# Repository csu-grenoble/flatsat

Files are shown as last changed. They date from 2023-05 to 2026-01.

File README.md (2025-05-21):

# Easy-Space Flatsat  📡 🚀 extensions

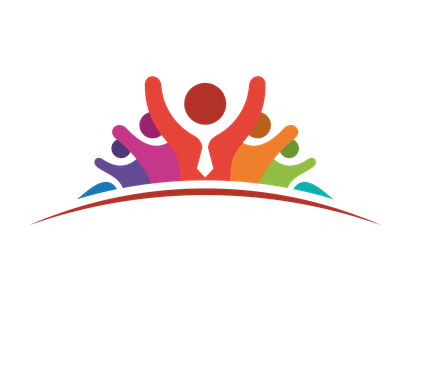
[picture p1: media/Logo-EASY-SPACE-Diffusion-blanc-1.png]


Extensions to [Easy Space](https://www.easy-space.fr/) INISAT flatsat mockup

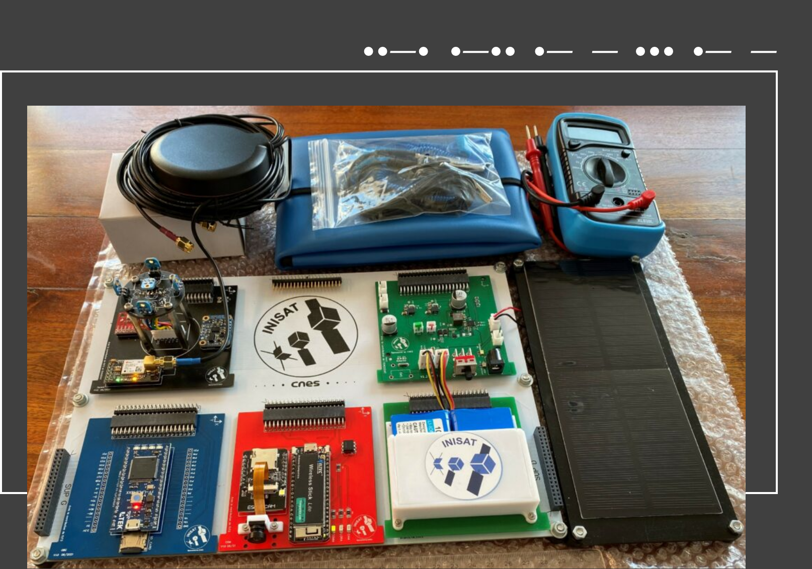
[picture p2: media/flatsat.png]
mockup

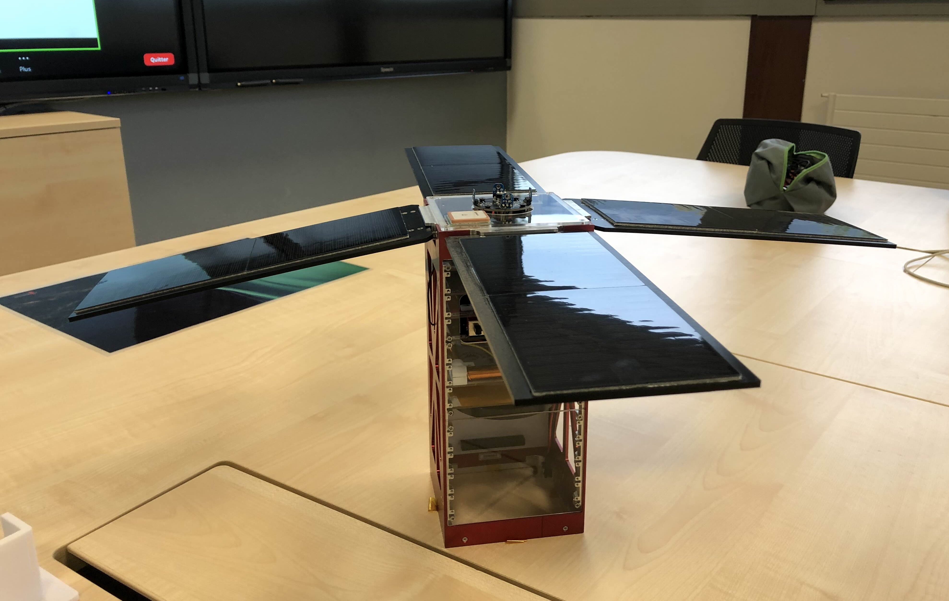
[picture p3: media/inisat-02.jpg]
cubesat 2U


## [Board #1: ThingSat @ INISAT](Hardware/Thingsat_INISAT)  📡 🚀 (OBC + LoRa Gateway + CAN Bus)

* 1x [ST Nucleo L432KC](https://www.st.com/en/evaluation-tools/nucleo-l432kc.html)
* 1x [RAK Wireless RAK5146 (all bands)](https://store.rakwireless.com/products/wislink-concentrator-module-sx1303-rak5146-lorawan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)
* 1x Mikrobus slots for homebrew LoRa click boards (Lambda80, GNSS RTK) or [others click boards](https://www.mikroe.com/shop)
* 3x [Groove connectors](https://wiki.seeedstudio.com/Grove_System/)
* 1x [ST L9616 Automotive High Speed Can Bus Transceiver](https://www.st.com/en/automotive-analog-and-power/l9616.html)
  
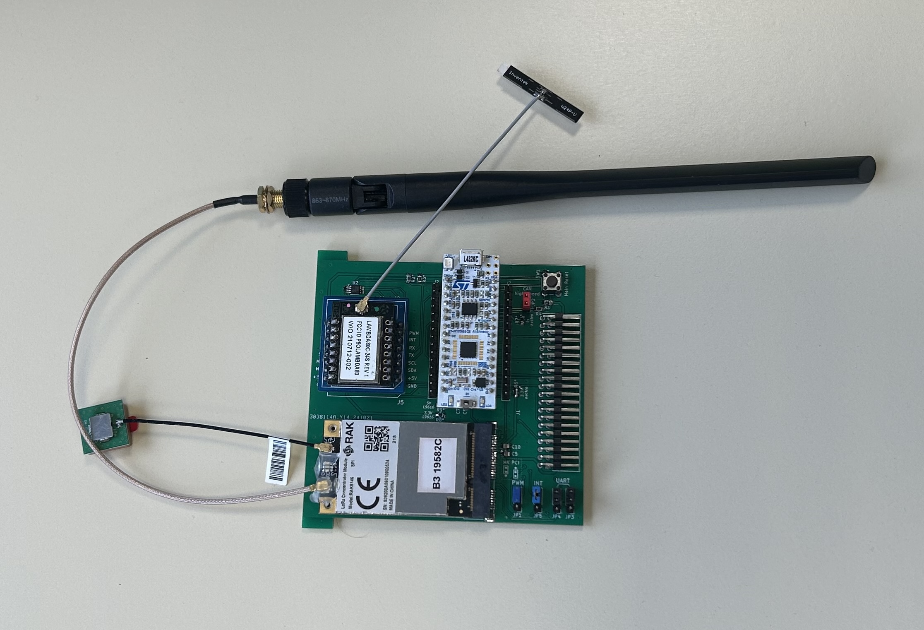
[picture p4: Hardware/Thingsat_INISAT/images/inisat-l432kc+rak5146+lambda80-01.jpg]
OBC + RAK5146 board for INISAT


## [Board #2 ESP32 TinyGS](Hardware/2U-PCB-TinyGS)

* 1x [ESP32 Wroom](https://www.espressif.com/en/products/devkits)
* 2x Mikrobus slots for homebrew LoRa click boards (Lambda80, RN2483) or [others click boards](https://www.mikroe.com/shop)
* 6x [Groove connectors](https://wiki.seeedstudio.com/Grove_System/)
* 1x [ST L9616 Automotive High Speed Can Bus Transceiver](https://www.st.com/en/automotive-analog-and-power/l9616.html)

See [TinyGS 2G4 Station](https://github.com/thingsat/tinygs_2g4station)

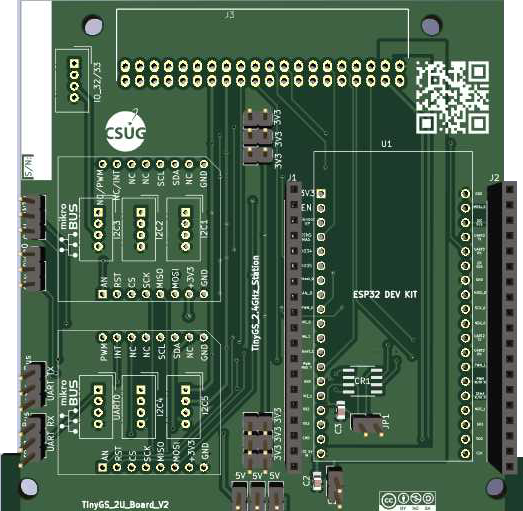
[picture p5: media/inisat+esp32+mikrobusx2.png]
ESP32 Wroom + 2x Mikrobus Slots


## Board #3 Nucleo L476RG

* 1x [Nucleo L476RG](https://www.st.com/en/evaluation-tools/nucleo-l476rg.html)
* 1x [ST L9616 Automotive High Speed Can Bus Transceiver](https://www.st.com/en/automotive-analog-and-power/l9616.html)

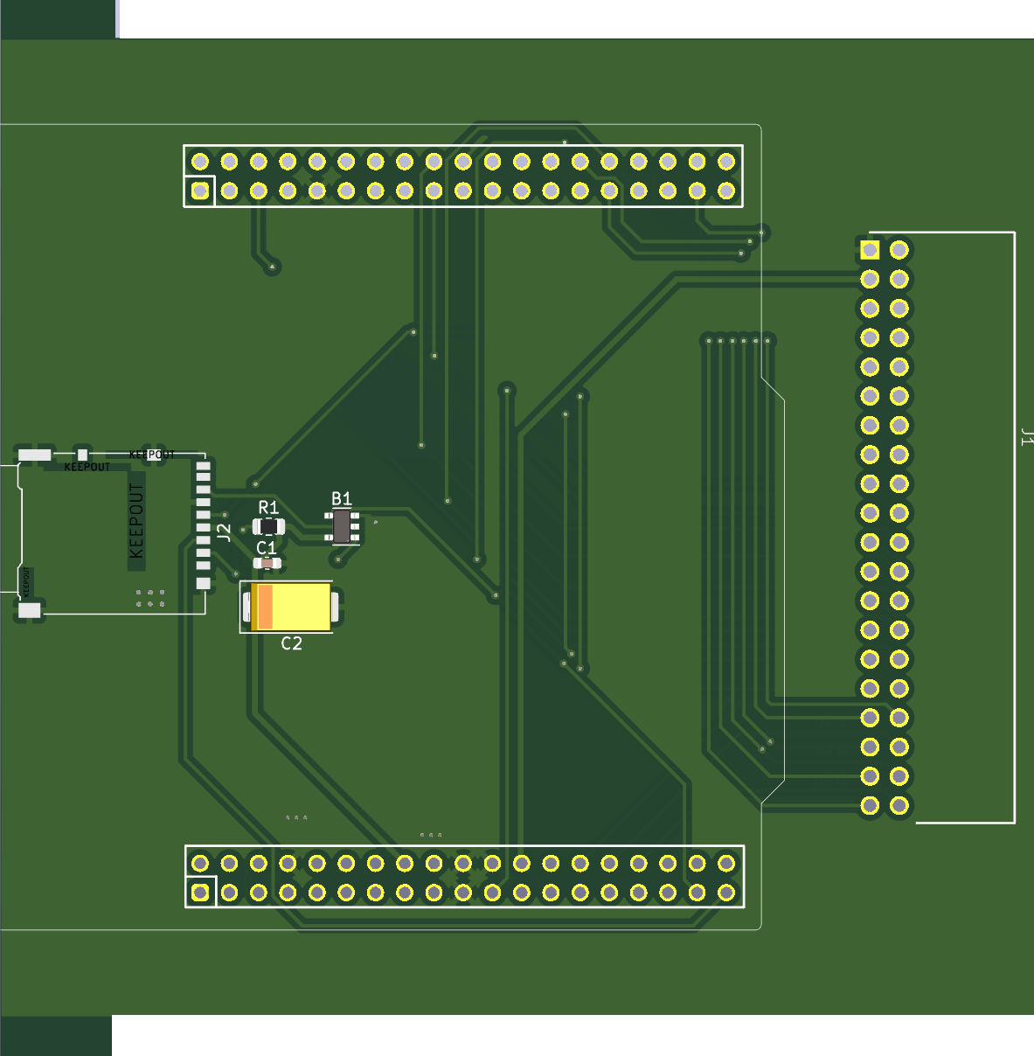
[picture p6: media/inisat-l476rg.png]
OBC


## References

* [EasySpace Diffusion](https://github.com/EasySpace-Diffusion)
* [TinyGS 2G4 Station](https://github.com/thingsat/tinygs_2g4station)

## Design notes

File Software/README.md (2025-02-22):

# Firmwares for INISAT 📡 🚀 boards

## ThingSat @ INISAT 📡 🚀 (Nucleo L432KC + RAK 5146)

* [Arduino](./arduino)
* [MBed](./mbed)
* [STM32 Cube](./cube)
* [RIOT OS](./riot)

## TinyGS

* See [tinygs_2g4station](https://github.com/thingsat/tinygs_2g4station/tree/main/Firmware)

## References

* https://github.com/EasySpace-Diffusion

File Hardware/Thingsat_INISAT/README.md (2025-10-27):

# **Carte Thingsat @ INISAT 📡 🚀 : OBC + Communication avec Nucleo L432KC + Gateway RAK5146**

La carte [Thingsat](https://gricad-gitlab.univ-grenoble-alpes.fr/thingsat/public/-/blob/master/README.md?ref_type=heads) @ INISAT a pour but de fonctionner comme un OBC qui peut se relier à l'environnement INISAT grace au header standardisé. 

Cette carte fonctionne également comme une carte de communication avancée LoRa/FSK avec l'ajout d'un module [gateway LoRa (+ GNSS) au format mini-PCIe](https://www.mikroe.com/mikrobus) comme le module [RAK5146](../../Hardware/sx1302_modules).

> Remarque: D'autres modules gateways LoRa avec ou sans module GNSS sont compatibles avec la carte. Voir la [liste](../../Hardware/sx1302_modules).

Cette carte peut accueillir un module MikroBus qui peut accueillir des platines de l'[écosystème Mikrobus](https://www.mikroe.com/mikrobus).

Cette carte peut accueillir trois platines Grove I2C situés sous le module mini-PCIe .

La carte [Thingsat](https://gricad-gitlab.univ-grenoble-alpes.fr/thingsat/public/-/blob/master/README.md?ref_type=heads) @ INISAT peut être utilisée seule (standalone) pour des expérimentations à bord de [ballons stratosphériques](https://gricad-gitlab.univ-grenoble-alpes.fr/thingsat/public/-/blob/master/balloons/README.md).



## Schématique

[Schematic](schematic.pdf)

## Firmware

Le firmware avec RIOT OS est disponible [ici](../../Software/riot).

Le firmware avec [ici](../../Software/arduino) est à l'étude.

## Montages

La carte peut être montée en deux versions:

**Carte avec 1 connecteur mini-PCI-Express (pour accueillir un concentrateur LoRa) et 1 support Mikrobus**

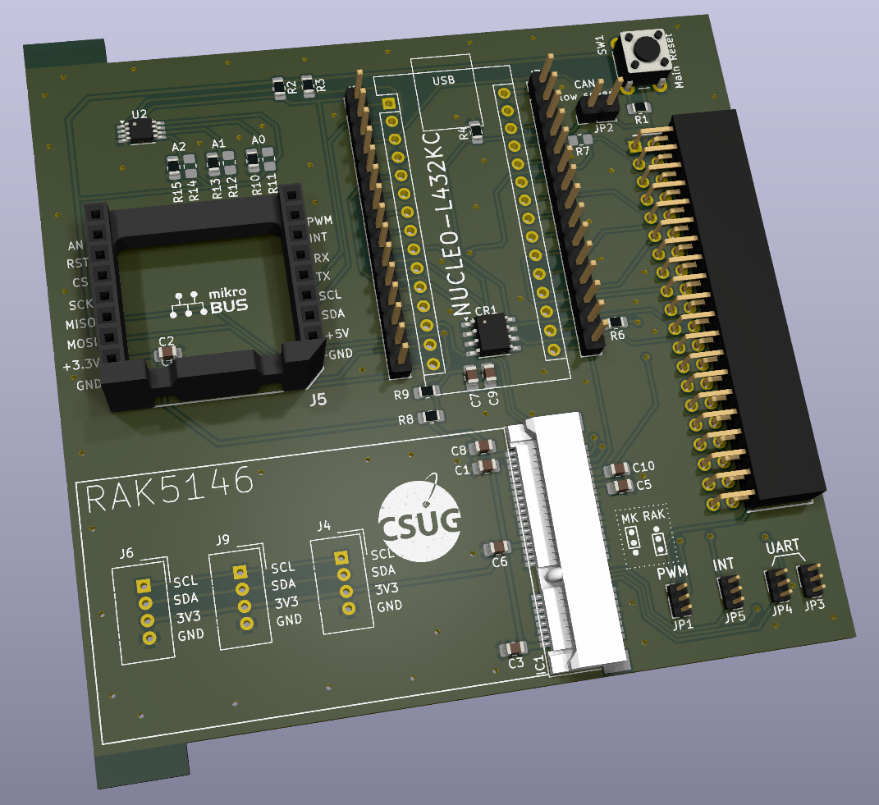
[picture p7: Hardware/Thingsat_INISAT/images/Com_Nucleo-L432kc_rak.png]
Carte Com Nucleo RAK


**Carte avec 3 connecteurs Grove et 1 support Mikrobus**

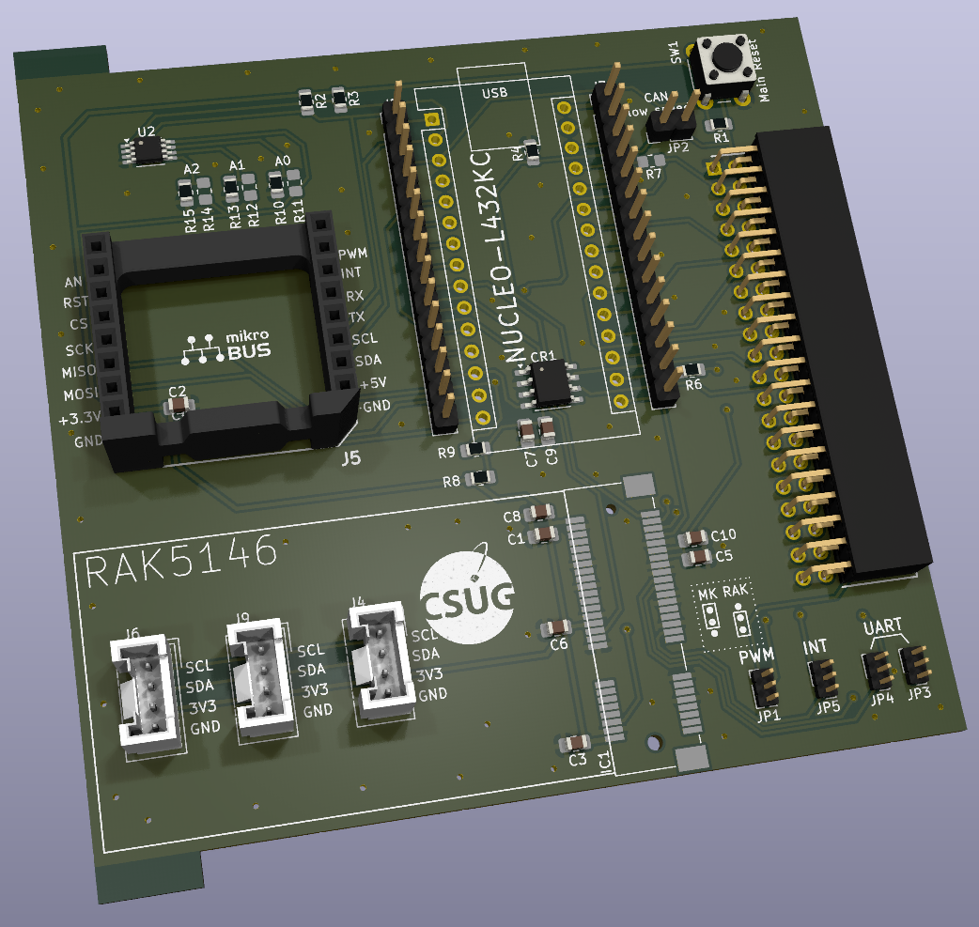
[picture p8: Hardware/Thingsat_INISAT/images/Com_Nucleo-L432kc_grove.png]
Carte Com Nucleo Grove


## OpenLog

Pour journaliser la console d'exécution du firmware de la carte Nucleo L432KC, vous pouvez ajouter une [platine OpenLog](https://github.com/CampusIoT/tutorial/tree/master/openlogger) sur les headers externes de la carte.

| OpenLog | Nucleo L432KC |
| --- | --- |
| `3V3` | `3V3` (et non `VIN`) |
| `GND` | `GND` |
| `RXI` | `A7` (aka `UART2_TX`) | 

> NB: il est recommandé que le port console soit configuré à 9600 bauds pour éviter la perte de caratères lors de l'écriture sur la carte SD. Pour les firmwares avec RIOT OS, il faut redéfinir dans le Makefile `STDIO_UART_BAUDRATE` avec `CFLAGS += -DSTDIO_UART_BAUDRATE=9600`

## Description de la carte
La carte est equipée de:

 - Un emplacement pour carte **Nucleo-32** (ou arduino nano)
 - Un emplacement **MikroBus**
 - Un connecteur **mini-PCI-Express** OU 3 connecteurs **Grove** I2C (en fonction de la version de la carte)
 - Un connecteur **Inisat** (pour se raccorder aux autres cartes de l'ecosystème Inisat)
 - Un **transceiver CAN** ([L9616](https://www.st.com/en/automotive-analog-and-power/l9616.html) - STMicroelectronics)
 - Un **capteur de température** I2C ([MCP9808](https://www.microchip.com/en-us/product/mcp9808#document-table) - Microchip)

## Nucleo 32 (L432KC)

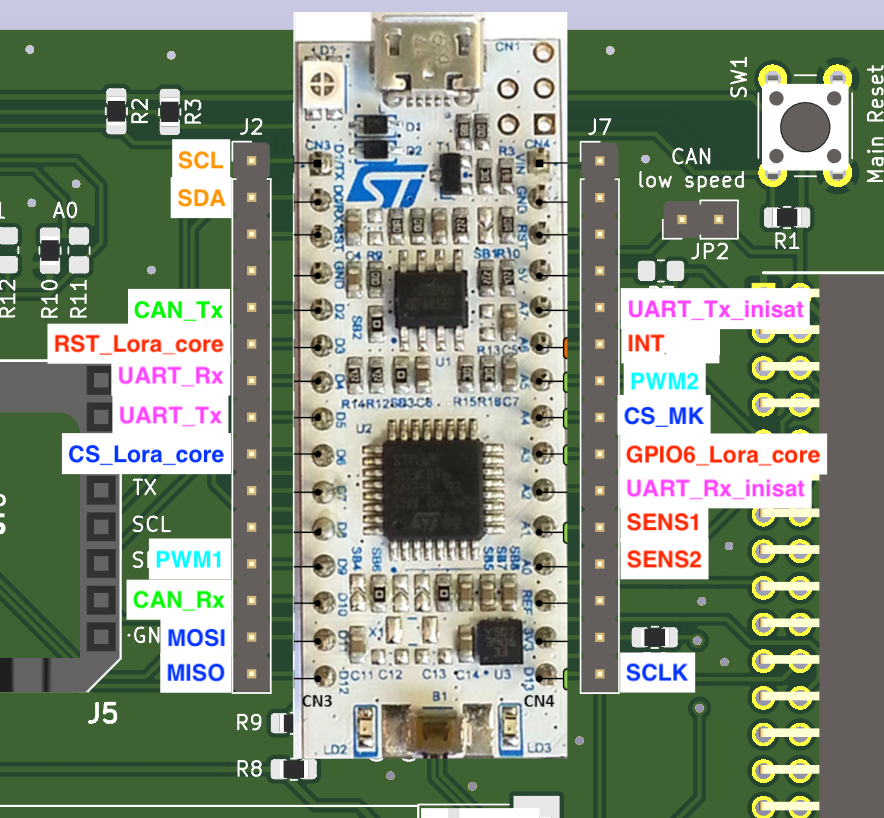
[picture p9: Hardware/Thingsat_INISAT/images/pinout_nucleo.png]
pinout nucleo


## Emplacement MikroBus

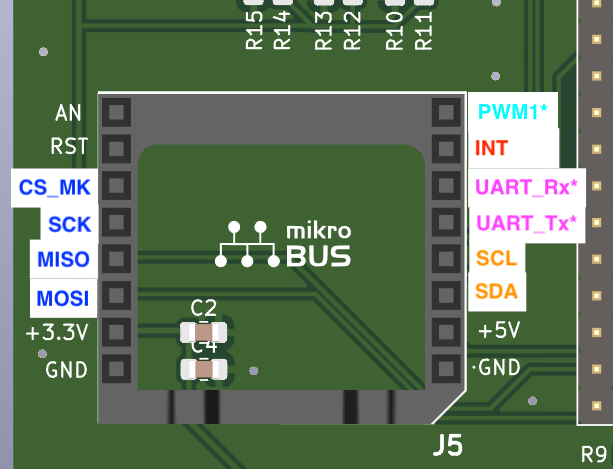
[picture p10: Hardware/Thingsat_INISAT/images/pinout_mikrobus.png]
pinout Mikrobus


## Connecteur mini PCI Express

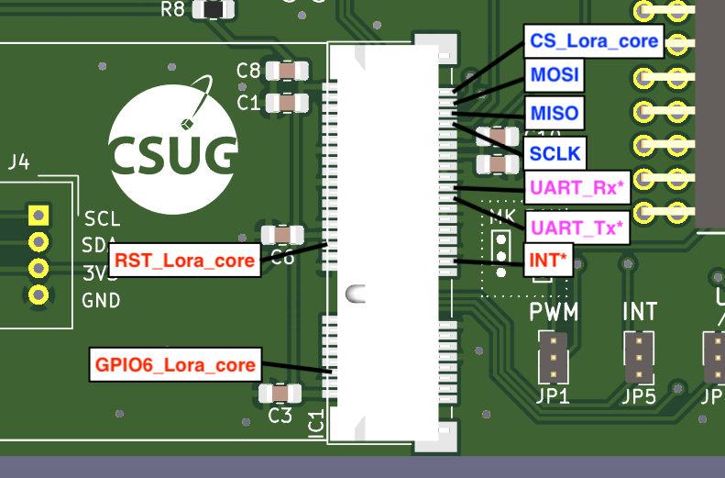
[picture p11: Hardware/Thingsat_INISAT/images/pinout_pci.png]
pinout PCI


## [Modules SX1302/3 compatibles](../sx1302_modules)

* [x] RAK5146 Gateway Concentrator Module for LoRaWAN SPI
* [ ] RAK2287 WisLink LPWAN Concentrator SPI (to test)
* [x] Nebra NBR-0094
* [x] Seeedstudio Wio-WM1303 Long Range Gateway Module
* [ ] Seeedstudio Wio-WM1302 Long Range Gateway Module  (to test)
* [ ] Heltec HT1303  (to test)

## Jumpers de selection des signaux

Les signaux marqués d'une étoile sur les diagrammes sont partagées entre plusieurs empreintes.
Pour pouvoir utiliser ces signaux il faut donc les "router" vers l'emplacement dont on veut se servir en plaçant correctement les jumpers en bas à droite de la carte.

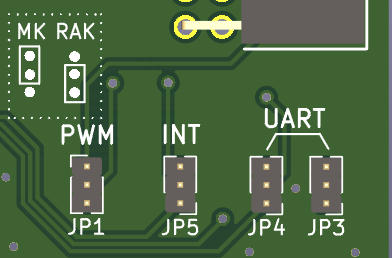
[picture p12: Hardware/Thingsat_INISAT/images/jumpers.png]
Selection jumpers


- PWM1 : 
	- position haute: `PWM Mikrobus` 	(pin 8 de l'empreinte Mikrobus)
	- position basse: `PWM Inisat` 		(pin 6 du connecteur Inisat)
	
- INT :
	- position haute: `INT Mikrobus` 	(pin 7 de l'empreinte Mikrobus)
	- position basse: `PPS Lora core` 	(pin 19 du connecteur mini PCI Express)
	
- UART (Rx et Tx) :
	- position haute: `UART Mikrobus` 	(pin 5 et 6 de l'empreinte Mikrobus)
	- position basse: `UART GPS Lora core` (pin 31 et 33 du connecteur mini PCI Express)

## Transceiver CAN

Le transceiver CAN peut être configuré pour opérations à hautes vitesses (> 250KBaud/s) ou à basse vitesse (< 250KBaud/s).
Pour positionner le transceiver en mode haute vitesse, il faut placer un jumper sur le connecteur `JP2`.

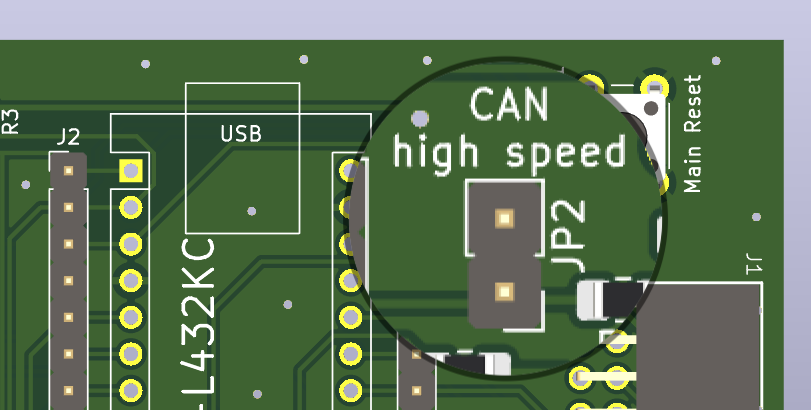
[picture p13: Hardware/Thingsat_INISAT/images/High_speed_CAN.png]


## Capteur de temperature [MPC9808](https://www.microchip.com/en-us/product/mcp9808#document-table)

L'adresse i2c du capteur de température est définie comme suit : `0b 0 0 1 1 A2 A1 A0`
les bits de poids faibles A2,A1 et A0 sont définis en plaçant des résistances 0 Ohms (_il ne faut donc placer qu'une seule résistance pour chaque bit_): 
 
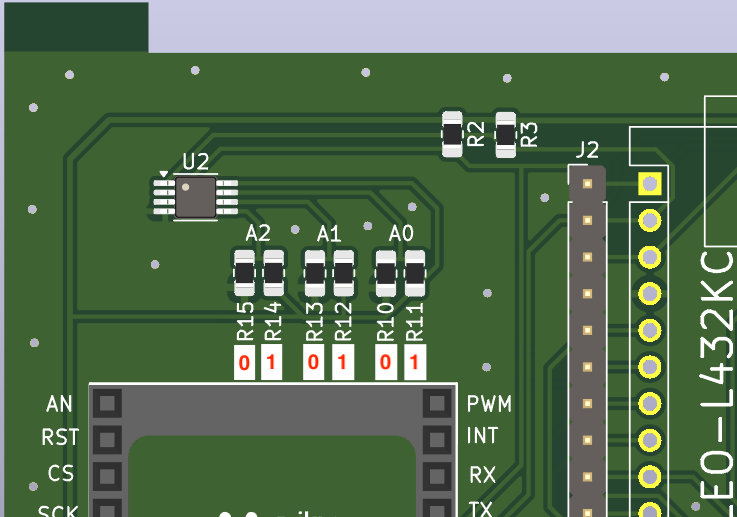
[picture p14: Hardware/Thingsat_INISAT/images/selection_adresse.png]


## Modularité de la carte

Les composants entourés d'un rectangle en pointillé ne doivent pas necessairement être montées. Cela dépend de l'usage de la carte. Voici les composants concernés:

* Alimentation Nucleo
	* `R7`: alimentation de la nucleo en 5V (_nécessaire si la carte Inisat est utilisé seule **ET** que l'on a besoin d'utiliser le 5V pour le Mikrobus_)
	* `R6`: alimentation de la nucleo en 3.3V (_nécessaire si la carte Inisat est utilisé seule_)
* Alimentation Transceiver CAN
	* `R9`: alimentation L9616 en 5V
	* `R8`: alimentation L9616 en 3.3V (_par défaut_)
* Selection adresse i2c capteur de temperature (`R10`-`R15`)
	* [voir ci-dessus](#capteur-de-temperature)

# Contributeurs

* Léo CORDIER (Design PCB + montage)
* Vincent Grennerat (Design PCB)
* Didier Donsez (firmware de test)
* [Lucas ORLANDO BERNARDES](https://www.linkedin.com/in/lucas-orlando-bernardes-1b7397256/) (initial design)

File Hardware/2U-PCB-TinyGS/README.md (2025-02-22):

# INISAT Board for TinyGS 2.4GHz Station

This board is the firts version of the [LoRa 2.4GHz gateway](https://github.com/thingsat/tinygs_2g4station) for [TinyGS](https://tinygs.com/).

Contain Schematic and PCB file for ESP32 Vroom + 2 Mikrobus modules + 2 groves connectors (RXTX,I2C).

This Board is designed to support a ESP32 devkitC-V4 and 2 MiKroBus modules. This board is the firts version of the 2.4GHz tinygs ground station gateway and named Board_V2

The purpose of this board is to control mikrobus modules including SX1280 technology that will transmit and receive messages on a 2.4GHz radio frequency. Each module are connected to a ESP32 which will be connected to the wifi.

Mikrobus board is an add-on board socket standard made by [mikroe](https://www.mikroe.com/mikrobus)

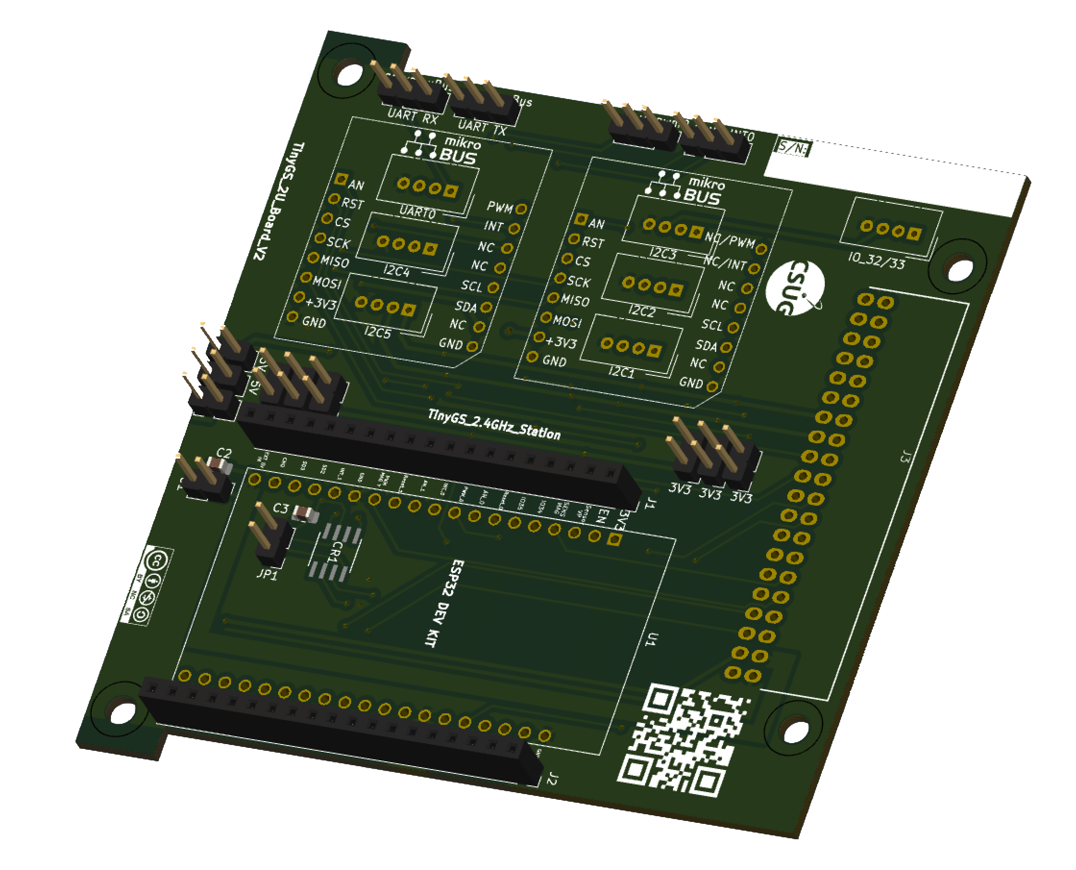
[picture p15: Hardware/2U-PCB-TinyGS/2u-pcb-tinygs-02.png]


## Pinout

Connection between ESP32 - ESP32-DevKitC V4 and Mikrobus modules

MiKroBus 0:
	 				 
	SPI_0:
	CLK 	IO18
	MISO	IO19
	MOSI	IO23
	NSS(CS)	IO05
	
	UART_0	:
	Tx	NC
	Rx	NC
	
	I2C:
	SDA	IO21
	SCL	IO22
	
	AN_0	IO33
	RESET_0 IO32
	PWM_0	IO25
	INT_0	IO26

MiKroBus 1: 				 
	
	SPI_0
	CLK 	IO18
	MISO	IO19
	MOSI	IO23
	NSS 	IO15
	
	UART_2
	Tx	IO17
	Rx	IO16
	
	I2C:
	SDA	IO21
	SCL	IO22
	
	AN_1	IO27
	RESET_1 IO14
	PWM_1	IO04
	INT_1	IO13

Grove connector available on board :

	I2C:			UART_2(Rx/Tx):		GPIO(INPUT Only):
	SDA   IO21		Tx	IO17		IO34
	SCL   IO22		Rx	IO16		IO35

UART_2 can be connected to module MiKroBus 2 or to grove connector. A jumper need to be plug to choose beetween grove output or the mikrobus module.

Two UFL connected to a SMA mount edge connector are available to plug an antenna. They are disconnected from the rest of the board, which allows to connect the module that you want to the antenna, with a SMA -UFL connector.

A powerbank can be plug under the board to supply the 3V. The [powerbank](https://www.amazon.com/Diymore-Lithium-Battery-Charging-Arduino/dp/B07SZKNST4) is design for ESP32 and is purchasable on amazon. 
5V is only available on the Mikrobus 1 module. 

Careful:
* UART0 is used for flashing and debuging. Be very careful to its use.
* GPIO grove connector are INPUT only, ESP32wroom cannot write on this connection.
* Both Chip selec (NSS) for the SPI communication are Pulled HIGH (IO05 & IO15).
* No 5V on Mikrobus 0. 

## Library and footprint

Lib & empreinte folder contains all necessary symbol and footprint for the project:
* ESP32 symbol and footprint. Footprint has been changed to match with our ESP32-devkitC-V4
* Mikrobus (mikroe-2439) symbol and footprint
* Grove connector for I2C and RxTx connection
* SMA and UFL connector

## Files

* .pro: File containing the parameters of the project.
* .sch: Schema files.
* .kicad_pcb: Printed circuit board files.
* sym-info-cache: Library list file (symbol library table): declaration of component symbol libraries available for the schema editor.
* fp-lib-table: Library list file (footprint library table): declaration of component footprint libraries available for the PCB editor.

## Contributors

* Didier DONSEZ
* [Samuel Barnola](https://www.linkedin.com/in/samuel-barnola-816354281/) ([initial design](https://github.com/thingsat/tinygs_2g4station))
* [Lucas ORLANDO BERNARDES](https://www.linkedin.com/in/lucas-orlando-bernardes-1b7397256/)

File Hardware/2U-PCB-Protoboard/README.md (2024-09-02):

# Protoboard for INISAT

Include footprint for SO-8 CAN driver ([ST L9616](https://www.st.com/resource/en/datasheet/l9616.pdf))

See [Protoboard Module Kit](https://www.pumpkinspace.com/store/p50/Protoboard_Module_Kit.html)

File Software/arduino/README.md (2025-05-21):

# Firmwares (skeches) with Arduino IDE

[Getting Started](https://github.com/stm32duino/Arduino_Core_STM32?tab=readme-ov-file#getting-started)

Choose `Tools` > `Board` > `STM32 Boards (selected from submenu` > `Nucleo 32`

Choose  `Tools` > `Board Part Number:` > `Nucleo L432KC`

## GNSS module (UART and I2C)

## Sensors (on Sensors board)

* [Bosch Sensortec BNO055](https://www.bosch-sensortec.com/products/smart-sensor-systems/bno055/) [lib](https://search.arduino.cc/search?q=bno055)
* [NXP MPL3115A2](https://www.nxp.com/docs/en/data-sheet/MPL3115A2.pdf) [lib](https://search.arduino.cc/search?q=MPL3115A2)
* [ADS1015](https://www.ti.com/product/ADS1015) [lib](https://search.arduino.cc/search?q=ADS1015)
* [GNSS uBlox Neo M8N](https://www.u-blox.com/en/product/neo-m8-series) [lib](https://www.arduino.cc/reference/en/libraries/neogps/)

## CAN Bus ([ST L9616 CAN Driver](https://www.st.com/en/automotive-analog-and-power/l9616.html))

* [STM32_CAN](https://www.arduino.cc/reference/en/libraries/stm32_can/)

## LoRa gateway ([RAK5146 SPI + GPS module](https://store.rakwireless.com/products/wislink-concentrator-module-sx1303-rak5146-lorawan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))

* [SX1302 driver](https://github.com/will127534/SX1302_Arduino_Library)

## Utils
* [AioP13 library : "Another implementation of PLAN-13" library)](https://github.com/dl9sec/AioP13)

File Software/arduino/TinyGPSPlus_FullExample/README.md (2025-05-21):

# TinyGPS++ :: Full Example

The purpose of this example is the test of the communication of the ESP32 Wroom with a GPS module using the NMEA 0183 protocol.

This example requires the importation of two libraries into the Arduino IDE
* https://codeload.github.com/plerup/espsoftwareserial/zip/refs/heads/main
* https://codeload.github.com/mikalhart/TinyGPSPlus/zip/refs/heads/master

## Wiring

Warning: The default baudrate for [Grove-GPS](https://wiki.seeedstudio.com/Grove-GPS/) SIM28 is 9600. Check baudrates for [other common GNSS modules](https://github.com/CampusIoT/orbimote/blob/master/gnss_modules.md).

### Wiring for Grove GPS
The example has been tested with the [Grove-GPS](https://wiki.seeedstudio.com/Grove-GPS/) plugged into the UART Grove connector of the TinyGS 2G4 station.

This module is connected to the UART2 with the following wiring:

	White	<->	pin 16	(Rx ESP / Tx Module)
	Yellow 	<->	pin 17  (Tx ESP / Rx Module)
	Red 	<->	3.3V
	Black	<->	GND

### Wiring for XA1110 Mikrobus on Mikrobus 1

The example has been tested with the [SparkFun GPS Breakout - XA1110](https://learn.sparkfun.com/tutorials/sparkfun-gps-breakout---xa1110-qwiic-hookup-guide) plugged into the Mikrobus slot of the Thingsat @ INISAT.

This module is connected to the UART2 with the following wiring:

## Build

Set the baudrate of the module

```c
...
static const uint32_t GPSBaud = 9600;
...
```

Set the coordinates of your POI (Point of Interest)

```c
...
static const double POI_LAT = 45.19262400425433, POI_LON = 5.759966075632675;
...
```

> For debugging baudrate, you can display the raw NMEA sentences by setting `DISPLAY_NMEA0183_SENTENCES` to `1` into the sketch.

```c
...
#define DISPLAY_NMEA0183_SENTENCES    1
...
```

> For removing the GNSS data baudrate, set `DISPLAY_GNSS_LINES` to `0` into the sketch.

```c
...
#define DISPLAY_GNSS_LINES    0
...
```

## Flash and Run

Configure the board `ESP32 Dev Module` and the port in `Tools`.

Compile the sketch `Sketch > Verify/Compile`

Upload the sketch `Sketch > Upload` on the board

Open the serial monitor `Tools > Serial monitor`

with `DISPLAY_NMEA0183_SENTENCES=1`
```
FullExample.ino
An extensive example of many interesting TinyGPS++ features
Testing TinyGPS++ library v. 1.0.2
by Mikal Hart

$PGACK,EPE,H=24.094191,V=17.598621*39
$GNGGA,173207.000,4510.940888,N,00544.128851,E,1,5,2.81,202.417,M,48.532,M,,*41
$GPGSA,A,3,08,02,04,,,,,,,,,,2.98,2.81,1.00*05
$GLGSA,A,3,84,71,,,,,,,,,,,2.98,2.81,1.00*1D
$GPGSV,3,1,11,01,80,008,18,03,66,261,,02,61,104,33,17,35,308,17*78
$GPGSV,3,2,11,08,24,172,23,32,24,045,,04,17,186,30,22,16,291,*76
$GPGSV,3,3,11,14,13,270,,28,10,086,16,31,04,111,*4E
$GLGSV,2,1,08,85,78,042,,70,75,183,,84,33,120,28,69,33,035,*69
$GLGSV,2,2,08,86,29,318,,71,26,204,33,77,07,332,,76,03,290,*6A
$GNRMC,173207.000,A,4510.940888,N,00544.128851,E,0.58,146.63,070425,,,A*78
$GNVTG,146.63,T,,M,0.58,N,1.07,K,A*2E
$PGACK,EPE,H=24.028019,V=17.599386*36
$GNGGA,173208.000,4510.940632,N,00544.129264,E,1,5,2.81,202.387,M,48.532,M,,*42
$GPGSA,A,3,08,02,04,,,,,,,,,,2.98,2.81,1.00*05
$GLGSA,A,3,84,71,,,,,,,,,,,2.98,2.81,1.00*1D
$GNRMC,173208.000,A,4510.940632,N,00544.129264,E,0.78,146.63,070425,,,A*77
$GNVTG,146.63,T,,M,0.78,N,1.45,K,A*2A
```

with `DISPLAY_GNSS_LINES=1`
```
FullExample.ino
An extensive example of many interesting TinyGPS++ features
Testing TinyGPS++ library v. 1.0.2
by Mikal Hart

Sats HDOP  Latitude   Longitude   Fix  Date       Time     Date Alt    Course Speed Card  Distance Course Card  Chars Sentences Checksum
           (deg)      (deg)       Age                      Age  (m)    --- from GPS ----  ----  to POI    ----  RX    RX        Fail
----------------------------------------------------------------------------------------------------------------------------------------
**** ***** ********** *********** **** ********** ******** **** ****** ****** ***** ***   ******** ****** ***   0     0         0        
0    0.0   ********** *********** **** 01/06/2080 00:30:22 394  ****** ****** ***** ***   ******** ****** ***   236   0         0        
...
5    2.8   45.183380  5.735302    559  04/07/2025 17:35:16 559  191.21 146.63 0.43  SSE   2        59.73  ENE   329   2         0        
5    2.8   45.183380  5.735305    215  04/07/2025 17:35:17 215  191.07 146.63 0.46  SSE   2        59.72  ENE   983   4         0        
5    2.8   45.183380  5.735305    562  04/07/2025 17:35:18 562  190.95 146.63 0.26  SSE   2        59.72  ENE   1312  6         0        
5    2.8   45.183384  5.735300    555  04/07/2025 17:35:19 555  190.86 146.63 0.09  SSE   2        59.74  ENE   1641  8         0        
5    2.8   45.183387  5.735298    563  04/07/2025 17:35:20 563  190.77 146.63 0.15  SSE   2        59.75  ENE   1970  10        0        
5    2.8   45.183387  5.735298    563  04/07/2025 17:35:21 563  190.66 146.63 0.30  SSE   2        59.75  ENE   2299  12        0        
5    2.8   45.183387  5.735303    222  04/07/2025 17:35:22 222  190.54 146.63 0.13  SSE   2        59.74  ENE   2955  14        0        
5    2.8   45.183387  5.735305    566  04/07/2025 17:35:23 566  190.44 146.63 0.13  SSE   2        59.74  ENE   3284  16        0        
5    2.8   45.183384  5.735311    569  04/07/2025 17:35:24 569  190.32 146.63 0.13  SSE   2        59.72  ENE   3613  18        0        
5    2.8   45.183380  5.735319    569  04/07/2025 17:35:25 569  190.20 146.63 0.22  SSE   2        59.71  ENE   3942  20        0        
```

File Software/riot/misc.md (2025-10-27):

# INISAT Nucleo L432KC + RAK 5146 :: Misc

## ADC channels : VBat and TS

* https://community.st.com/t5/stm32-mcus-products/adc-is-weird-too/td-p/120816

* https://doc.riot-os.org/group__drivers__periph__vbat.html

## NanoPB

## [AioP13 library : "Another implementation of PLAN-13" library]

cd ~/thingsat/riot_modules/modules/aiop13

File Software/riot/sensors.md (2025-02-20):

# INISAT Nucleo L432KC + RAK 5146 :: Sensors

[Installation et configuration](install.md)

## I2C Scan

```bash

```

## SAUL

```bash

```

## [MPC9808](https://www.microchip.com/en-us/product/mcp9808#document-table) temperature sensor (on board)

## [ADS1115](https://www.ti.com/product/ADS1115) external

[driver](https://doc.riot-os.org/group__drivers__ads101x.html)

```bash

```

## Sensors (on Sensors board) Mikrobus ou Grove

* [Bosch Sensortec BNO055](https://www.bosch-sensortec.com/products/smart-sensor-systems/bno055/) [lib](https://search.arduino.cc/search?q=bno055)
* [NXP MPL3115A2](https://www.nxp.com/docs/en/data-sheet/MPL3115A2.pdf) [driver]([https://search.arduino.cc/search?q=MPL3115A2](https://doc.riot-os.org/group__drivers__mpl3115a2.html))
* [GNSS uBlox Neo M8N](https://www.u-blox.com/en/product/neo-m8-series) [pkg](https://doc.riot-os.org/group__pkg__minmea.html)

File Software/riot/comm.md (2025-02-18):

# INISAT Nucleo L432KC + RAK 5146 :: Communication

[Installation et configuration](install.md)

## Module gateway LoRa RAK5146

```bash
cd ~/github/thingsat/riot_modules/tests/driver_sx1302
make SX1302_LIB_VERSION=2_1_0 flash term
```

```console
help
lgw
lgw start
lgw eui
lgw listen
lgw bench
lgw bench 10 7 125 8 14 on false 20 2000
```

## Module GNSS de la gateway LoRa RAK5146

TODO

## Module Lambda80 SX1280 LoRa 2.4 GHz

```bash
cd ~/github/thingsat/riot_modules/tests/driver_sx1280
make flash term
```

## CAN Bus ([ST L9616 CAN Driver](https://www.st.com/en/automotive-analog-and-power/l9616.html))

* [conn_can](https://github.com/RIOT-OS/RIOT/tree/master/tests/sys/conn_can)

## LibCSP

TODO

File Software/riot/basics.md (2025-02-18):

# Premiers pas avec la carte INISAT Nucleo L432KC + RAK 5146

Dans ce chapitre, vous apprendrez à utiliser les fonctions de base offertes par RIOT pour la plupart des MCU STM32.

[Installation et configuration](install.md)

## LED
Construisez le firmware avec la commande suivante:
```bash
cd ~/github/RIOT-OS/RIOT/tests/leds
make -j 4
```

## Shell

Construisez le firmware avec la commande suivante:
```bash
cd ~/github/RIOT-OS/RIOT/tests/shell
make -j 4
```

Exercice: la commande `make` affiche les lignes suivantes. A quoi correspondent les [valeurs `text`, `data`, `bss`, `dec` et `hex` ?](https://mirzafahad.github.io/2021-05-08-text-data-bss/)
```
   text	   data	    bss	    dec	    hex	filename
  17124	    132	   1912	  19168	   4ae0	~/github/RIOT-OS/RIOT/tests/shell/bin/nucleo-l432kc/test-shell.elf
```

<details>
<summary>Réponse</summary>
En un mot:
<ul>
<li>‘text’ est votre code et vos constantes (et aussi la table de vecteurs).</li>
<li>‘data’ concerne les variables initialisées. Cela compte à la fois pour la RAM et le FLASH. La valeur initialisée alloue de l'espace dans FLASH qui est ensuite copié de la ROM vers la RAM dans le code de démarrage.</li>
<li>‘bss’ concerne les données non initialisées dans la RAM qui sont initialisées avec zéro dans le code de démarrage.</li>    
</ul>
</details>

Regardez les fichiers produits:
```bash
cat bin/$BOARD/riotbuild/riotbuild.h
ls -al bin/$BOARD
file bin/$BOARD/test-shell.*
```

* Le fichier `.elf` est un fichier binaire contenant le firmware et des informations sur celui-ci. [En savoir plus.](https://gist.github.com/x0nu11byt3/bcb35c3de461e5fb66173071a2379779)
* Le fichier `.bin` est un fichier binaire contenant le firmware qui est écrit dans la mémoire Flash du STM32L151 à l'adresse `0x08000000` par `openocd`.

Chargez le binaire `.bin` dans la mémoire Flash (adresse `0x08000000`) du STM32L151 avec la commande suivante.
```bash
make flash-only
```

> Note: la commande `make -j 4 flash` enchaine les commandes `make -j 4` puis `make flash-only`

<details>
<summary>Console (tio)</summary>
<pre>
main(): This is RIOT! (Version: 2023.07-devel-325-g2863d)
test_shell.
> help
Command          	Description
---------------------------------------
bufsize          	Get the shell's buffer size
start_test       	starts a test
end_test         	ends a test
echo             	prints the input command
empty            	print nothing on command
app_metadata     	Returns application metadata
pm               	interact with layered PM subsystem
ps               	Prints information about running threads.
reboot           	Reboot the node
version          	Prints current RIOT_VERSION
xfa_test1        	xfa test command 1
xfa_test2        	xfa test command 2
> ps
    pid | name             	| state	Q | pri | stack  ( used) ( free) | base addr  | current	 
      - | isr_stack        	| -    	- |   - |	512 (  172) (  340) | 0x20000000 | 0x200001c8
      1 | main             	| running  Q |   7 |   1024 (  536) (  488) | 0x20000398 | 0x2000071c
    	| SUM              	|        	| 	|   1536 (  708) (  828)
> bufsize
60
> pm
Usage:
    pm show: display current blockers for each power mode
    pm set <mode>: manually set power mode (lasts until WFI returns)
    pm block <mode>: manually block power mode
    pm unblock <mode>: manually unblock power mode
    pm off: call pm_off()
> pm show
mode 0 blockers: 1
mode 1 blockers: 2
mode 2 blockers: 0
Lowest allowed mode: 2
> app_metadata
{"cmd": "app_metadata_print_json()"}
{"data": {"APP_NAME": "test-shell"}}
{"data": {"BOARD": "nucleo-l432kc-init"}}
{"data": {"CPU": "stm32"}}
{"data": {"APP_SHELL_FMT": "NONE"}}
{"data": {"MCU": "stm32"}}
{"data": {"OS_VERSION": "2023.07-devel-325-g2863d"}}
{"result": "SUCCESS"}
> ps
	pid | name                 | state    Q | pri | stack  ( used) ( free) | base addr  | current     
	  - | isr_stack            | -        - |   - |    512 (  172) (  340) | 0x20000000 | 0x200001c8
	  1 | main                 | running  Q |   7 |   1024 (  536) (  488) | 0x20000398 | 0x2000071c 
	    | SUM                  |            |     |   1536 (  708) (  828)
> reboot
main(): This is RIOT! (Version: 2023.07-devel-325-g2863d)
test_shell.
>
</pre>
</details>

Exercice: Qu'affiche la commande `ps` ?

<details>
<summary>Réponse</summary>
La commande `ps` affiche les threads qui sont créés. Elle donne les tailles des piles (stack) des threads.

`isr_stack` n'est pas une thread (pas de pid) : `isr_stack` représente la pile d'exécution des traitants d'interuption, timers ...
</details>

Que se passe t'il quand la taille de la pile du thread est sous-dimensionnée ?

Essayez la commande suivante:
```bash
make CFLAGS+=-DTHREAD_STACKSIZE_MAIN=512U flash
```

Que se passe t'il ?

## Erreurs au moment de l'installation

hla_swd
Info : The selected transport took over low-level target control. The results might differ compared to plain JTAG/SWD
Info : clock speed 300 kHz
Info : STLINK V2J16S0 (API v2) VID:PID 0483:3748
Info : Target voltage: 2.926341
Error: init mode failed (unable to connect to the target)

## Ajout d'une commande

Le shell est aisement extensible avec des commandes que vous pouvez écrire.

On peut par exemple ajouter la commande `git` qui affiche des informations sur le dépôt de code ayant servi à la production du firmware.

Ajoutez les lignes suivantes au fichier `main.c` de `~/github/RIOT-OS/RIOT/tests/shell`

```c
...
#include "git_utils.h"
...

static const shell_command_t shell_commands[] = {
  ...
	{ "git", "Get git info", git_cmd },
  ...
```

```bash
cd ~/github/RIOT-OS/RIOT/tests/shell
make -j 4 flash
```

## Timers

Les MCU disposent d'un ou plusieurs périphériques temporisateurs (timers). Les timers de RIOT simplifient leurs usages. Ils peuvent être utilsé pour déclancher une fonction (dite de rappel ou callback en anglais) apres plusieurs micro-secondes ou milli-secondes.

```bash
cd ~/github/RIOT-OS/RIOT/tests/periph/timer_periodic/
make -j 4 flash
```

<details>
<summary>Console (tio)</summary>
<pre>
Help: Press s to start test, r to print it is ready
START
main(): This is RIOT! (Version: 2023.07-devel-325-g2863d)

Running Timer 0 at 1000000 Hz.
One counter cycle is 25000 ticks or 25 ms
Will print 'tick' every cycle.

TEST START
Running iteration 1 of 3
[0] tick
[0] tick
[0] tick
[0] tick
[0] tick
[0] tick
[0] tick
[0] tick
[0] tick
[0] tick
[0] tick
[0] tick

Cycles:
channel 0 = 12	[OK]
Running iteration 2 of 3
[0] tick
[0] tick
[0] tick
[0] tick
[0] tick
[0] tick
[0] tick
[0] tick
[0] tick
[0] tick
[0] tick
[0] tick

Cycles:
channel 0 = 12	[OK]
Running iteration 3 of 3
[0] tick
[0] tick
[0] tick
[0] tick
[0] tick
[0] tick
[0] tick
[0] tick
[0] tick
[0] tick
[0] tick
[0] tick

Cycles:
channel 0 = 12	[OK]
TEST SUCCEEDED
{ "threads": [{ "name": "main", "stack_size": 1536, "stack_used": 412}]}

</pre>
</details>

## Threads

Les threads sont des processus légers partageant le même espace mémoire qui accèdent de manière concurrente mais qui ont chacun une pile privée (stack) dimensionnée en général à la fabrication (build time) du binaire du programme (firmware).

> Note: il convient donc de dimensionner correctement la taille de la pile d'une thread afin d'éviter que le sommet de la pile soit atteint pendant l'exécution.

Les threads permettent de réaliser plusieurs tâches en parellele par le programme. RIOT offre de mécanismes de barrière de concurrence entre les threads (mutex par exemple) et des moyens de communication par message.

```bash
cd ~/github/RIOT-OS/RIOT/tests/shell
make -j 4 flash
```

La commande `ps` du Shell permet de lister les threads courantes dans le programme. `main` correspond à la fonction `main()` qui exécute le Shell et `isr_stack` correspond à la thread qui exécute les traitants des interuptions, timers ... Il faut fréquent ajuster la taille de la pile de `isr_stack` avec `CFLAGS += -DISR_STACKSIZE=2048` par exemple. Idem pour `main` avec `THREAD_STACKSIZE_MAIN`.

<details>
<summary>Console (tio)</summary>
<pre>
main(): This is RIOT! (Version: 2023.07-devel-325-g2863d)
test_shell.
> ps
	pid | name                 | state    Q | pri | stack  ( used) ( free) | base addr  | current     
	  - | isr_stack            | -        - |   - |    512 (  172) (  340) | 0x20000000 | 0x200001c8
	  1 | main                 | running  Q |   7 |   1024 (  536) (  488) | 0x20000398 | 0x2000071c 
	    | SUM                  |            |     |   1536 (  708) (  828)
</pre>
</details>

```bash
cd ~/github/RIOT-OS/RIOT/tests/core/thread_float/
make -j 4 flash
```

<details>
<summary>Console (tio)</summary>
<pre>
> Help: Press s to start test, r to print it is ready
START
main(): This is RIOT! (Version: 2023.07-devel-325-g2863d)
THREADS CREATED

Context switch every 1562 µs
{ "threads": [{ "name": "main", "stack_size": 1536, "stack_used": 388 }]}
THREAD t1 start
THREAD t2 start
THREAD t3 start
t1: 141.443787
t3: 141.466812
t1: 141.443787
t3: 141.466812
t1: 141.443787
t3: 141.466812
t1: 141.443787
t3: 141.466812
t1: 141.443787
t3: 141.466812
t1: 141.443787
t3: 141.466812
t1: 141.443787
t3: 141.466812
t1: 141.443787
</pre>
</details>

```bash
cd ~/github/RIOT-OS/RIOT/tests/core/thread_msg_bus/
make -j 4 flash
```

<details>
<summary>Console (tio)</summary>
<pre>
Help: Press s to start test, r to print it is ready
START
main(): This is RIOT! (Version: 2023.07-devel-325-g2863d)
THREAD 1 start
THREAD 2 start
THREAD 3 start
THREADS CREATED
Posted event 22 to 0 threads
T1 recv: Hello Threads! (type=23) from bus
T3 recv: Hello Threads! (type=23) from bus
Posted event 23 to 2 threads
T1 recv: Hello Threads! (type=24) from bus
T2 recv: Hello Threads! (type=24) from bus
Posted event 24 to 2 threads
Post message to thread 1
T1 recv: Hello Thread 1 (type=4919)
Post shutdown request to all threads
T1 recv: shutdown request (type=0) from bus
{ "threads": [{ "name": "nr1", "stack_size": 1536, "stack_used": 412 }]}
T2 recv: shutdown request (type=0) from bus
{ "threads": [{ "name": "nr2", "stack_size": 1536, "stack_used": 412 }]}
T3 recv: shutdown request (type=0) from bus
{ "threads": [{ "name": "nr3", "stack_size": 1536, "stack_used": 412 }]}
SUCCESS
{ "threads": [{ "name": "main", "stack_size": 1536, "stack_used": 456 }]}
</pre>
</details>

```bash
cd ~/github/RIOT-OS/RIOT/tests/core/thread_cooperation/
make -j 4 flash
```

<details>
<summary>Console (tio)</summary>
<pre>
Help: Press s to start test, r to print it is ready
START
main(): This is RIOT! (Version: 2023.07-devel-325-g2863d)
[START] compute 12! (factorial).
MAIN: create thread, arg: 1
MAIN: msg to T-2
T-02: alive
T-02: got arg 1
MAIN: create thread, arg: 2
MAIN: msg to T-3
T-03: alive
T-03: got arg 2
MAIN: create thread, arg: 3
MAIN: msg to T-4
T-04: alive
T-04: got arg 3
MAIN: create thread, arg: 4
MAIN: msg to T-5
T-05: alive
T-05: got arg 4
MAIN: create thread, arg: 5
MAIN: msg to T-6
T-06: alive
T-06: got arg 5
MAIN: create thread, arg: 6
MAIN: msg to T-7
T-07: alive
T-07: got arg 6
MAIN: create thread, arg: 7
MAIN: msg to T-8
T-08: alive
T-08: got arg 7
MAIN: create thread, arg: 8
MAIN: msg to T-9
T-09: alive
T-09: got arg 8
MAIN: create thread, arg: 9
MAIN: msg to T-10
T-10: alive
T-10: got arg 9
MAIN: create thread, arg: 10
MAIN: msg to T-11
T-11: alive
T-11: got arg 10
MAIN: create thread, arg: 11
MAIN: msg to T-12
T-12: alive
T-12: got arg 11
MAIN: create thread, arg: 12
MAIN: msg to T-13
T-13: alive
T-13: got arg 12
{ "threads": [{ "name": "thread", "stack_size": 1024, "stack_used": 372 }]}
MAIN: reply from T-2
{ "threads": [{ "name": "thread", "stack_size": 1024, "stack_used": 372 }]}
MAIN: reply from T-3
{ "threads": [{ "name": "thread", "stack_size": 1024, "stack_used": 372 }]}
MAIN: reply from T-4
{ "threads": [{ "name": "thread", "stack_size": 1024, "stack_used": 372 }]}
MAIN: reply from T-5
{ "threads": [{ "name": "thread", "stack_size": 1024, "stack_used": 372 }]}
MAIN: reply from T-6
{ "threads": [{ "name": "thread", "stack_size": 1024, "stack_used": 372 }]}
MAIN: reply from T-7
{ "threads": [{ "name": "thread", "stack_size": 1024, "stack_used": 372 }]}
MAIN: reply from T-8
{ "threads": [{ "name": "thread", "stack_size": 1024, "stack_used": 372 }]}
MAIN: reply from T-9
{ "threads": [{ "name": "thread", "stack_size": 1024, "stack_used": 372 }]}
MAIN: reply from T-10
{ "threads": [{ "name": "thread", "stack_size": 1024, "stack_used": 372 }]}
MAIN: reply from T-11
{ "threads": [{ "name": "thread", "stack_size": 1024, "stack_used": 372 }]}
MAIN: reply from T-12
{ "threads": [{ "name": "thread", "stack_size": 1024, "stack_used": 372 }]}
MAIN: reply from T-13
MAIN: 12! = 479001600
[SUCCESS]
{ "threads": [{ "name": "main", "stack_size": 1536, "stack_used": 516 }]}
</pre>
</details>

## Aide au déboggage

TODO

* https://doc.riot-os.org/group__utils.html
* `assert()` et `expect()`
 https://doc.riot-os.org/group__test__utils__expect.html#gadd37fb477fadd68ccc0f938027ba132e

## RTC (Realtime Clock)

La plupart des microcontroleurs possède un périphérique horloge temps-réel (en anglais Realtime Clock, RTC) qui maintient la date et l'heure courante et définir des alarmes tant que le microcontroleur est alimenté. Il est possible de supporter la perte d'alimentation (par exemple, changement de batterie) en ajoutant une pile de secours à cette horloge.

```bash
cd ~/github/RIOT-OS/RIOT/tests/periph/rtc/
make -j 4 flash
```

<details>
<summary>Console (tio)</summary>
<pre>
> Help: Press s to start test, r to print it is ready
START
main(): This is RIOT! (Version: 2023.07-devel-325-g2863d)

RIOT RTC low-level driver test
This test will display 'Alarm!' every 2 seconds for 4 times
RTC mem OK
Clock value is now   2020-01-02 05:58:26
  Setting clock to   2020-02-28 23:59:57
Clock value is now   2020-02-28 23:59:57
  Setting alarm to   2020-02-28 23:59:59
   Alarm is set to   2020-02-28 23:59:59
  Alarm cleared at   2020-02-28 23:59:57
       No alarm at   2020-02-28 23:59:59
  Setting alarm to   2020-02-29 00:00:01

Alarm!
Alarm!
Alarm!
Alarm!
RTC mem OK
{ "threads": [{ "name": "main", "stack_size": 1536, "stack_used": 500 }]}
</pre>
</details>

Modifiez le `Makefile` de l'exemple `shell` pour ajouter:

```makefile
FEATURES_REQUIRED += periph_rtc
FEATURES_OPTIONAL += periph_rtc_ms
FEATURES_OPTIONAL += periph_rtc_mem

DISABLE_MODULE += periph_init_rtc
```

Reflashez la carte avec les commandes suivantes :

```bash
cd ~/github/RIOT-OS/RIOT/tests/sys/shell
make -j 4 flash
```

<details>
<summary>Console (tio)</summary>
<pre>
> help
> rtc
usage: rtc <command> [arguments]
commands:
	poweron		power the interface on
	poweroff	power the interface off
	clearalarm	deactivate the current alarm
	getalarm	print the currently alarm time
	setalarm YYYY-MM-DD HH:MM:SS
			set an alarm for the specified time
	gettime		print the current time
	settime YYYY-MM-DD HH:MM:SS
			set the current time
> rtc gettime
2020-02-29 00:05:33
> rtc settime 2023-11-15 22:00:00
> rtc gettime
2023-11-15 22:00:04
> setalarm 2023-11-15 22:01:00
>
> 
2023-11-15 22:01:00
</pre>
</details>

> A quoi peuvent servir les alarmes de la RTC ?
<details>
<summary>Réponse(s)</summary>
<ul>
<li>A vous réveiller à l'heure le matin</li>
<li>A lancer l'arrossage de votre champs</li> 
<li>A mettre votre bâtiment sous radar</li> 
<li>...</li> 
</ul>
</details>

> Exercice : ajoutez d'une commande `sun` au shell qui calcule les heures de lever et de coucher du soleil.

Vous pouvez vous aider de [ChatGPT](https://chat.openai.com) : Write the C function which computes sunrise time and sunset time for the current position.

## WDT (Watchdog Timer)

Le chien de garde (Watchdog Timer en anglais) est un périphérique qui veille à redémarrer (reboot) le microcontroleur quand le programme a planté (débordement de pile) ou boucle.

```bash
cd ~/github/RIOT-OS/RIOT/tests/periph/wdt
make -j 4 flash
```

`setup 0 10000` fixe le WDG à 10 seconds. Il faut ensuite lancer le watchdog avec la commande `start`. Sans `kick`, il reboote la carte.

<details>
<summary>Console (tio)</summary>
<pre>
This is RIOT! (Version: 2023.07-devel-325-g2863d)
RIOT wdt test application
> help
Command              Description
---------------------------------------
range                Return wdt Timer range
setup                Setup wdt Timer
kick                 Delay wdt timer
start                Start wdt timer
startloop            Start wdt timer, loop print system time
> setup
usage: setup <min_time[ms]> <max_time[ms]>
> setup 0 10000
valid configuration
> start
starting wdt timer
> kick
delaying wdt timer
> kick
delaying wdt timer
> main(): This is RIOT! (Version: 2023.07-devel-325-g2863d)
RIOT wdt test application</pre>
</details>

## EEPROM

L'EEPROM est une (petite) mémoire persistante qui est en général utilisé des paramêtres de personnalisation ou de configuration de l'équipement. 

Le microcontroleur de la carte Nucleo L432KC Base ne dispose pas d'EEPROM. Cependant, une [EEPROM I2C externe](https://www.st.com/en/memories/standard-i2c-eeprom.html) peut être ajoutée sur le PCB de la carte support ou via le commecteur Mikrobus avec la platine [MIKROE-1200](https://www.mikroe.com/eeprom-click).

```bash
cd tests/drivers/at24cxxx
make -j 4 flash
```

<details>
<summary>Console (tio)</summary>
<pre>
> main(): This is RIOT! (Version: 2023.07-devel-325-g2863d)

TODO

</pre>
</details>

> Attention: il faut mieux ne pas stocker des secrets (clés cryptographiques par exemple) dans l'EEPROM : il est préférable d'utiliser la mémoire persistante sécurisée d'un Secure Element (SE) intégré au microcontroleur ou d'un composant externe. Le MCU de la carte L432KC n'est pas doté d'un tel composant SE.

## CPU ID

Chaque MCU STM32 possède un numéro de série unique donnée par le fabricant ST Microelectronic.

```bash
cd ~/github/RIOT-OS/RIOT/tests/periph/cpuid
make -j 4 flash
```

<details>
<summary>Console (tio)</summary>
<pre>
Help: Press s to start test, r to print it is ready
START
main(): This is RIOT! (Version: 2023.07-devel-325-g2863d)
Test for the CPUID driver
This test is reading out the CPUID of the platforms CPU

CPUID_LEN: 12
CPUID: 0x33 0x37 0x47 0x05 0x30 0x37 0x38 0x37 0x00 0x6c 0xa0 0x6e
{ "threads": [{ "name": "main", "stack_size": 1536, "stack_used": 388 }]}
</pre>
</details>

> A quoi peut servir ce `cpuid` ?
<details>
<summary>Réponse(s)</summary>
<ul>
<li>numéro pour la garantie constructeur de l'équipement</li>
<li>numéro d'inventaire de l'équipement chez le propriétaire</li>
<li>lutte contre la contrefaçon</li>
<li>lutter contre le marché gris</li>
<li>...</li>
</ul>
</details>

## Tension de l'alimentation

```bash
cd ~/github/RIOT-OS/RIOT/tests/periph/vbat
make -j 4 flash
```

> Exercice: quel est l'intéret de connaître la tension d'alimentation ?
<details>
<summary>Réponse(s)</summary>
<li>Savoir à quel moment une opération de maintenance doit être planifier pour remplacer la batterie.</li>
</details>

## Extra

* True random number generator
* [STM32 last reset status](../tests/last_reset_status/)
* [STM32 internal temperature](../tests/internal_temperature/)

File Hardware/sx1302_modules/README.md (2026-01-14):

# SX1302 / SX1303 Gateway Modules for [Thingsat @ INISAT 📡 🚀](../Thingsat_INISAT)

This directory has been moved to https://github.com/thingsat/sx1302_modules

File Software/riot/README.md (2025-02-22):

# ThingSat @ INISAT 📡 🚀 (Nucleo L432KC + RAK 5146) :: Firmwares with [RIOT OS](https://github.com/RIOT-OS/RIOT)

* [Installation et configuration](install.md)
* [Fonctionnalités de base de RIOT](basics.md)
* [Communications sur la carte INISAT Nucleo L432KC + RAK 5146](comm.md)
* [Capteurs](sensors.md)
* [Misc](misc.md)


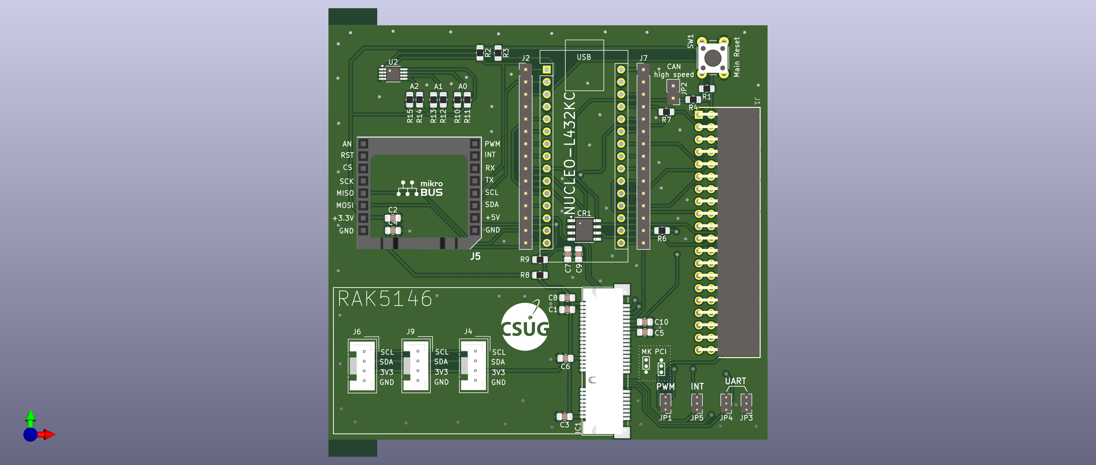
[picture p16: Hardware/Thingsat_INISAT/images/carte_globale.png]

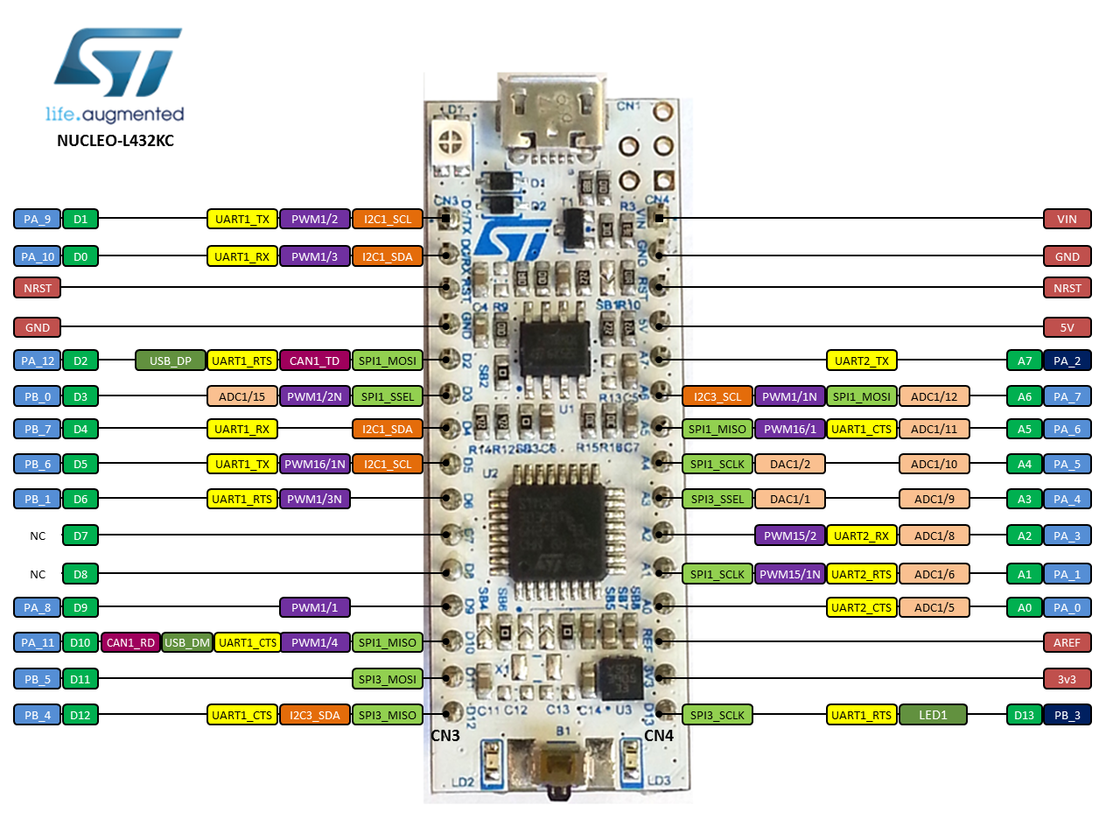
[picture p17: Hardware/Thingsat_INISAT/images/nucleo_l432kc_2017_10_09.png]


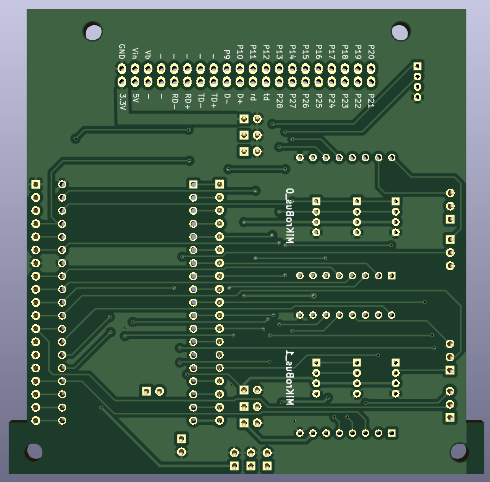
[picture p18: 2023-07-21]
Hardware/2U-PCB-TinyGS/Picture/back.png

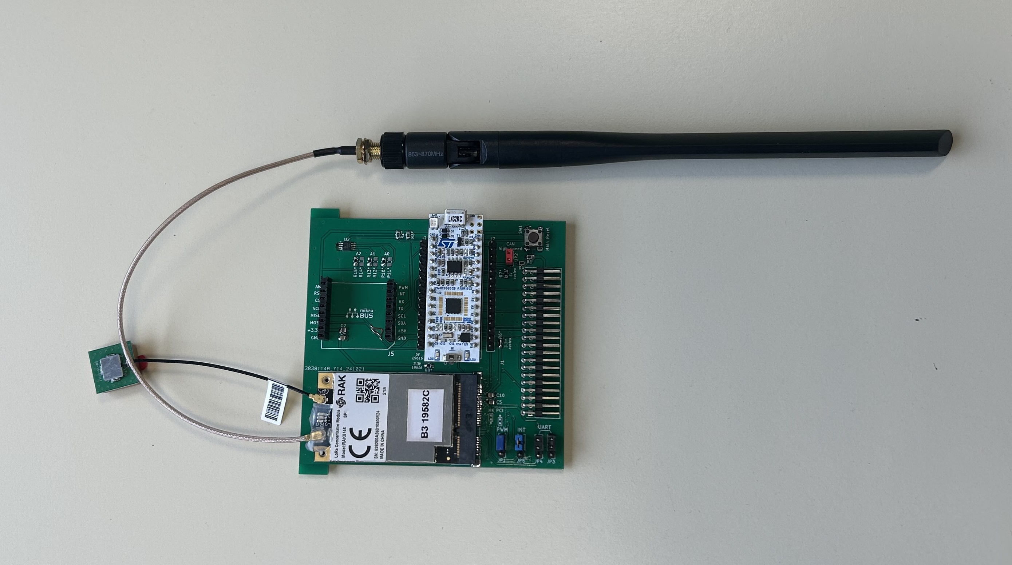
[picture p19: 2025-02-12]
Hardware/Thingsat_INISAT/images/inisat-l432kc+rak5146-01.jpg

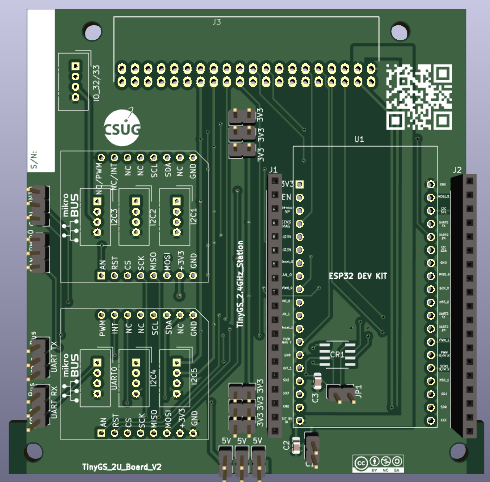
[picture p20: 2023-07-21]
Hardware/2U-PCB-TinyGS/Picture/front.png

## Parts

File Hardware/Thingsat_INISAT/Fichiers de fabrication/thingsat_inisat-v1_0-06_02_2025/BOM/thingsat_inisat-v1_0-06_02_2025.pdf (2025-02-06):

Quantité 1 | Référence IC1 | Empreinte BUS_PCI_Express_Mini | Valeure PCI_EXPRESS_CARD (Support PCI-e) | Commentaire
1 | JP2 | PinHeader_1x02_P2.54mm_Vertical | speed_controller
4 | JP1,JP3,JP4,JP5 | PinHeader_1x03_P2.54mm_Vertical
3 C7,C1,C2 | | C_0805_2012Metric_Pad1.18x1.45m m_HandSolder | 10uF
3 | J4,J6,J9 | NS-Tech_Grove_1x04_P2mm_Vertical | I2C_Grove | Ne monter que si J4,J6 et J9 ne sont pas montés
10 R6,R10,R12,R15,R11 | ,R7,R13,R9,R14,R8 | R_0805_2012Metric_Pad1.20x1.40m m_HandSolder | 0
2 | J7,J2 | PinHeader_1x15_P2.54mm_Vertical | (Header 01x14 droit 2,54mm) | Ne monter que si IC1 n'est pas monté
4 | R2,R3,R4,R1 | R_0805_2012Metric_Pad1.20x1.40m m_HandSolder | 4K7
7 C9,C5,C6,C3,C10,C | 4,C8 | C_0805_2012Metric_Pad1.18x1.45m m_HandSolder | 100nF
1 | CR1 | SO-8_3.9x4.9mm_P1.27mm | L9616 (CAN Transceiver)
1 | U2 | MSOP-8_3x3mm_P0.65mm | MCP9808_MSOP
1 | L432KC1 | Arduino_Nano | MCU (2 x Socket 01x14 droit 2,54mm)
1 J5 | | MIKROE4247 | MIKROE-4247 (2 x Socket 01x8 droit 2,54mm)
1 | SW1 | SW_PUSH_6mm | Reset
1 | J1 | flatsat_conn | Bus Standard (Socket 02x20 coudé 2,54mm)

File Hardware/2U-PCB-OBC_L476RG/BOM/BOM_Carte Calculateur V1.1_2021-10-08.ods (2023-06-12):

ID | Name | Designator | Footprint | Value | Quantity | Manufacturer Part | Manufacturer | Supplier | Supplier Part | Price | Vendor site
1 | Bus Buffer | B1 | Package_SO:TSOP-5_1.65x3.05mm_P0.95mm | - | 1 | SN74AHC1G125DBVT | TEXAS INSTRUMENTS | Mouser | 595-SN74AHC1G125DBVT | 0.88 | https://www.mouser.fr/ProductDetail/Texas-Instruments/SN74AHC1G125DBVT?qs=NvrC5vRk3q71zRyk1nqRCQ%3D%3D
2 | SMD Caoacitor | C1 | Capacitor_SMD:C_0603_1608Metric | 0.1 uF | 1 | C0603C104K4RACTU | KEMET | Mouser | 80-C0603C104K4R | 0,09 | https://www.mouser.fr/ProductDetail/KEMET/C0603C104K4RACTU?qs=l5k%252BbMnNDknCtKnMv1oEgA%3D%3D
3 | SMD Tantalum Capacitor | C2 | Capacitor_Tantalum_SMD:CP_EIA-7343-31_Kemet-D | 47 uF | 1 | T491X476K035AT | KEMET | Mouser | 80-T491X476K035 | 3,09 | https://www.mouser.fr/ProductDetail/KEMET/T491X476K035AT?qs=P4Y5NnTq0tXOwjs4eFEjlg%3D%3D
4 | Bus Standard | J1 | flatsat_conn:flatsat_conn | - | 1 | SSW-120-02-L-D-RA | SAMTEC | Mouser | 200-SSW12002LDRA | 7.23 | https://www.mouser.fr/ProductDetail/Samtec/SSW-120-02-L-D-RA?qs=%252BZP6%2F%252BtExtClp17wmtcVlA%3D%3D
5 | MicroSD | J2 | Connector_Card:microSD_HC_Hirose_DM3AT-SF-PEJM5 | - | 1 | DM3AT-SF-PEJM5 | HIROSE | Mouser | 798-DM3AT-SF-PEJM5 | 2.61 | https://www.mouser.fr/ProductDetail/Hirose-Connector/DM3AT-SF-PEJM5?qs=LZSZKJVF%252B2WTDKp%252BR7IYAQ%3D%3D
6 | Resistor | R1 | Resistor_SMD:R_0805_2012Metric | 10k | 1 | CR0805-FX-1002ELF | BOURNS | Mouser | 652-CR0805FX-1002ELF | 0.09 | https://www.mouser.fr/ProductDetail/Bourns/CR0805-FX-1002ELF?qs=tknLyCMIRbPr%252BDD0s0nG9g%3D%3D
7 | MCU | U1 | Nucleo64 | - | 1 | NUCLEO-L476RG | STMicroelectronics | Mouser | 511-NUCLEO-L476RG | 14.01 | https://www.mouser.fr/ProductDetail/STMicroelectronics/NUCLEO-L476RG?qs=PRtH0mD6DWbM6mRV5DKjBQ%3D%3D

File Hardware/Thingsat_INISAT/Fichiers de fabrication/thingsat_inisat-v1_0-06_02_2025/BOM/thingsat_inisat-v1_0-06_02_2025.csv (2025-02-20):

Id | Référence | Empreinte | Quantité | Désignation | Fournisseur et réf
1 | IC1 | BUS_PCI_Express_Mini | 1 | PCI_EXPRESS_CARD
2 | JP2 | PinHeader_1x02_P2.54mm_Vertical | 1 | speed_controller
3 | C7,C1,C2 | C_0805_2012Metric_Pad1.18x1.45mm_HandSolder | 3 | 10u
4 | J4,J6,J9 | NS-Tech_Grove_1x04_P2mm_Vertical | 3 | I2C_Grove
5 | R6,R10,R12,R15,R11,R7,R13,R9,R14,R8 | R_0805_2012Metric_Pad1.20x1.40mm_HandSolder | 10 | 0
6 | J7,J2 | PinHeader_1x15_P2.54mm_Vertical | 2 | Conn_01x15
7 | R2,R3,R4,R1 | R_0805_2012Metric_Pad1.20x1.40mm_HandSolder | 4 | 4K7
8 | C9,C5,C6,C3,C10,C4,C8 | C_0805_2012Metric_Pad1.18x1.45mm_HandSolder | 7 | 100n
9 | CR1 | SO-8_3.9x4.9mm_P1.27mm | 1 | L9616
10 | U2 | MSOP-8_3x3mm_P0.65mm | 1 | MCP9808_MSOP
11 | L432KC1 | Arduino_Nano | 1 | MCU
12 | J5 | MIKROE4247 | 1 | MIKROE-4247
13 | SW1 | SW_PUSH_6mm | 1 | Reset
14 | J1 | flatsat_conn | 1 | Bus Standard
15 | REF** | support mini PCI | 1 | support mini PCI
16 |  |  | 1

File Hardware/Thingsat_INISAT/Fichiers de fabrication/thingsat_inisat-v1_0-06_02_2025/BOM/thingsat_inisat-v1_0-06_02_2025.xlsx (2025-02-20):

BOM Thingsat Inisat v1.0 [06/02/2025]
Id | Quantité | Référence | Empreinte | Valeure | Commentaire
1 | 1 | IC1 | BUS_PCI_Express_Mini | PCI_EXPRESS_CARD (Support PCI-e)
2 | 1 | JP2 | PinHeader_1x02_P2.54mm_Vertical | speed_controller
3 | 4 | JP1,JP3,JP4,JP5 | PinHeader_1x03_P2.54mm_Vertical
4 | 3 | C7,C1,C2 | C_0805_2012Metric_Pad1.18x1.45mm_HandSolder | 10uF
5 | 3 | J4,J6,J9 | NS-Tech_Grove_1x04_P2mm_Vertical | I2C_Grove | Ne monter que si J4,J6 et J9 ne sont pas montés
6 | 10 | R6,R10,R12,R15,R11,R7,R13,R9,R14,R8 | R_0805_2012Metric_Pad1.20x1.40mm_HandSolder | 0
7 | 2 | J7,J2 | PinHeader_1x15_P2.54mm_Vertical | (Header 01x14 droit 2,54mm) | Ne monter que si IC1 n'est pas monté
8 | 4 | R2,R3,R4,R1 | R_0805_2012Metric_Pad1.20x1.40mm_HandSolder | 4K7
9 | 7 | C9,C5,C6,C3,C10,C4,C8 | C_0805_2012Metric_Pad1.18x1.45mm_HandSolder | 100nF
10 | 1 | CR1 | SO-8_3.9x4.9mm_P1.27mm | L9616 (CAN Transceiver)
11 | 1 | U2 | MSOP-8_3x3mm_P0.65mm | MCP9808_MSOP
12 | 1 | L432KC1 | Arduino_Nano | MCU (2 x Socket 01x14 droit 2,54mm)
13 | 1 | J5 | MIKROE4247 | MIKROE-4247 (2 x Socket 01x8 droit 2,54mm)
14 | 1 | SW1 | SW_PUSH_6mm | Reset
15 | 1 | J1 | flatsat_conn | Bus Standard (Socket 02x20 coudé 2,54mm)

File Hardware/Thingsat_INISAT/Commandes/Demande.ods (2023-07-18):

https://www.mouser.fr/ProductDetail/TE-Connectivity/2041119-1 | Reference | Qty | Value | Description | Footprint | MPN | Manufacturer | Vendor Website | Price € (total)
1 | B1, B2 | 2 | SN74AHC1G125DBVT | Buffer non inverseur 3-state | Package_SO:TSOP-5_1.65x3.05mm_P0.95mm | SN74AHC1G125DBVT | TI | https://www.mouser.fr/ProductDetail/Texas-Instruments/SN74AHC1G125DBVT?qs=NvrC5vRk3q71zRyk1nqRCQ%3D%3D | 1.74
2 | CR1 | 1 | L9616 | CAN buffer | footprints:SO-8_STM | L9616 | STMICROELECTRONICS | https://www.mouser.fr/ProductDetail/STMicroelectronics/L9616?qs=Au9%252BK7QVGzVbR%252BTIYyk1Fg%3D%3D | 1.57
3 | IC1 | 1 | PCI_EXPRESS_CARD | PCI express connnecteur 90 degrée | Connector_PCBEdge:BUS_PCI_Express_Mini | 2041119-1 | TE CONNECTIVITY | https://www.mouser.fr/ProductDetail/TE-Connectivity/2041119-1 | 0.847
4 | J1 | 1 | Bus Standard | Connecteur du flatsat | flatsat_conn:flatsat_conn | SAMTEC SSW-120-02-L-D-RA | SAMTEC | https://www.mouser.fr/ProductDetail/Samtec/SSW-120-02-L-D-RA?qs=%252BZP6%2F%252BtExtClp17wmtcVlA%3D%3D | 7.57
5 | JP1 | 1 | Jumper_RESET_L432KC_Open | RESET button for MCU | Button_Switch_SMD:SW_Push_1P1T_NO_CK_KMR2 | KMR241NG LFS | C&K Components | https://www.mouser.fr/ProductDetail/CK/KMR241NGLFS?qs=sb%252But3Lm4x3MOq2auuFbeg%3D%3D | 0.56
6 | JP2 | 1 | Jumper_MCU_Reset_Open | RESET button for RAK5146 MCU | Button_Switch_SMD:SW_Push_1P1T_NO_CK_KMR2 | KMR241NG LFS | C&K Components | https://www.mouser.fr/ProductDetail/CK/KMR241NGLFS?qs=sb%252But3Lm4x3MOq2auuFbeg%3D%3D | 0.56
7 | JP3 | 1 | Jumper_SX1303_Reset_Open | RESET button for SX1303 | Button_Switch_SMD:SW_Push_1P1T_NO_CK_KMR2 | KMR241NG LFS | C&K Components | https://www.mouser.fr/ProductDetail/CK/KMR241NGLFS?qs=sb%252But3Lm4x3MOq2auuFbeg%3D%3D | 0.56
 | Total |  |  |  |  |  |  |  | 13.407

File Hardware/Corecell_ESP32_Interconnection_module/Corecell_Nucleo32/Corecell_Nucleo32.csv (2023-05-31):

Ref | Qnty | Value | Cmp name | Footprint | Description | Vendor
C1, C7, | 2 | 10u | C | Capacitor_SMD:C_0603_1608Metric | Unpolarized capacitor | https://www.mouser.fr/ProductDetail/KYOCERA-AVX/04025C104KAT4A
C2, C3, C4, C5, C6, C8, | 6 | 100n | C | Capacitor_SMD:C_0402_1005Metric | Unpolarized capacitor | https://www.mouser.fr/ProductDetail/Samsung-Electro-Mechanics/CL10A106KP8NNWC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
IC1, | 1 | PCI_EXPRESS_CARD | PCI_EXPRESS_CARD | Connector_PCBEdge:BUS_PCI_Express_Mini | PCI express bus for rak5146 | https://fr.rs-online.com/web/p/connecteurs-de-carte-memoire/0435689
J1, J2, | 2 | Conn_01x19 | Conn_01x19 | Connector_PinSocket_2.54mm:PinSocket_1x19_P2.54mm_Vertical | Generic connector, single row, 01x19 | https://fr.rs-online.com/web/p/connecteurs-femelles-pour-ci/2079068
J3, | 1 | Bus Standard | Flatsat_conn | Connector_PinHeader_2.54mm:PinHeader_2x20_P2.54mm_Vertical |  | https://www.mouser.fr/ProductDetail/Samtec/SSW-120-02-L-D-RA?qs=%252BZP6%2F%252BtExtClp17wmtcVlA%3D%3D
J4, | 1 | Calculatrice_UART_groove | Conn_01x04 | Connector_PinSocket_2.54mm:PinSocket_1x04_P2.54mm_Vertical | Generic connector, single row, 01x04 | https://fr.rs-online.com/web/p/connecteurs-femelles-pour-ci/2518193
J5, | 1 | RAK5146_UART_groove(GPS) | Conn_01x05 | Connector_PinSocket_2.54mm:PinSocket_1x05_P2.54mm_Vertical | Generic connector, single row, 01x05 | https://fr.rs-online.com/web/p/connecteurs-femelles-pour-ci/2518200
J6, | 1 | RAK5146_I2C_groove(GPS) | Conn_01x05 | Connector_PinSocket_2.54mm:PinSocket_1x05_P2.54mm_Vertical | Generic connector, single row, 01x05 | https://fr.rs-online.com/web/p/connecteurs-femelles-pour-ci/2518200
J7, | 1 | RAK5146_SPI_groove(MCU) | Conn_01x06 | Connector_PinSocket_2.54mm:PinSocket_1x06_P2.54mm_Vertical | Generic connector, single row, 01x06 | https://fr.rs-online.com/web/p/connecteurs-femelles-pour-ci/1708779
JP1, | 1 | Jumper_RESET_GPS_Open | Jumper_2_Open | Button_Switch_SMD:SW_Push_1P1T_NO_CK_KMR2 | Jumper, 2-pole, open | https://www.mouser.fr/ProductDetail/CK/KMR221NGLFS?qs=sb%252But3Lm4x2H4qewmcuXNA%3D%3D
JP2, | 1 | Jumper_STANDY_GPS_Open | Jumper_2_Open | Button_Switch_SMD:SW_Push_1P1T_NO_CK_KMR2 | Jumper, 2-pole, open | https://www.mouser.fr/ProductDetail/CK/KMR221NGLFS?qs=sb%252But3Lm4x2H4qewmcuXNA%3D%3D
JP3, | 1 | Jumper_MCU_Reset_Open | Jumper_2_Open | Button_Switch_SMD:SW_Push_1P1T_NO_CK_KMR2 | Jumper, 2-pole, open | https://www.mouser.fr/ProductDetail/CK/KMR221NGLFS?qs=sb%252But3Lm4x2H4qewmcuXNA%3D%3D
Q1, | 1 | BC548 | BC548 | Package_TO_SOT_THT:TO-92_Inline | 0.1A Ic, 30V Vce, Small Signal NPN Transistor, TO-92 | https://www.mouser.fr/ProductDetail/Diotec-Semiconductor/BC548A?qs=OlC7AqGiEDn7ksXHluy35w%3D%3D
R1, R3, R4, R5, | 4 | 0 | R | Resistor_SMD:R_0402_1005Metric | Resistor | https://www.mouser.fr/ProductDetail/Vishay-Dale/CRCW04020000Z0EDC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
R2, R6, R7, R9, | 4 | 100 | R | Resistor_SMD:R_0402_1005Metric | Resistor | https://www.mouser.fr/ProductDetail/YAGEO/RC0402FR-07100RL?qs=V1yeUXFNrknwaJOOZ4yDtg%3D%3D
R8, | 1 | NC | R | Resistor_SMD:R_0402_1005Metric | Resistor
U1 | 1 | ESP32-DEVKITC-32D | ESP32-DEVKITC-32D | ESP32-DEVKITC-32D:MODULE_ESP32-DEVKITC-32D

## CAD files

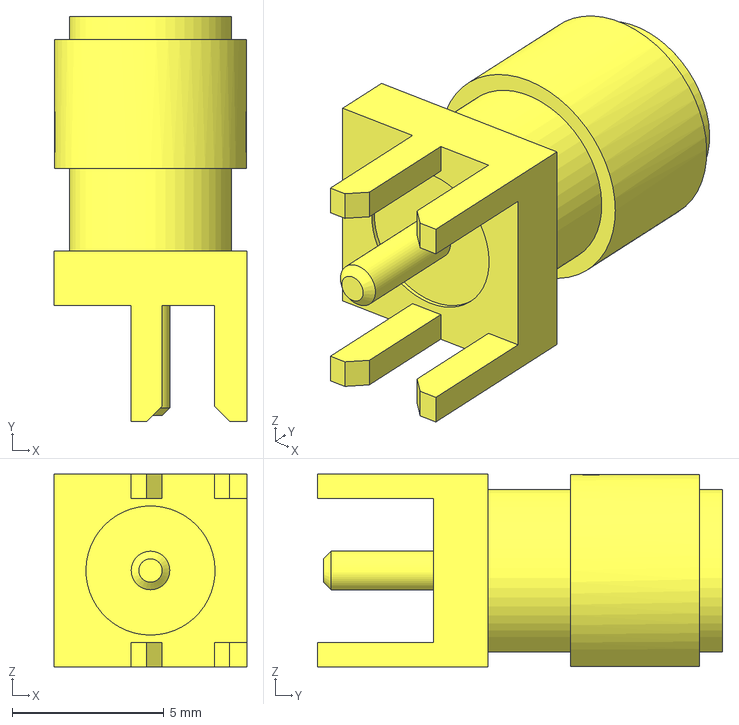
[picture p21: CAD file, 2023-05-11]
Hardware/2U-PCB-TinyGS/Lib & Fp/SMA-J-P-H-ST-EM1/SMA-J-P-H-ST-EM1.step
6.35 x 13.3 x 6.35 mm

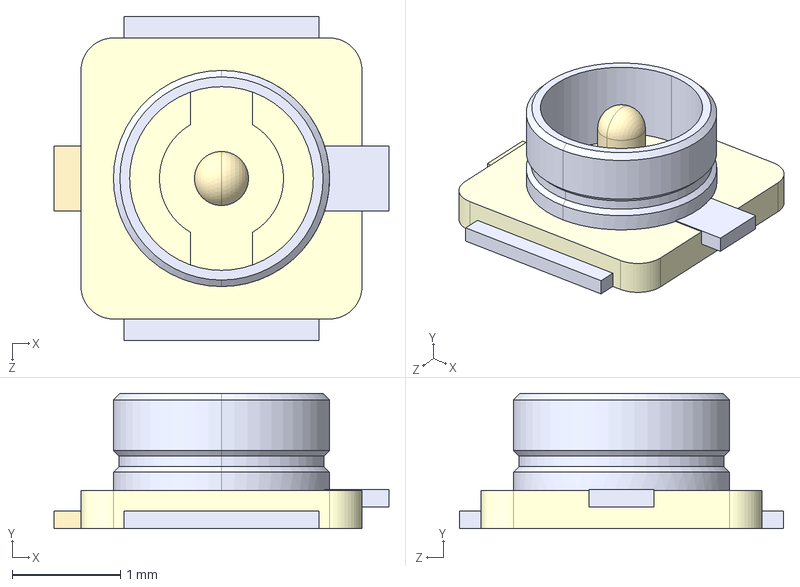
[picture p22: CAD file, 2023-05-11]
Hardware/2U-PCB-TinyGS/Lib & Fp/U.FL-R-SMT_01_/U.FL-R-SMT_01_.step
3.10 x 1.25 x 3.00 mm

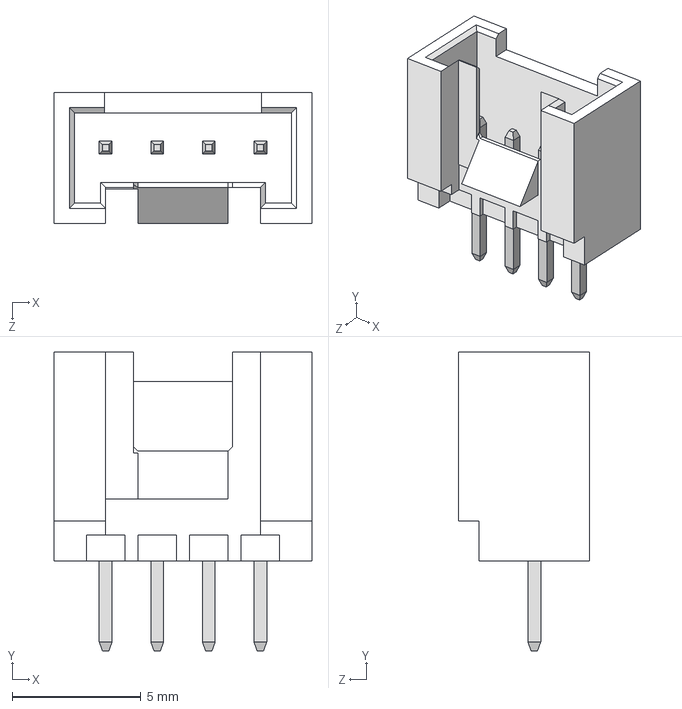
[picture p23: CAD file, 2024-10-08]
Hardware/Thingsat_INISAT/Projet Kicad/3d_models/Grove_header_vertical_THT.stp
10.0 x 11.6 x 5.10 mm

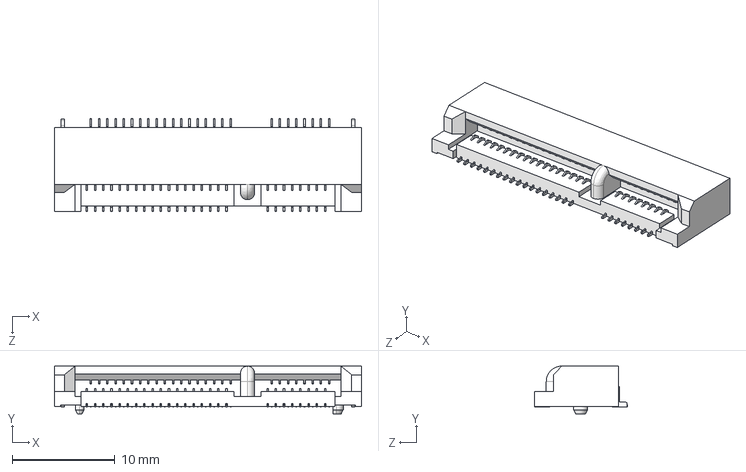
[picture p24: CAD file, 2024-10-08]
Hardware/Thingsat_INISAT/Projet Kicad/3d_models/Mini-PCI-Express.stp
29.9 x 4.65 x 9.09 mm

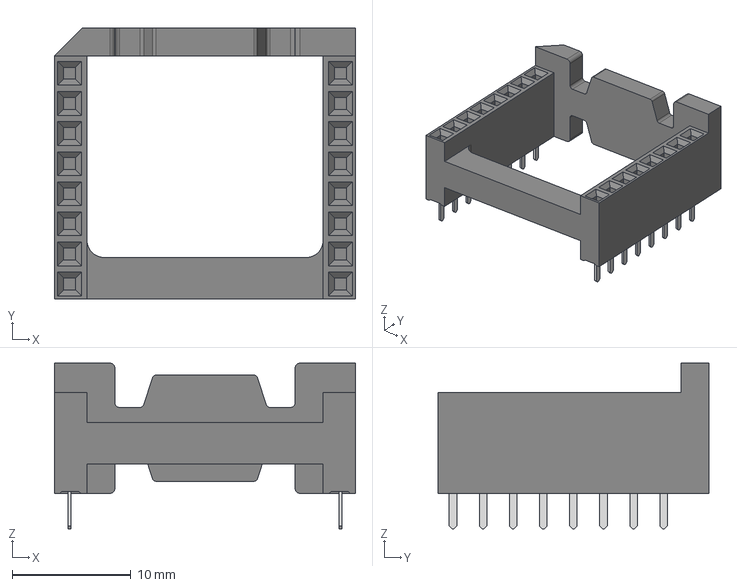
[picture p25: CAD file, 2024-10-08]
Hardware/Thingsat_INISAT/Projet Kicad/3d_models/MIKROE-4247.stp
25.4 x 22.9 x 14.0 mm

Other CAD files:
Hardware/2U-PCB-TinyGS/Lib & Fp/LIB_MIKROE-924/MIKROE-924/Allegro/mikroe924.psm
Hardware/2U-PCB-TinyGS/Lib & Fp/LIB_MIKROE-924/MIKROE-924/DEHDL/mikroe_924/chips/chips.prt

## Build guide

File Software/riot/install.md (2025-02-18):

# Premiers pas avec la carte INISAT Nucleo L432KC + RAK 5146

[Getting started](https://doc.riot-os.org/getting-started.html)

Clonez les dépôts (si ce n'est pas déjà fait):
```bash
mkdir -p ~/github/RIOT-OS
cd  ~/github/RIOT-OS
git clone https://github.com/RIOT-OS/RIOT.git
mkdir -p ~/github/thingsat
cd  ~/github/thingsat
git clone https://github.com/thingsat/riot_modules
```

Configurez `RIOTBASE`
```bash
export RIOTBASE=~/github/RIOT-OS/RIOT
```

Configurez la carte cible pour `make`
```bash
export EXTERNAL_BOARD_DIRS=~/github/thingsat/riot_modules/boards/
export BOARD=nucleo-l432kc-inisat
```

Recherchez le  `tty` de la console et connectez-vous à celle-ci avec `tio`.

Sur Linux
```bash
lsusb
tio
tio -b 115200 -m INLCRNL /dev/ttyUSB0
```

Sur MacOS
```bash
lsusb
tio
tio -L
tio -b 115200 -m INLCRNL /dev/tty.usbmodem-XXXX
```

> Pour mémoire, si vous utilisez Linux dans une machine virtuelle VirtualBox, il faut monter les 2 périphériques USBSerial et STLink dans le menu Péripériques de la machine virtuelle.

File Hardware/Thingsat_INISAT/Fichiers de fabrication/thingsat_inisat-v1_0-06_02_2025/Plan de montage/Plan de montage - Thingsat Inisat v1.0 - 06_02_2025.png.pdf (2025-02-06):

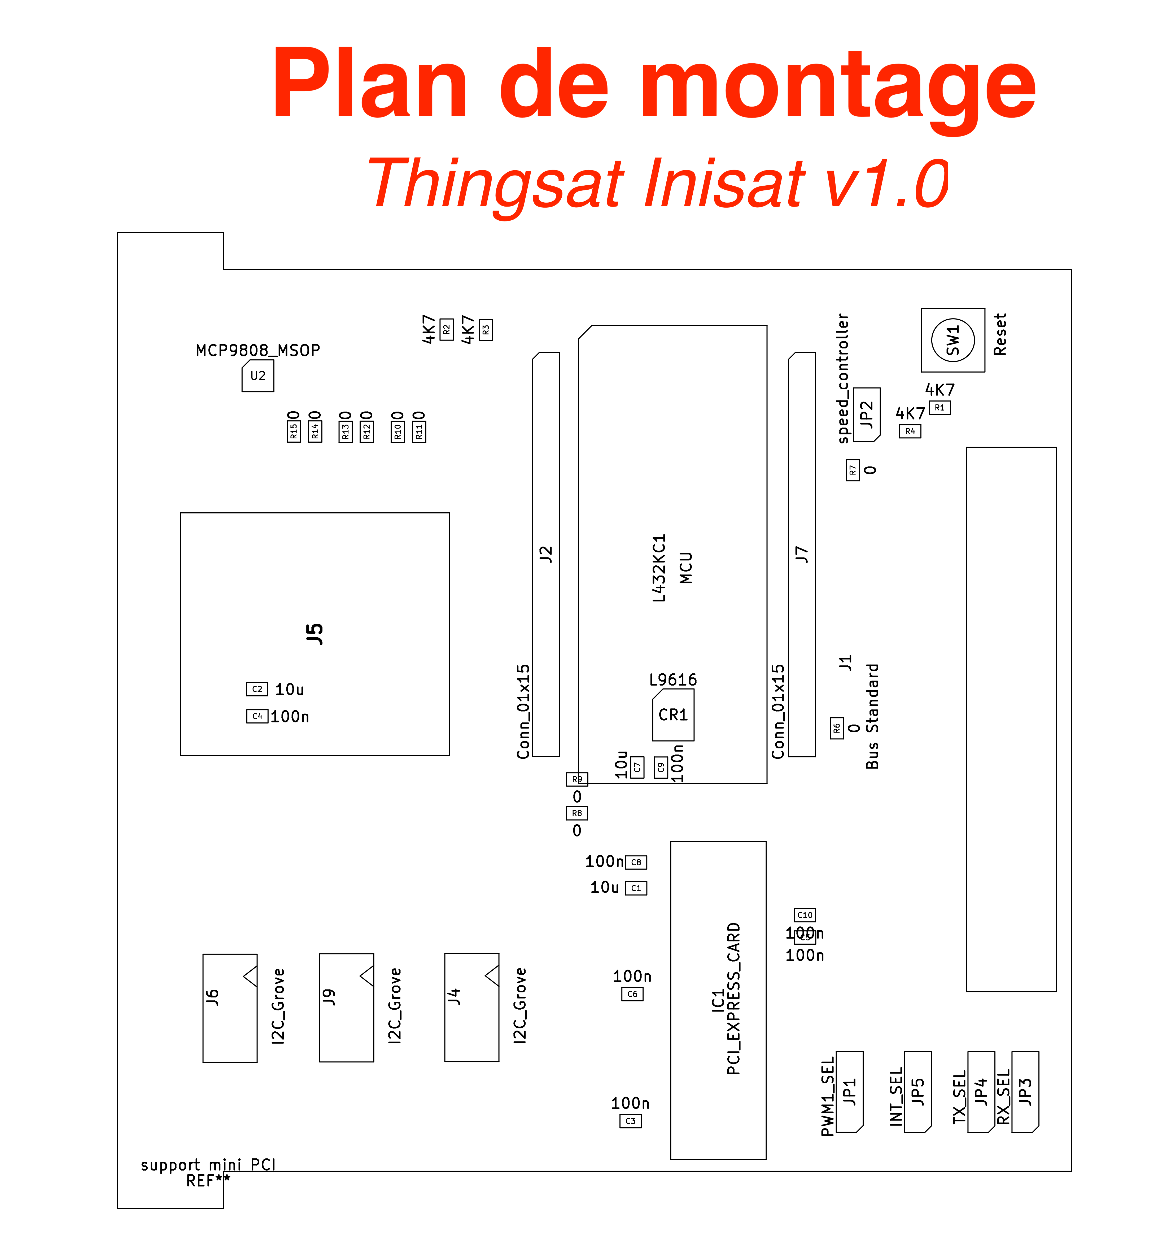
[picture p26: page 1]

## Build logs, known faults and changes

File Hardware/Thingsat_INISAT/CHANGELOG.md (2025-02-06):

# Changelog Thingsat PC104

## v1.0 [06/02/2025] \(Léo CORDIER)

* correction de l'inversion des signaux MISO et MOSI sur le support MikroBus

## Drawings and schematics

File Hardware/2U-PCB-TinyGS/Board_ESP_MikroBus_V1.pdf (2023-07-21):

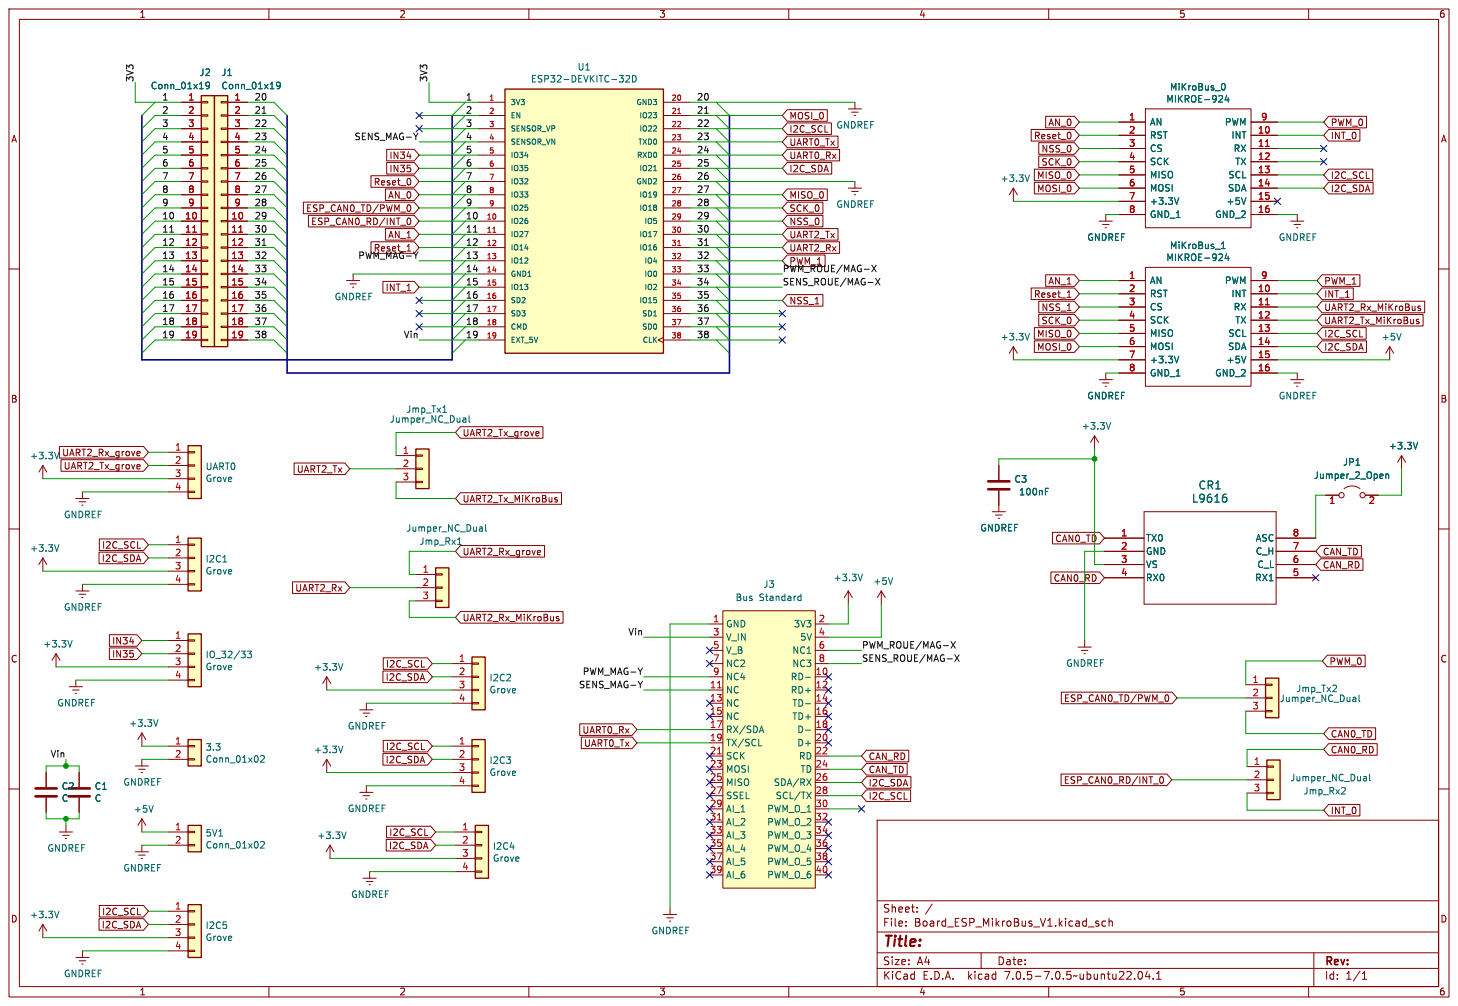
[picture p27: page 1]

Id: 1/1 Title: File: Board_ESP_MikroBus_V1.kicad_sch Sheet: / +3.3V

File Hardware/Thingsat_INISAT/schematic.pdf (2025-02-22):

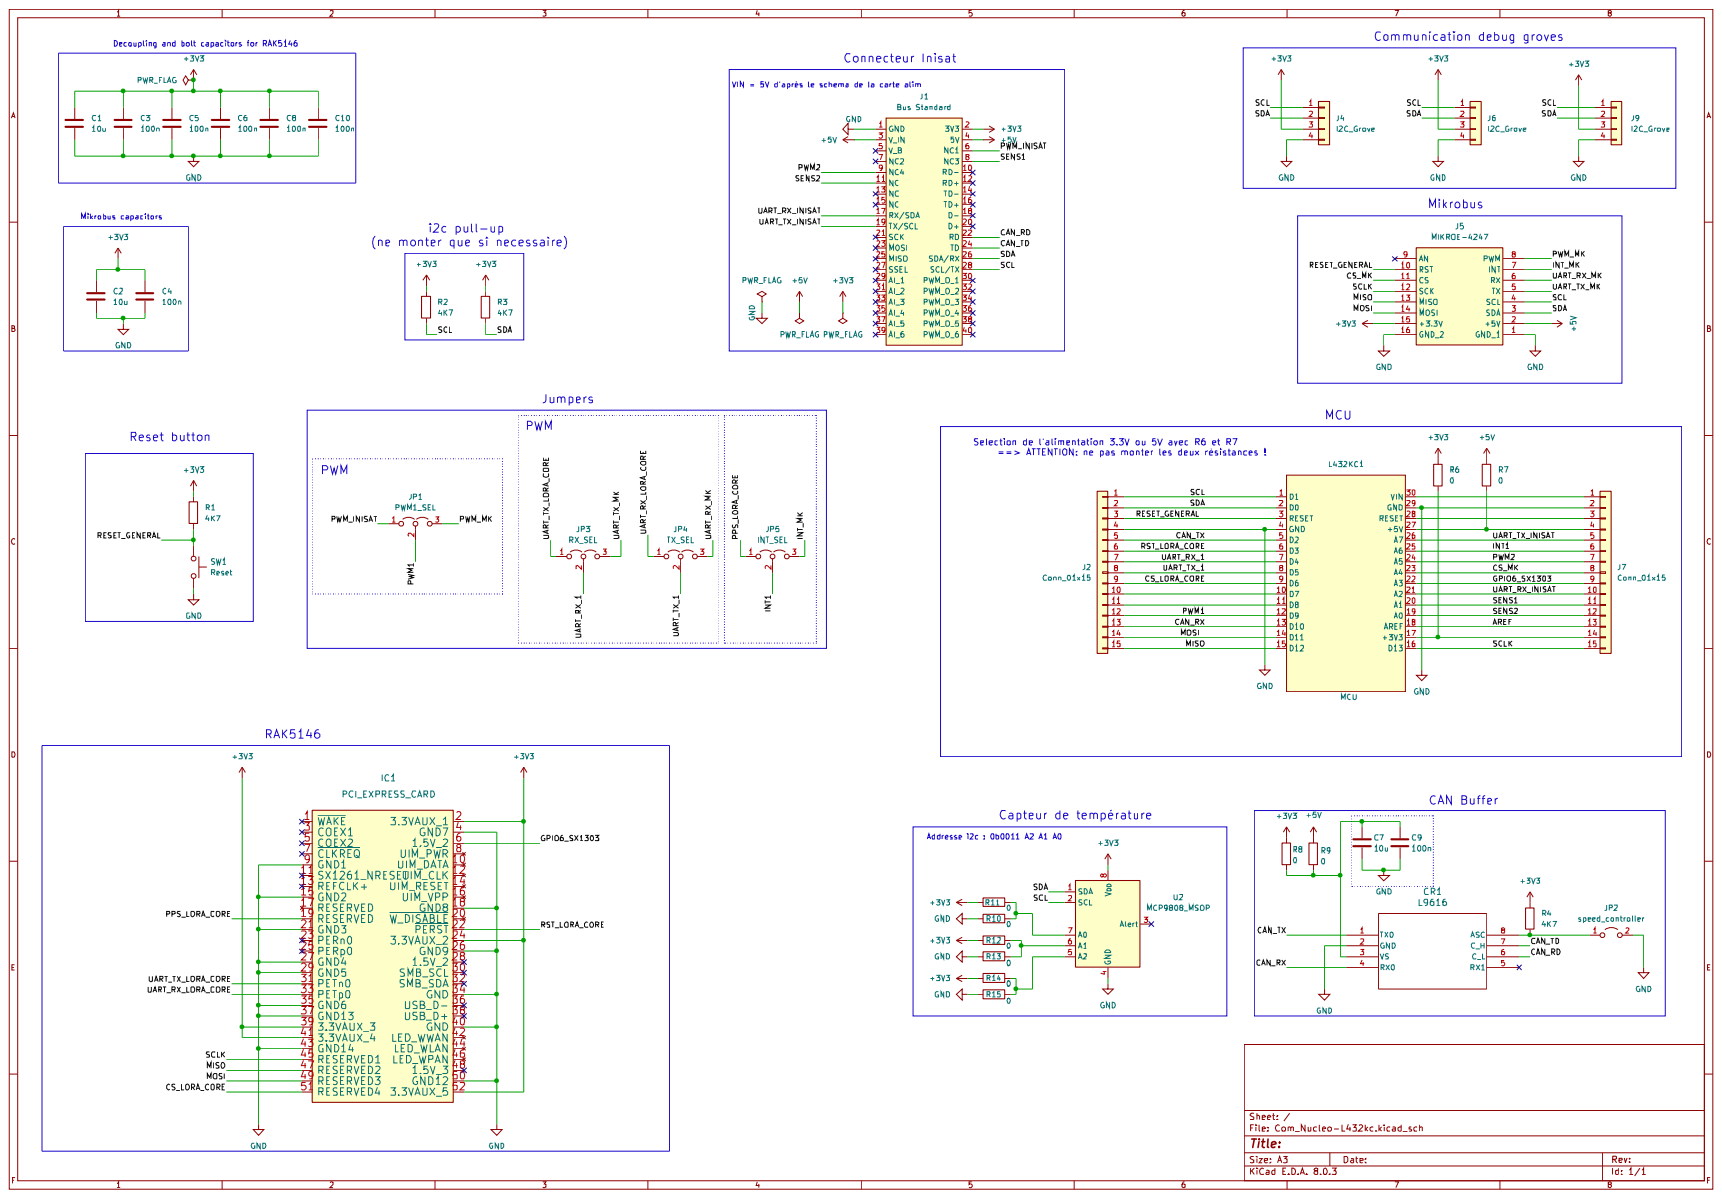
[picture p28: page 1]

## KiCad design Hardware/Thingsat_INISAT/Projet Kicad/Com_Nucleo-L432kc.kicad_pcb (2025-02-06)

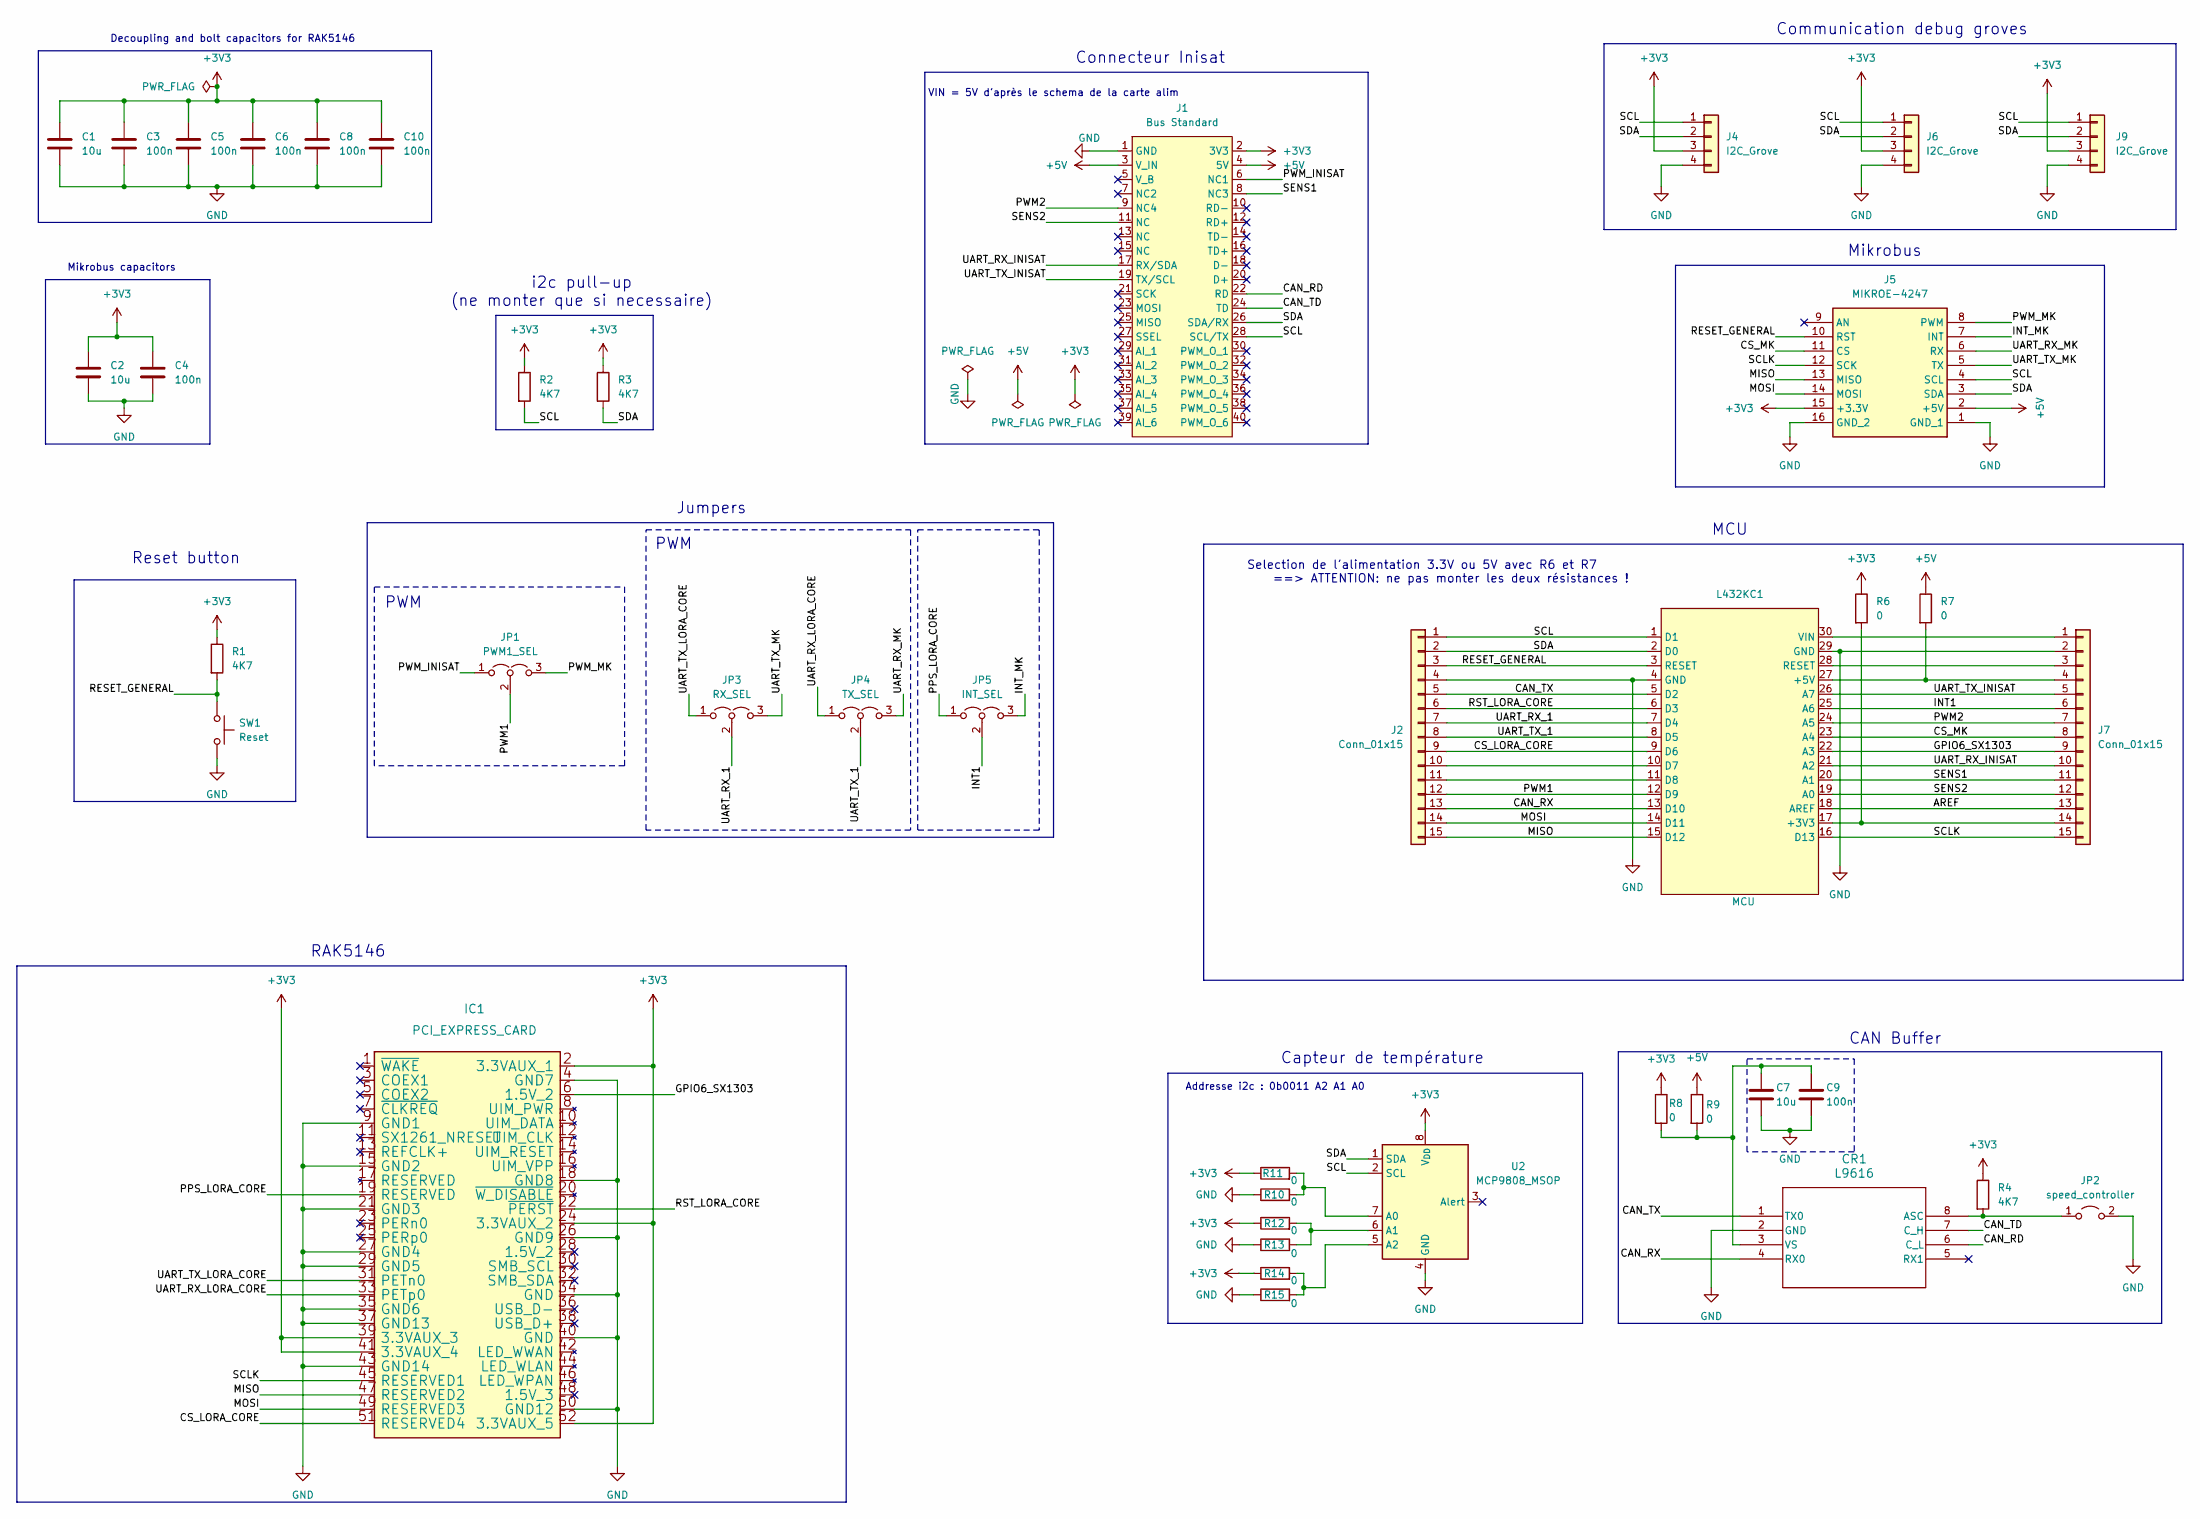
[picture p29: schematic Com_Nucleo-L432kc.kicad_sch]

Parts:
C1, C2, C7: 10u; C_0805_2012Metric_Pad1.18x1.45mm_HandSolder
C3, C4, C5, C6, C8, C9, C10: 100n; C_0805_2012Metric_Pad1.18x1.45mm_HandSolder
CR1: L9616; SO-8_3.9x4.9mm_P1.27mm
IC1: PCI_EXPRESS_CARD; BUS_PCI_Express_Mini
J1: Bus Standard; flatsat_conn
J2, J7: Conn_01x15; PinHeader_1x15_P2.54mm_Vertical
J4, J6, J9: I2C_Grove; NS-Tech_Grove_1x04_P2mm_Vertical
J5: MIKROE-4247; MIKROE4247; Manufacturer_Part_Number MIKROE-4247; Mouser Part Number 932-MIKROE-4247
JP1: PWM1_SEL; PinHeader_1x03_P2.54mm_Vertical
JP2: speed_controller; PinHeader_1x02_P2.54mm_Vertical
JP3: RX_SEL; PinHeader_1x03_P2.54mm_Vertical
JP4: TX_SEL; PinHeader_1x03_P2.54mm_Vertical
JP5: INT_SEL; PinHeader_1x03_P2.54mm_Vertical
L432KC1: MCU; Arduino_Nano
R1, R2, R3, R4: 4K7; R_0805_2012Metric_Pad1.20x1.40mm_HandSolder
R6, R7, R8, R9, R10, R11, R12, R13, R14, R15: 0; R_0805_2012Metric_Pad1.20x1.40mm_HandSolder
SW1: Reset; SW_PUSH_6mm
U2: MCP9808_MSOP; MSOP-8_3x3mm_P0.65mm

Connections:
+3V3: C1.1, C2.1, C3.1, C4.1, C5.1, C6.1, C8.1, C10.1, IC1.2 (3.3VAUX_1), IC1.24 (3.3VAUX_2), IC1.39 (3.3VAUX_3), IC1.41 (3.3VAUX_4), IC1.52 (3.3VAUX_5), J1.2 (3V3), J4.3, J5.15 (+3.3V), J6.3, J9.3, R1.1, R2.1, R3.1, R4.1, R6.1, R8.1, R11.1, R12.1, R14.1, U2.8 (V_{DD})
+5V: J1.3 (V_IN), J1.4 (5V), J5.2 (+5V), R7.1, R9.1
/AREF: J7.13, L432KC1.18 (AREF)
/CAN_RD: CR1.6 (C_L), J1.22 (RD)
/CAN_RX: CR1.4 (RX0), J2.13, L432KC1.13 (D10)
/CAN_TD: CR1.7 (C_H), J1.24 (TD)
/CAN_TX: CR1.1 (TX0), J2.5, L432KC1.5 (D2)
/CS_LORA_CORE: IC1.51 (RESERVED4), J2.9, L432KC1.9 (D6)
/CS_MK: J5.11 (CS), J7.8, L432KC1.23 (A4)
/GPIO6_SX1303: IC1.6 (1.5V_2), J7.9, L432KC1.22 (A3)
/INT1: J7.6, JP5.2 (C), L432KC1.25 (A6)
/INT_MK: J5.7 (INT), JP5.3 (B)
/MISO: IC1.47 (RESERVED2), J2.15, J5.13 (MISO), L432KC1.15 (D12)
/MOSI: IC1.49 (RESERVED3), J2.14, J5.14 (MOSI), L432KC1.14 (D11)
/PPS_LORA_CORE: IC1.19 (RESERVED), JP5.1 (A)
/PWM1: J2.12, JP1.2 (C), L432KC1.12 (D9)
/PWM2: J1.9 (NC4), J7.7, L432KC1.24 (A5)
/PWM_INISAT: J1.6 (NC1), JP1.1 (A)
/PWM_MK: J5.8 (PWM), JP1.3 (B)
/RESET_GENERAL: J2.3, J5.10 (RST), L432KC1.3 (RESET), R1.2, SW1.1
/RST_LORA_CORE: IC1.22 (~PERST), J2.6, L432KC1.6 (D3)
/SCL: J1.28 (SCL/TX), J2.1, J4.1, J5.4 (SCL), J6.1, J9.1, L432KC1.1 (D1), R2.2, U2.2 (SCL)
/SCLK: IC1.45 (RESERVED1), J5.12 (SCK), J7.15, L432KC1.16 (D13)
/SDA: J1.26 (SDA/RX), J2.2, J4.2, J5.3 (SDA), J6.2, J9.2, L432KC1.2 (D0), R3.2, U2.1 (SDA)
/SENS1: J1.8 (NC3), J7.11, L432KC1.20 (A1)
/SENS2: J1.11 (NC), J7.12, L432KC1.19 (A0)
/UART_RX_1: J2.7, JP3.2 (C), L432KC1.7 (D4)
/UART_RX_INISAT: J1.17 (RX/SDA), J7.10, L432KC1.21 (A2)
/UART_RX_LORA_CORE: IC1.33 (PETp0), JP4.1 (A)
/UART_RX_MK: J5.6 (RX), JP4.3 (B)
/UART_TX_1: J2.8, JP4.2 (C), L432KC1.8 (D5)
/UART_TX_INISAT: J1.19 (TX/SCL), J7.5, L432KC1.26 (A7)
/UART_TX_LORA_CORE: IC1.31 (PETn0), JP3.1 (A)
/UART_TX_MK: J5.5 (TX), JP3.3 (B)
GND: C1.2, C2.2, C3.2, C4.2, C5.2, C6.2, C7.2, C8.2, C9.2, C10.2, CR1.2 (GND), IC1.4 (GND7), IC1.9 (GND1), IC1.15 (GND2), IC1.18 (GND8), IC1.21 (GND3), IC1.26 (GND9), IC1.27 (GND4), IC1.29 (GND5), IC1.34 (GND), IC1.35 (GND6), IC1.37 (GND13), IC1.40 (GND), IC1.43 (GND14), IC1.50 (GND12), J1.1 (GND), J2.4, J4.4, J5.1 (GND_1), J5.16 (GND_2), J6.4, J7.2, J9.4, JP2.2 (B), L432KC1.4 (GND), L432KC1.29 (GND), R10.1, R13.1, R15.1, SW1.2, U2.4 (GND)
unnamed: CR1.8 (ASC), JP2.1 (A), R4.2
unnamed: C7.1, C9.1, CR1.3 (VS), R8.2, R9.2
unnamed: J2.10, L432KC1.10 (D7)
unnamed: J2.11, L432KC1.11 (D8)
unnamed: J7.1, L432KC1.30 (VIN)
unnamed: J7.3, L432KC1.28 (RESET)
unnamed: J7.4, L432KC1.27 (+5V), R7.2
unnamed: J7.14, L432KC1.17 (+3V3), R6.2
unnamed: R10.2, R11.2, U2.7 (A0)
unnamed: R12.2, R13.2, U2.6 (A1)
unnamed: R14.2, R15.2, U2.5 (A2)

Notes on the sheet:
Connecteur Inisat
Capteur de température
RAK5146
PWM
VIN = 5V d'après le schema de la carte alim
Selection de l'alimentation 3.3V ou 5V avec R6 et R7 ==> ATTENTION: ne pas monter les deux résistances !
Mikrobus capacitors
Communication debug groves
Addresse i2c : 0b0011 A2 A1 A0
Mikrobus
MCU
CAN Buffer
Jumpers
Decoupling and bolt capacitors for RAK5146
i2c pull-up (ne monter que si necessaire)
Reset button

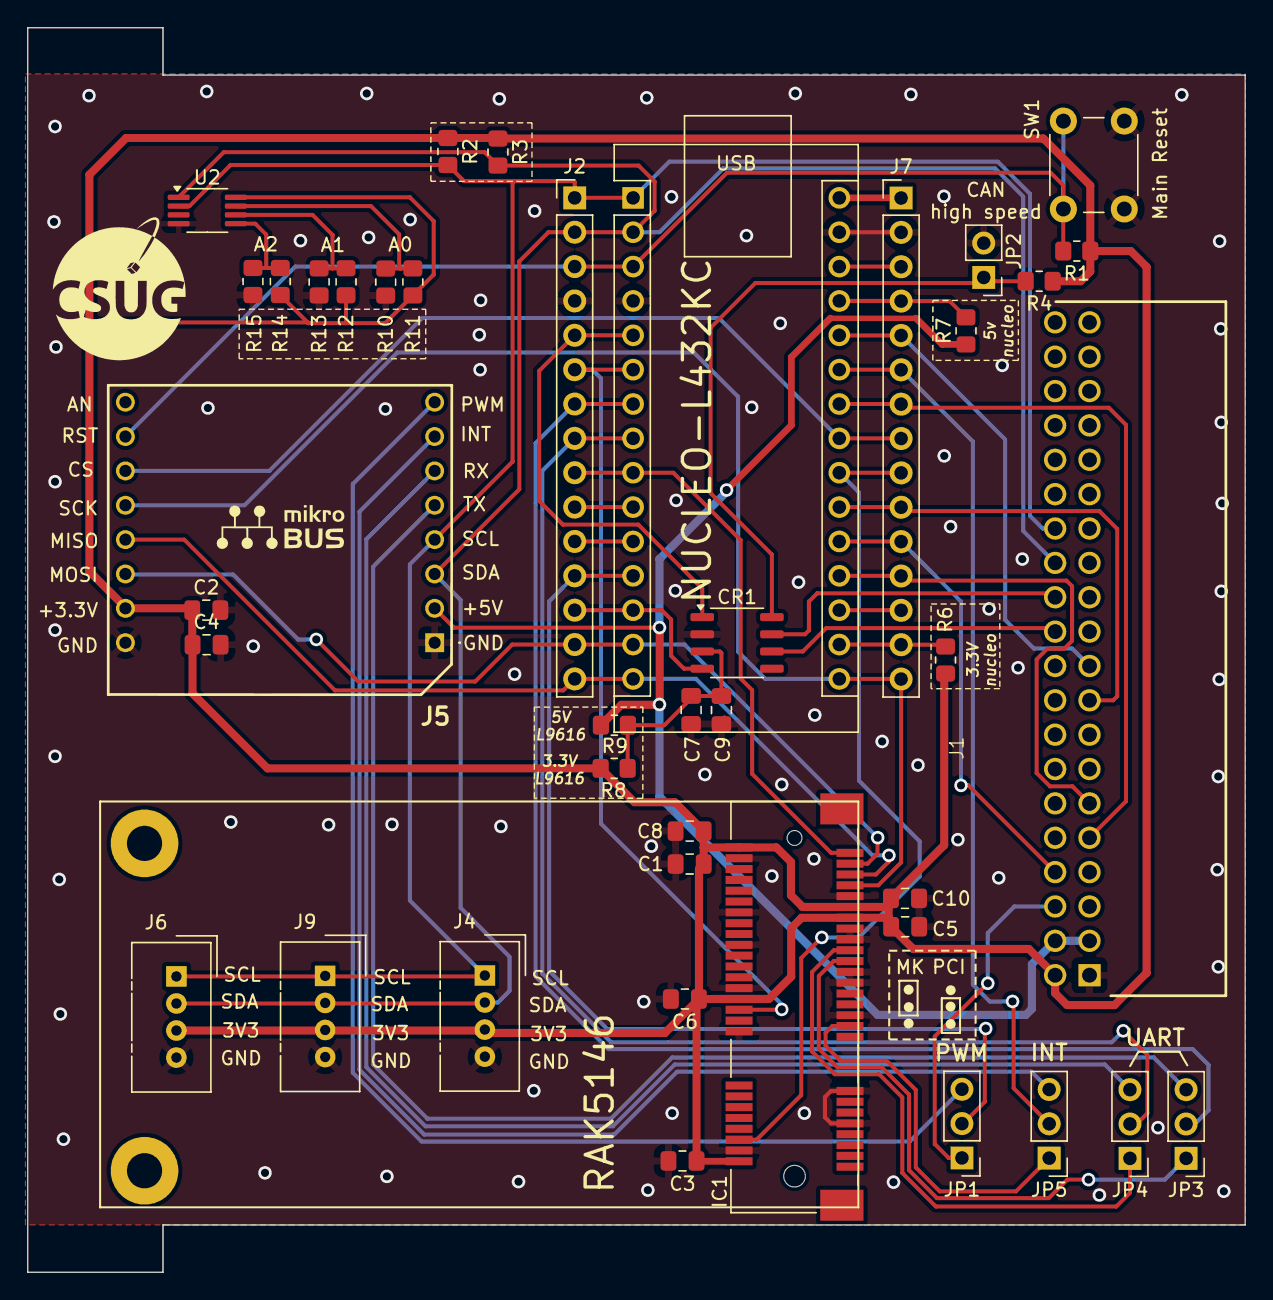
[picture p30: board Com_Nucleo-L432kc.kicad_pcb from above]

Board: 2 copper layers, 90.0 x 92.0 mm, 42 parts (1 on the bottom side), 46 nets.

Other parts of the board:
QR: LOGO; qr_code_flatsat

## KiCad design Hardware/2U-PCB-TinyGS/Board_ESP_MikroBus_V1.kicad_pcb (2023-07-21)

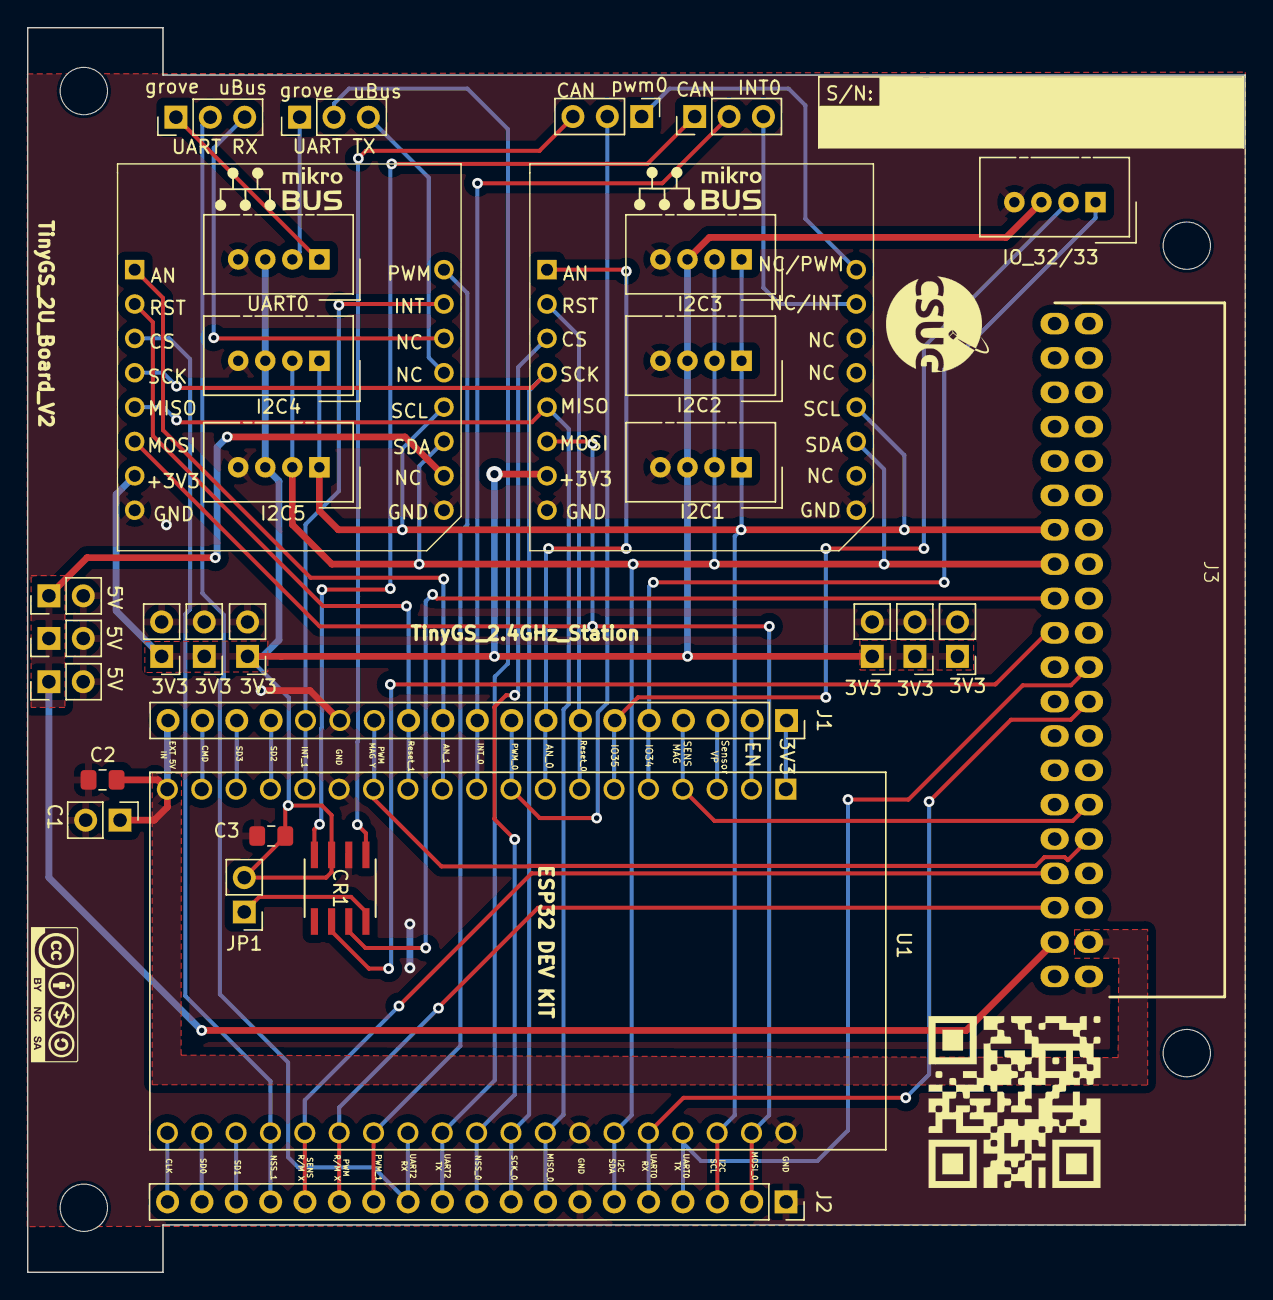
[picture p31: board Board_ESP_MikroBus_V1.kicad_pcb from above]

Board: 2 copper layers, 90.0 x 92.0 mm, 31 parts (0 on the bottom side), 49 nets.

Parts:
3.1, 3.2, 3.3, 3.4, 3.5, 3.6, 5V1, 5V2, 5V3: Conn_01x02; PinHeader_1x02_P2.54mm_Vertical
C1: C; PinHeader_1x02_P2.54mm_Vertical
C2: C; C_0805_2012Metric_Pad1.18x1.45mm_HandSolder
C3: 100nF; C_0805_2012Metric_Pad1.18x1.45mm_HandSolder
CR1: L9616; SO-8_STM
I2C1, I2C2, I2C3, I2C4, I2C5: Grove; NS-Tech_Grove_1x04_P2mm_Vertical
IO_32/33: Grove; NS-Tech_Grove_1x04_P2mm_Vertical
J1, J2: Conn_01x19; PinSocket_1x19_P2.54mm_Vertical
J3: Bus Standard; flatsat_conn
JP1: Jumper_2_Open; PinHeader_1x02_P2.54mm_Vertical
Jmp_Rx1, Jmp_Rx2: Jumper_NC_Dual; PinHeader_1x03_P2.54mm_Vertical
Jmp_Tx1, Jmp_Tx2: Jumper_NC_Dual; PinHeader_1x03_P2.54mm_Vertical
MiKroBus_0, MiKroBus_1: MIKROE-924; MIKROE924
U1: ESP32-DEVKITC-32D; MODULE_ESP32-DEVKITC-32D
UART0: Grove; NS-Tech_Grove_1x04_P2mm_Vertical

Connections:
+3.3V: 3.1.1, 3.2.1, 3.3.1, 3.4.1, 3.5.1, 3.6.1, C3.1, CR1.3 (VS), I2C1.3, I2C2.3, I2C3.3, I2C4.3, I2C5.3, IO_32/33.3, J3.2 (3V3), JP1.2 (B), MiKroBus_0.7 (+3.3V), MiKroBus_1.7 (+3.3V), UART0.3
+5V: 5V1.1, 5V2.1, 5V3.1, J3.4 (5V), MiKroBus_1.15 (+5V)
/1: J1.1, U1.1 (3V3)
/2: J1.2, U1.2 (EN)
/3: J1.3, U1.3 (SENSOR_VP)
/4: J1.4, J3.11 (NC), U1.4 (SENSOR_VN)
/13: J1.13, J3.9 (NC4), U1.13 (IO12)
/16: J1.16, U1.16 (SD2)
/17: J1.17, U1.17 (SD3)
/18: J1.18, U1.18 (CMD)
/19: C1.1, C2.1, J1.19, J3.3 (V_IN), U1.19 (EXT_5V)
/33: J2.14, J3.6 (NC1), U1.33 (IO0)
/34: J2.15, J3.8 (NC3), U1.34 (IO2)
/36: J2.17, U1.36 (SD1)
/37: J2.18, U1.37 (SD0)
/38: J2.19, U1.38 (CLK)
AN_0: J1.8, MiKroBus_0.1 (AN), U1.8 (IO33)
AN_1: J1.11, MiKroBus_1.1 (AN), U1.11 (IO27)
CAN0_RD: CR1.4 (RX0), Jmp_Rx2.1
CAN0_TD: CR1.1 (TX0), Jmp_Tx2.3
CAN_RD: CR1.6 (C_L), J3.22 (RD)
CAN_TD: CR1.7 (C_H), J3.24 (TD)
ESP_CAN0_RD/INT_0: J1.10, Jmp_Rx2.2, U1.10 (IO26)
ESP_CAN0_TD/PWM_0: J1.9, Jmp_Tx2.2, U1.9 (IO25)
GNDREF: 3.1.2, 3.2.2, 3.3.2, 3.4.2, 3.5.2, 3.6.2, 5V1.2, 5V2.2, 5V3.2, C1.2, C2.2, C3.2, CR1.2 (GND), I2C1.4, I2C2.4, I2C3.4, I2C4.4, I2C5.4, IO_32/33.4, J1.14, J2.1, J2.7, J3.1 (GND), MiKroBus_0.8 (GND_1), MiKroBus_0.16 (GND_2), MiKroBus_1.8 (GND_1), MiKroBus_1.16 (GND_2), U1.14 (GND1), U1.20 (GND3), U1.26 (GND2), UART0.4
I2C_SCL: I2C1.1, I2C2.1, I2C3.1, I2C4.1, I2C5.1, J2.3, J3.28 (SCL/TX), MiKroBus_0.13 (SCL), MiKroBus_1.13 (SCL), U1.22 (IO22)
I2C_SDA: I2C1.2, I2C2.2, I2C3.2, I2C4.2, I2C5.2, J2.6, J3.26 (SDA/RX), MiKroBus_0.14 (SDA), MiKroBus_1.14 (SDA), U1.25 (IO21)
IN34: IO_32/33.1, J1.5, U1.5 (IO34)
IN35: IO_32/33.2, J1.6, U1.6 (IO35)
INT_0: Jmp_Rx2.3, MiKroBus_0.10 (INT)
INT_1: J1.15, MiKroBus_1.10 (INT), U1.15 (IO13)
MISO_0: J2.8, MiKroBus_0.5 (MISO), MiKroBus_1.5 (MISO), U1.27 (IO19)
MOSI_0: J2.2, MiKroBus_0.6 (MOSI), MiKroBus_1.6 (MOSI), U1.21 (IO23)
NSS_0: J2.10, MiKroBus_0.3 (CS), U1.29 (IO5)
NSS_1: J2.16, MiKroBus_1.3 (CS), U1.35 (IO15)
unnamed: CR1.8 (ASC), JP1.1 (A)
PWM_0: Jmp_Tx2.1, MiKroBus_0.9 (PWM)
PWM_1: J2.13, MiKroBus_1.9 (PWM), U1.32 (IO4)
Reset_0: J1.7, MiKroBus_0.2 (RST), U1.7 (IO32)
Reset_1: J1.12, MiKroBus_1.2 (RST), U1.12 (IO14)
SCK_0: J2.9, MiKroBus_0.4 (SCK), MiKroBus_1.4 (SCK), U1.28 (IO18)
UART0_Rx: J2.5, J3.17 (RX/SDA), U1.24 (RXD0)
UART0_Tx: J2.4, J3.19 (TX/SCL), U1.23 (TXD0)
UART2_Rx: J2.12, Jmp_Rx1.2, U1.31 (IO16)
UART2_Rx_MiKroBus: Jmp_Rx1.3, MiKroBus_1.11 (RX)
UART2_Rx_grove: Jmp_Rx1.1, UART0.1
UART2_Tx: J2.11, Jmp_Tx1.2, U1.30 (IO17)
UART2_Tx_MiKroBus: Jmp_Tx1.3, MiKroBus_1.12 (TX)
UART2_Tx_grove: Jmp_Tx1.1, UART0.2

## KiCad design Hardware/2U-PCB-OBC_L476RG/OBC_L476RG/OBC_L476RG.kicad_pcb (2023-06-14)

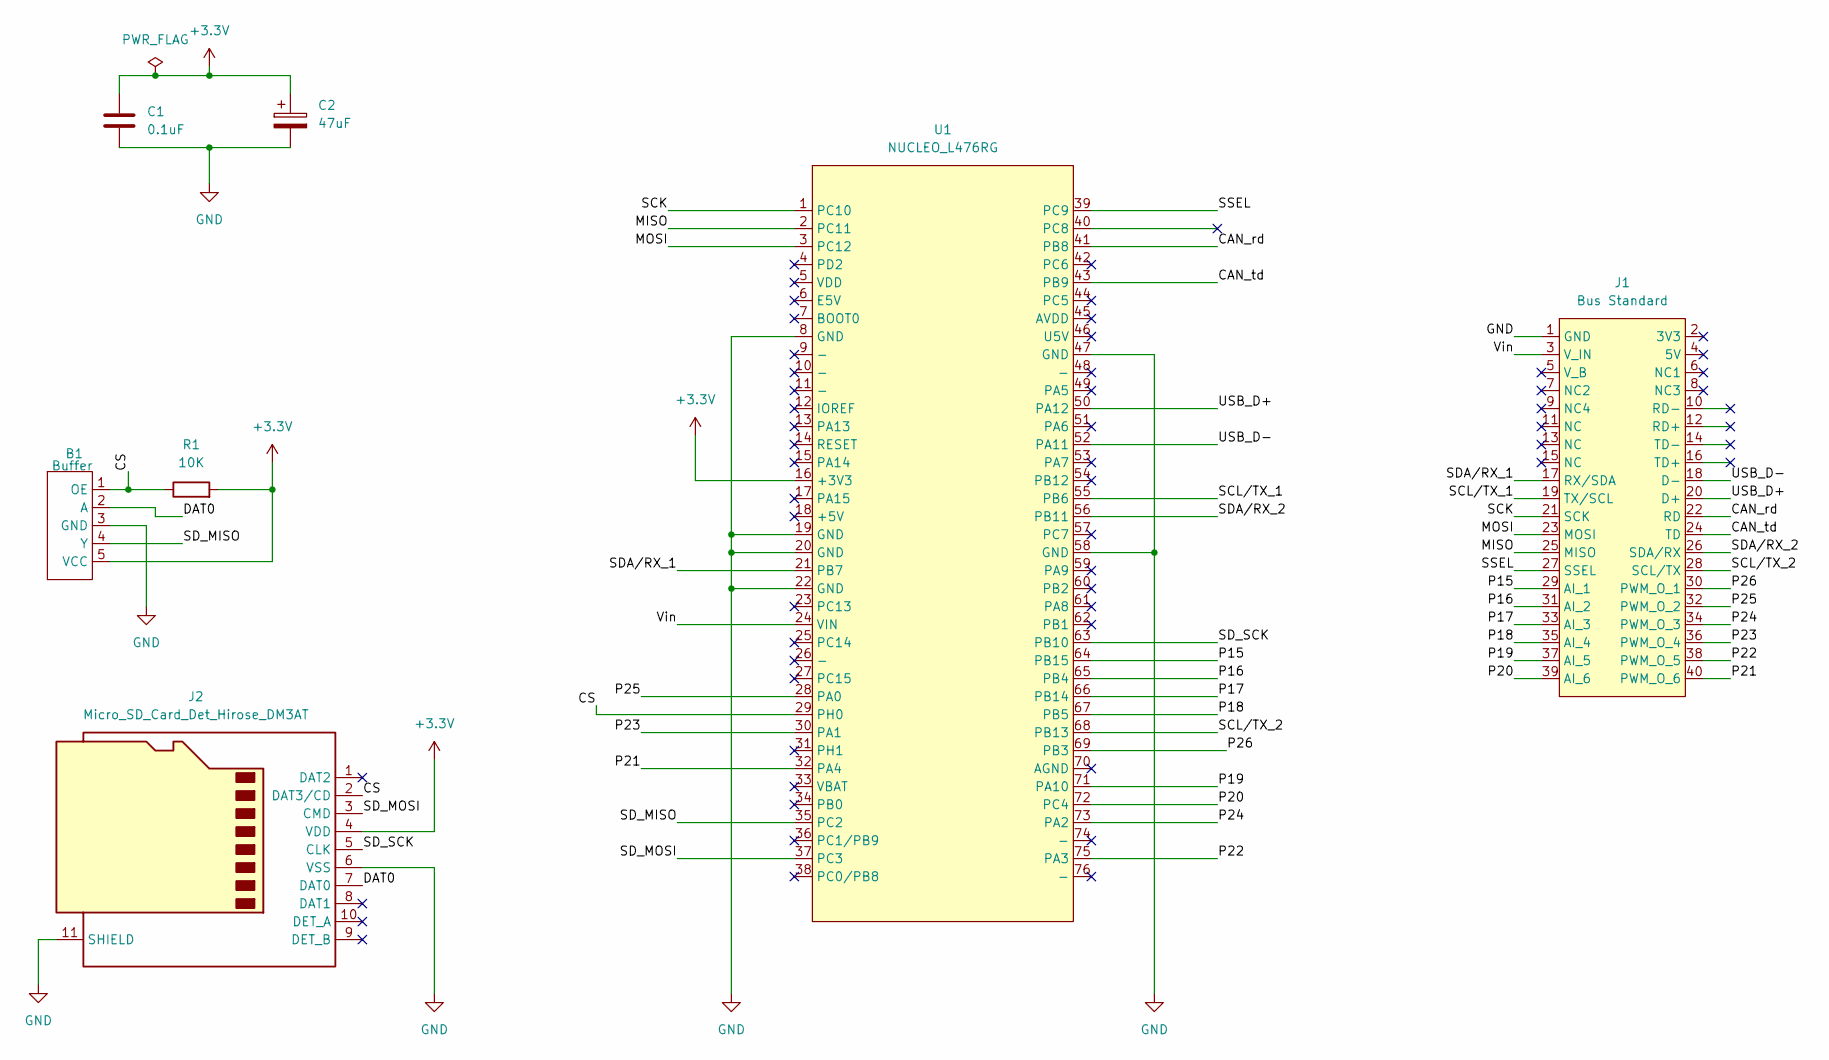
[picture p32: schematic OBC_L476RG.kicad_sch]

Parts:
B1: Buffer; TSOP-5_1.65x3.05mm_P0.95mm
C1: 0.1uF; C_0603_1608Metric
C2: 47uF; CP_EIA-7343-31_Kemet-D
J1: Bus Standard; flatsat_conn
J2: Micro_SD_Card_Det_Hirose_DM3AT; microSD_HC_Hirose_DM3AT-SF-PEJM5
R1: 10K; R_0805_2012Metric
U1: NUCLEO_L476RG; Nucleo64

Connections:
+3.3V: B1.5 (VCC), C1.1, C2.1, J2.4 (VDD), R1.2, U1.16 (+3V3)
/CAN_rd: J1.22 (RD), U1.41 (PB8)
/CAN_td: J1.24 (TD), U1.43 (PB9)
/CS: B1.1 (OE), J2.2 (DAT3/CD), R1.1, U1.29 (PH0)
/DAT0: B1.2 (A), J2.7 (DAT0)
/MISO: J1.25 (MISO), U1.2 (PC11)
/MOSI: J1.23 (MOSI), U1.3 (PC12)
/P15: J1.29 (AI_1), U1.64 (PB15)
/P16: J1.31 (AI_2), U1.65 (PB4)
/P17: J1.33 (AI_3), U1.66 (PB14)
/P18: J1.35 (AI_4), U1.67 (PB5)
/P19: J1.37 (AI_5), U1.71 (PA10)
/P20: J1.39 (AI_6), U1.72 (PC4)
/P21: J1.40 (PWM_O_6), U1.32 (PA4)
/P22: J1.38 (PWM_O_5), U1.75 (PA3)
/P23: J1.36 (PWM_O_4), U1.30 (PA1)
/P24: J1.34 (PWM_O_3), U1.73 (PA2)
/P25: J1.32 (PWM_O_2), U1.28 (PA0)
/P26: J1.30 (PWM_O_1), U1.69 (PB3)
/SCK: J1.21 (SCK), U1.1 (PC10)
/SCL/TX_1: J1.19 (TX/SCL), U1.55 (PB6)
/SCL/TX_2: J1.28 (SCL/TX), U1.68 (PB13)
/SDA/RX_1: J1.17 (RX/SDA), U1.21 (PB7)
/SDA/RX_2: J1.26 (SDA/RX), U1.56 (PB11)
/SD_MISO: B1.4 (Y), U1.35 (PC2)
/SD_MOSI: J2.3 (CMD), U1.37 (PC3)
/SD_SCK: J2.5 (CLK), U1.63 (PB10)
/SSEL: J1.27 (SSEL), U1.39 (PC9)
/USB_D+: J1.20 (D+), U1.50 (PA12)
/USB_D-: J1.18 (D-), U1.52 (PA11)
/Vin: J1.3 (V_IN), U1.24 (VIN)
GND: B1.3 (GND), C1.2, C2.2, J1.1 (GND), J2.6 (VSS), J2.11 (SHIELD), U1.8 (GND), U1.19 (GND), U1.20 (GND), U1.22 (GND), U1.47 (GND), U1.58 (GND)

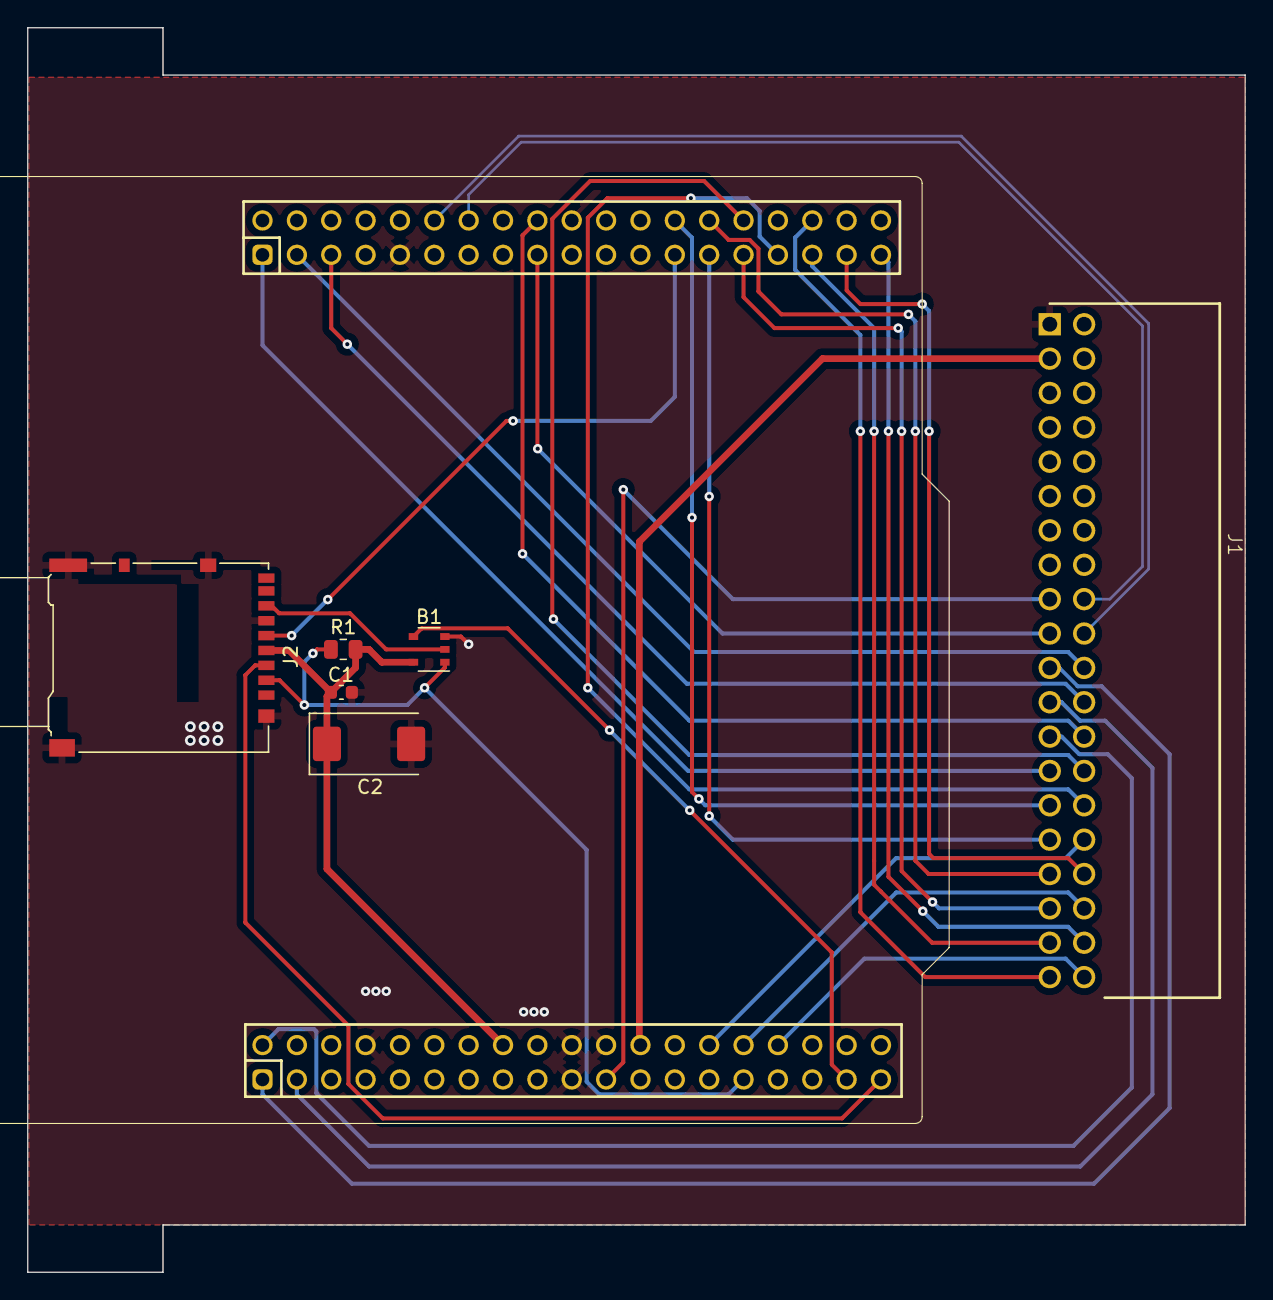
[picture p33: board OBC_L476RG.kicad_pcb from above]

Board: 2 copper layers, 90.0 x 92.0 mm, 7 parts (0 on the bottom side), 32 nets.

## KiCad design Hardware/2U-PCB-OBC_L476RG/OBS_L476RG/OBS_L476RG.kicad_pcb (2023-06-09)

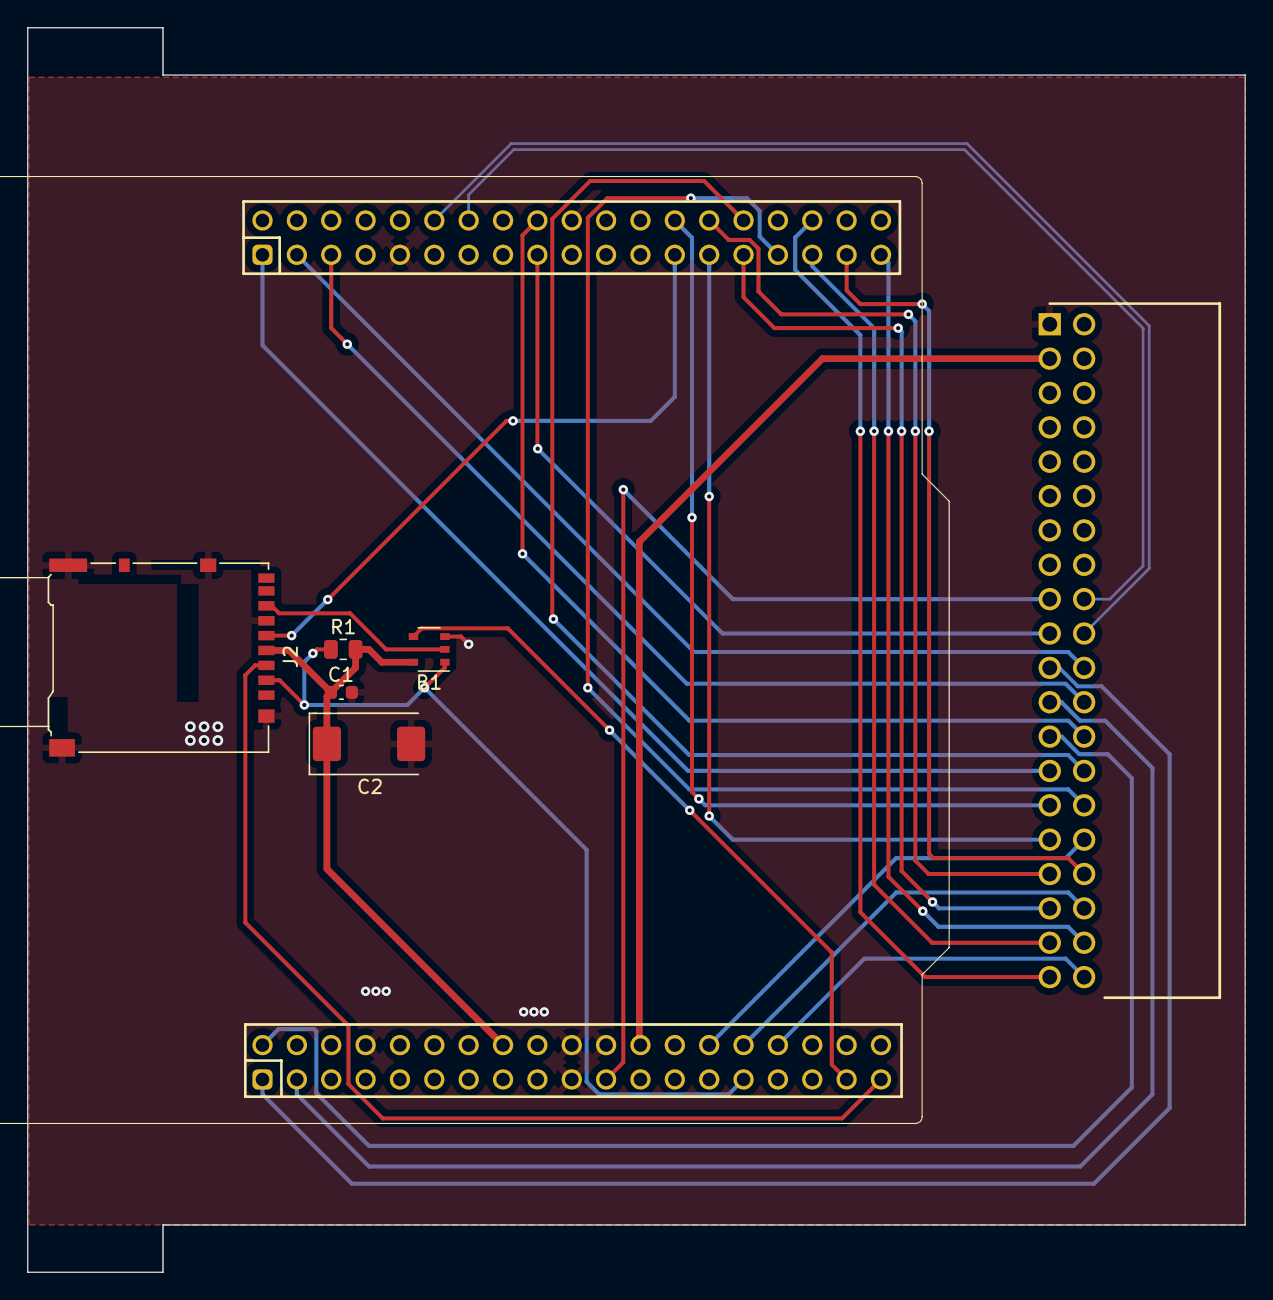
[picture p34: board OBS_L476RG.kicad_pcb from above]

Board: 2 copper layers, 90.0 x 92.0 mm, 7 parts (0 on the bottom side), 32 nets.

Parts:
B1: TSOP-5_1.65x3.05mm_P0.95mm
C1: 0.1uF; C_0603_1608Metric
C2: 47uF; CP_EIA-7343-31_Kemet-D
J1: Bus Standard; flatsat_conn
J2: Micro_SD_Card_Det_Hirose_DM3AT; microSD_HC_Hirose_DM3AT-SF-PEJM5
R1: 10K; R_0805_2012Metric
U2: NUCLEO_L476RG; Nucleo64

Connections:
+3.3V: B1.5 (VCC), C1.1, C2.1, J2.4 (VDD), R1.2, U2.16 (+3V3)
/CAN_rd: J1.22 (RD), U2.41 (PB8)
/CAN_td: J1.24 (TD), U2.43 (PB9)
/CS: B1.1 (OE), J2.2 (DAT3/CD), R1.1, U2.29 (PH0)
/DAT0: B1.2 (A), J2.7 (DAT0)
/MISO: J1.25 (MISO), U2.2 (PC11)
/MOSI: J1.23 (MOSI), U2.3 (PC12)
/P15: J1.29 (AI_1), U2.64 (PB15)
/P16: J1.31 (AI_2), U2.65 (PB4)
/P17: J1.33 (AI_3), U2.66 (PB14)
/P18: J1.35 (AI_4), U2.67 (PB5)
/P19: J1.37 (AI_5), U2.71 (PA10)
/P20: J1.39 (AI_6), U2.72 (PC4)
/P21: J1.40 (PWM_O_6), U2.32 (PA4)
/P22: J1.38 (PWM_O_5), U2.75 (PA3)
/P23: J1.36 (PWM_O_4), U2.30 (PA1)
/P24: J1.34 (PWM_O_3), U2.73 (PA2)
/P25: J1.32 (PWM_O_2), U2.28 (PA0)
/P26: J1.30 (PWM_O_1), U2.69 (PB3)
/SCK: J1.21 (SCK), U2.1 (PC10)
/SCL/TX_1: J1.19 (TX/SCL), U2.55 (PB6)
/SCL/TX_2: J1.28 (SCL/TX), U2.68 (PB13)
/SDA/RX_1: J1.17 (RX/SDA), U2.21 (PB7)
/SDA/RX_2: J1.26 (SDA/RX), U2.56 (PB11)
/SD_MISO: B1.4 (Y), U2.35 (PC2)
/SD_MOSI: J2.3 (CMD), U2.37 (PC3)
/SD_SCK: J2.5 (CLK), U2.63 (PB10)
/SSEL: J1.27 (SSEL), U2.39 (PC9)
/USB_D+: J1.20 (D+), U2.50 (PA12)
/USB_D-: J1.18 (D-), U2.52 (PA11)
/Vin: J1.3 (V_IN), U2.24 (VIN)
GND: B1.3 (GND), C1.2, C2.2, J1.1 (GND), J2.6 (VSS), J2.11 (SHIELD), U2.8 (GND), U2.19 (GND), U2.20 (GND), U2.22 (GND), U2.47 (GND), U2.58 (GND)

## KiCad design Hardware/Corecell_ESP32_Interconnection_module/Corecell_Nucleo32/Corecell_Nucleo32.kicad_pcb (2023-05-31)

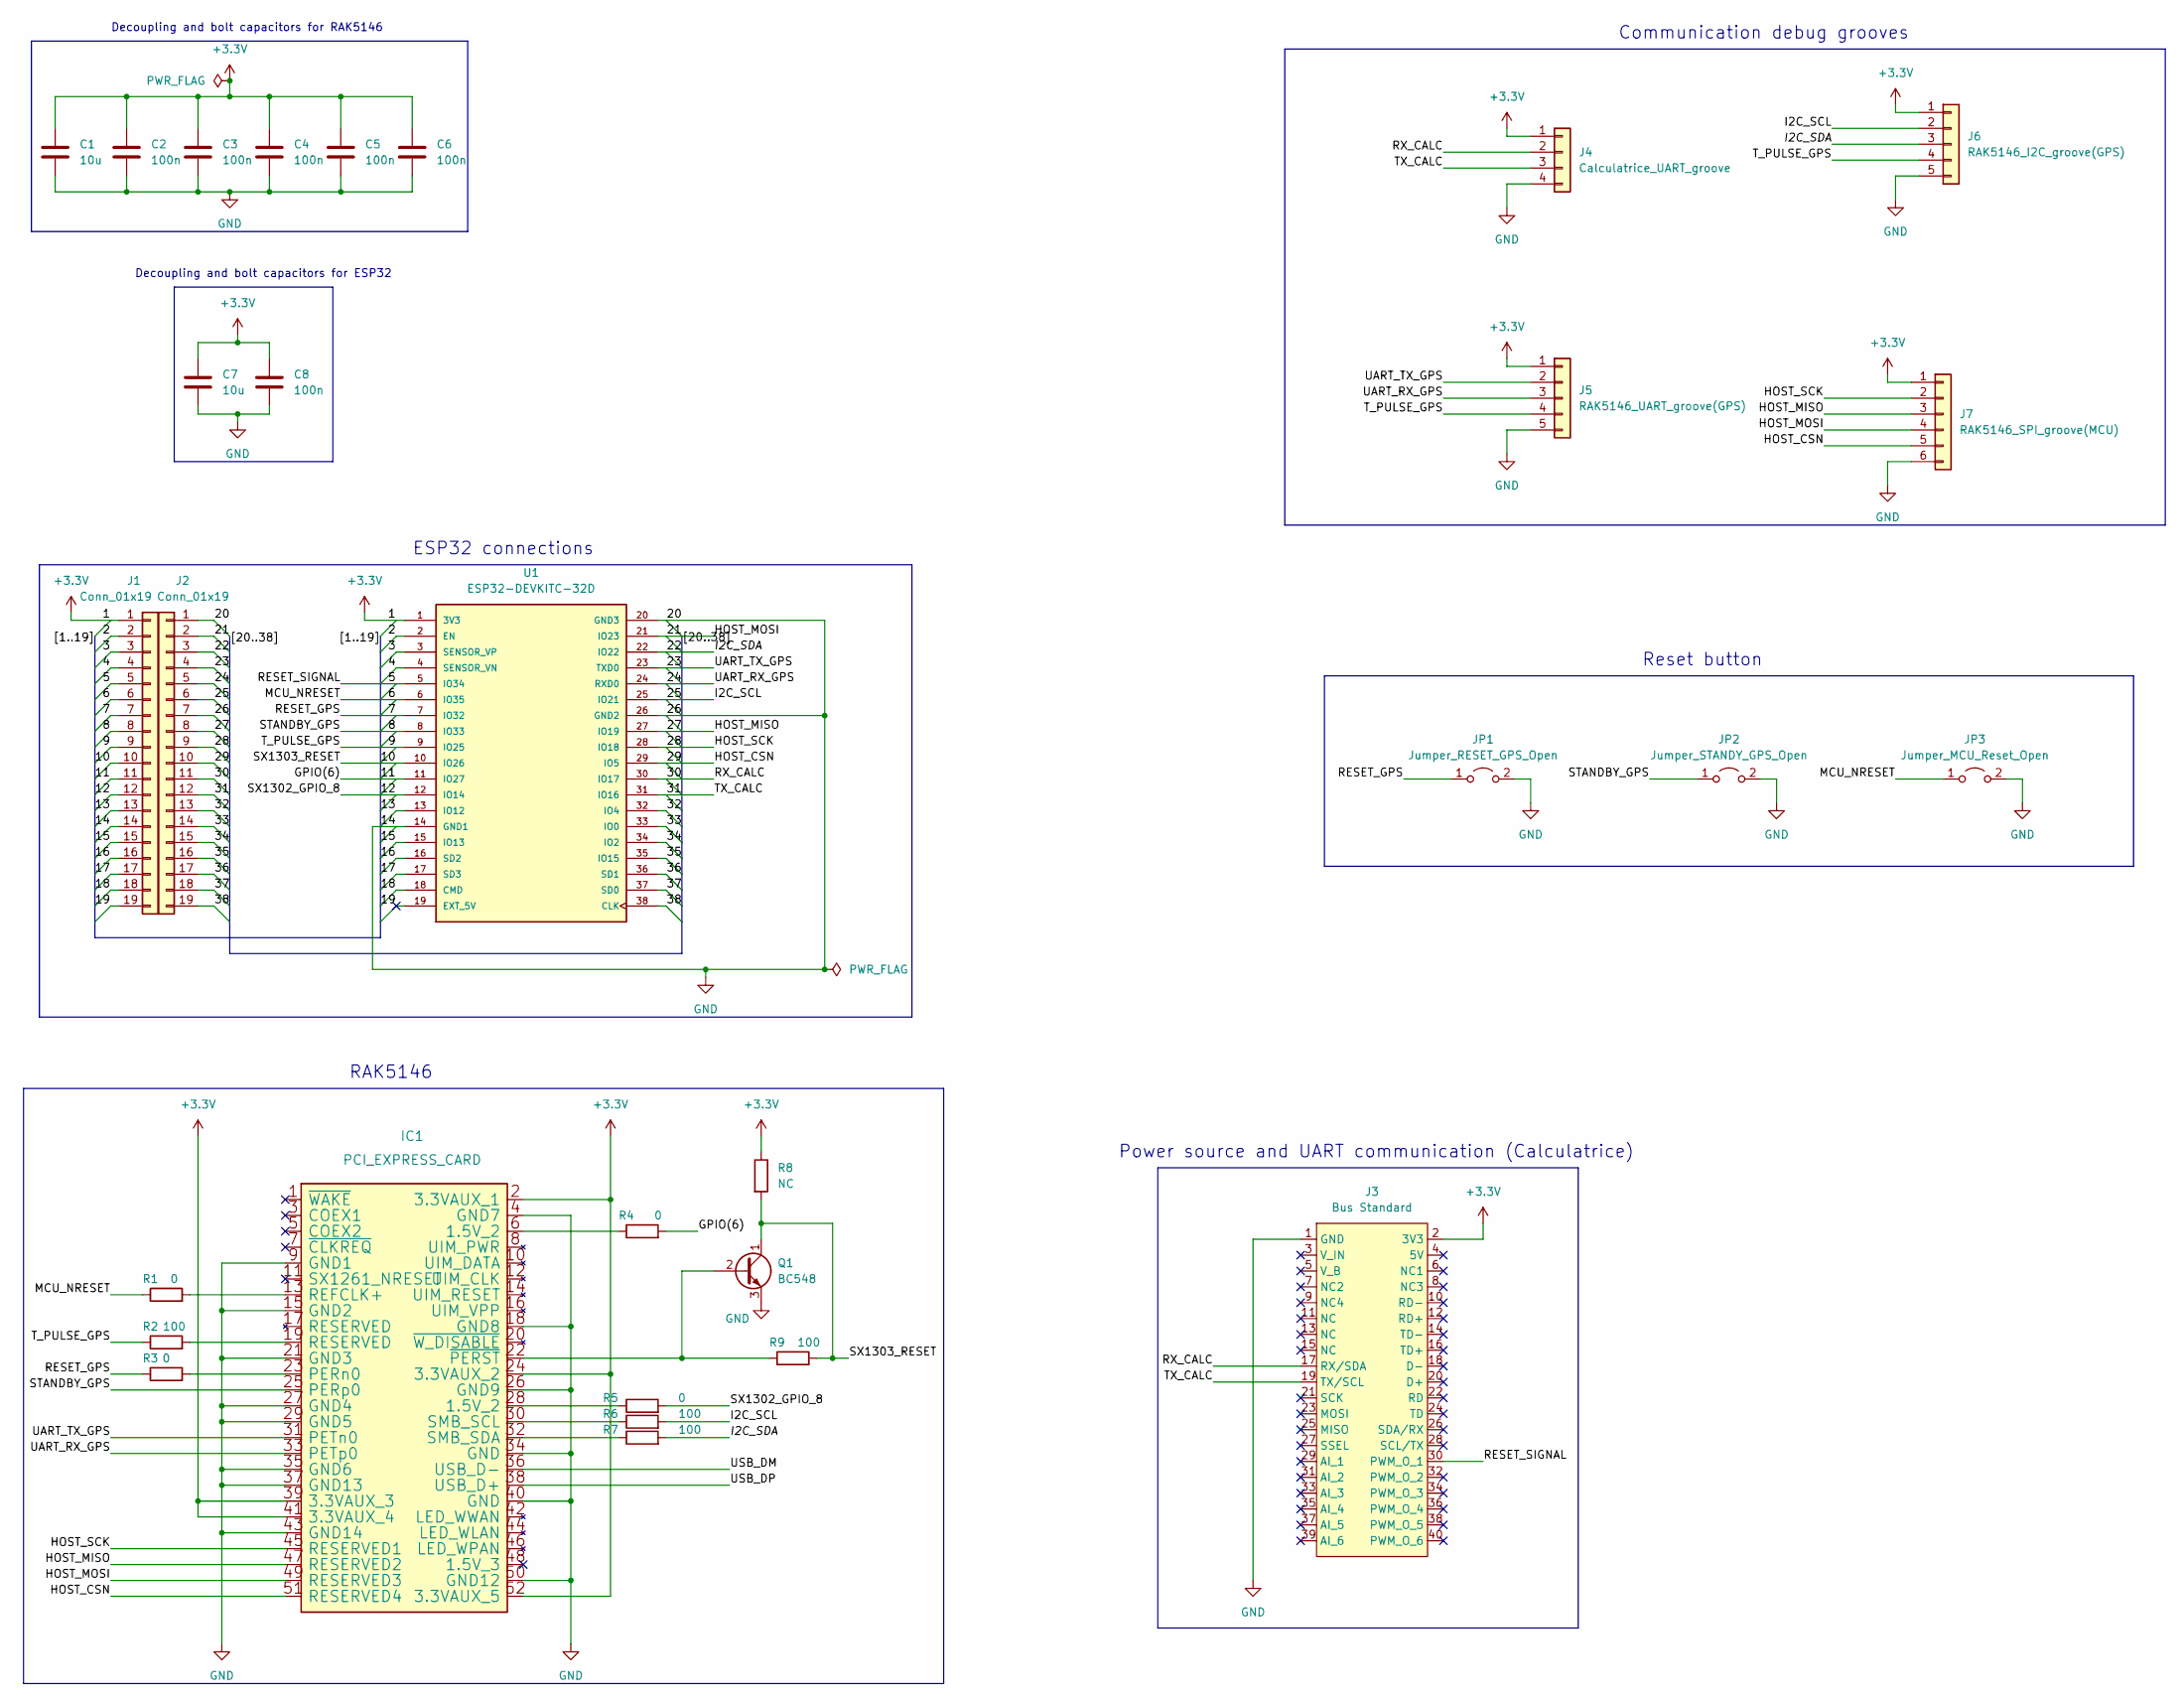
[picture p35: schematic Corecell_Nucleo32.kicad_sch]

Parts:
C1, C7: 10u; C_0603_1608Metric
C2, C3, C4, C5, C6, C8: 100n; C_0402_1005Metric
IC1: PCI_EXPRESS_CARD; BUS_PCI_Express_Mini
J1, J2: Conn_01x19; PinSocket_1x19_P2.54mm_Vertical
J3: Bus Standard; PinHeader_2x20_P2.54mm_Vertical
J4: Calculatrice_UART_groove; PinSocket_1x04_P2.54mm_Vertical
J5: RAK5146_UART_groove(GPS); PinSocket_1x05_P2.54mm_Vertical
J6: RAK5146_I2C_groove(GPS); PinSocket_1x05_P2.54mm_Vertical
J7: RAK5146_SPI_groove(MCU); PinSocket_1x06_P2.54mm_Vertical
JP1: Jumper_RESET_GPS_Open; SW_Push_1P1T_NO_CK_KMR2
JP2: Jumper_STANDY_GPS_Open; SW_Push_1P1T_NO_CK_KMR2
JP3: Jumper_MCU_Reset_Open; SW_Push_1P1T_NO_CK_KMR2
Q1: BC548; TO-92_Inline
R1, R3, R4, R5: 0; R_0402_1005Metric
R2, R6, R7, R9: 100; R_0402_1005Metric
R8: NC; R_0402_1005Metric
U1: ESP32-DEVKITC-32D; MODULE_ESP32-DEVKITC-32D; PARTREV 4

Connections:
+3V3: C1.1, C2.1, C3.1, C4.1, C5.1, C6.1, C7.1, C8.1, IC1.2 (3.3VAUX_1), IC1.24 (3.3VAUX_2), IC1.39 (3.3VAUX_3), IC1.41 (3.3VAUX_4), IC1.52 (3.3VAUX_5), J1.1, J3.2 (3V3), J4.1, J5.1, J6.1, J7.1, R8.1, U1.1 (3V3)
/2: J1.2, U1.2 (EN)
/3: J1.3, U1.3 (SENSOR_VP)
/4: J1.4, U1.4 (SENSOR_VN)
/5: J1.5, J3.30 (PWM_O_1), U1.5 (IO34)
/6: J1.6, JP3.1 (A), R1.1, U1.6 (IO35)
/7: J1.7, JP1.1 (A), R3.1, U1.7 (IO32)
/8: IC1.25 (PERp0), J1.8, JP2.1 (A), U1.8 (IO33)
/9: J1.9, J5.4, J6.4, R2.1, U1.9 (IO25)
/10: J1.10, Q1.1 (C), R8.2, R9.2, U1.10 (IO26)
/11: J1.11, R4.2, U1.11 (IO27)
/12: J1.12, R5.2, U1.12 (IO14)
/13: J1.13, U1.13 (IO12)
/15: J1.15, U1.15 (IO13)
/16: J1.16, U1.16 (SD2)
/17: J1.17, U1.17 (SD3)
/18: J1.18, U1.18 (CMD)
/19: J1.19, U1.19 (EXT_5V)
/21: IC1.49 (RESERVED3), J2.2, J7.4, U1.21 (IO23)
/22: J2.3, J6.3, R7.2, U1.22 (IO22)
/23: IC1.31 (PETn0), J2.4, J5.2, U1.23 (TXD0)
/24: IC1.33 (PETp0), J2.5, J5.3, U1.24 (RXD0)
/25: J2.6, J6.2, R6.2, U1.25 (IO21)
/27: IC1.47 (RESERVED2), J2.8, J7.3, U1.27 (IO19)
/28: IC1.45 (RESERVED1), J2.9, J7.2, U1.28 (IO18)
/29: IC1.51 (RESERVED4), J2.10, J7.5, U1.29 (IO5)
/30: J2.11, J3.17 (RX/SDA), J4.2, U1.30 (IO17)
/31: J2.12, J3.19 (TX/SCL), J4.3, U1.31 (IO16)
/32: J2.13, U1.32 (IO4)
/33: J2.14, U1.33 (IO0)
/34: J2.15, U1.34 (IO2)
/35: J2.16, U1.35 (IO15)
/36: J2.17, U1.36 (SD1)
/37: J2.18, U1.37 (SD0)
/38: J2.19, U1.38 (CLK)
/USB_DM: IC1.36 (USB_D-)
/USB_DP: IC1.38 (USB_D+)
GND: C1.2, C2.2, C3.2, C4.2, C5.2, C6.2, C7.2, C8.2, IC1.4 (GND7), IC1.9 (GND1), IC1.15 (GND2), IC1.18 (GND8), IC1.21 (GND3), IC1.26 (GND9), IC1.27 (GND4), IC1.29 (GND5), IC1.34 (GND), IC1.35 (GND6), IC1.37 (GND13), IC1.40 (GND), IC1.43 (GND14), IC1.50 (GND12), J1.14, J2.1, J2.7, J3.1 (GND), J4.4, J5.5, J6.5, J7.6, JP1.2 (B), JP2.2 (B), JP3.2 (B), Q1.3 (E), U1.14 (GND1), U1.20 (GND3), U1.26 (GND2)
unnamed: IC1.6 (1.5V_2), R4.1
unnamed: IC1.13 (REFCLK+), R1.2
unnamed: IC1.19 (RESERVED), R2.2
unnamed: IC1.22 (~PERST), Q1.2 (B), R9.1
unnamed: IC1.23 (PERn0), R3.2
unnamed: IC1.28 (1.5V_2), R5.1
unnamed: IC1.30 (SMB_SCL), R6.1
unnamed: IC1.32 (SMB_SDA), R7.1

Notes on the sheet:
RAK5146
Decoupling and bolt capacitors for ESP32
ESP32 connections
Power source and UART communication (Calculatrice)
Communication debug grooves
Reset button
Decoupling and bolt capacitors for RAK5146

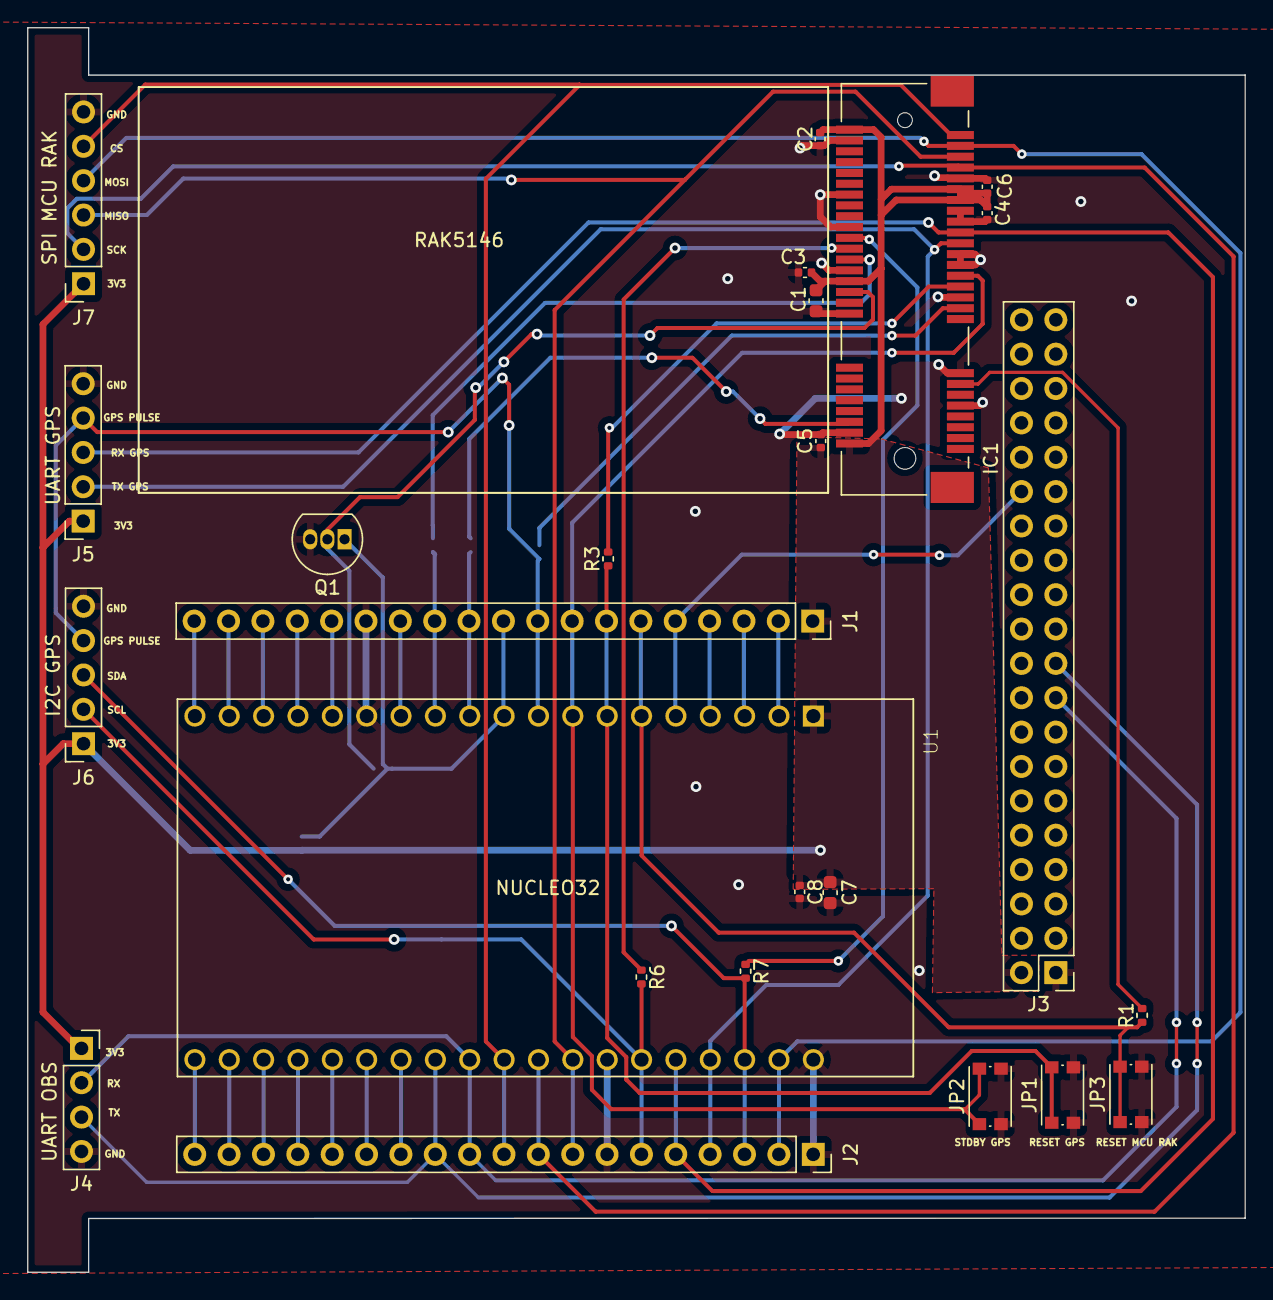
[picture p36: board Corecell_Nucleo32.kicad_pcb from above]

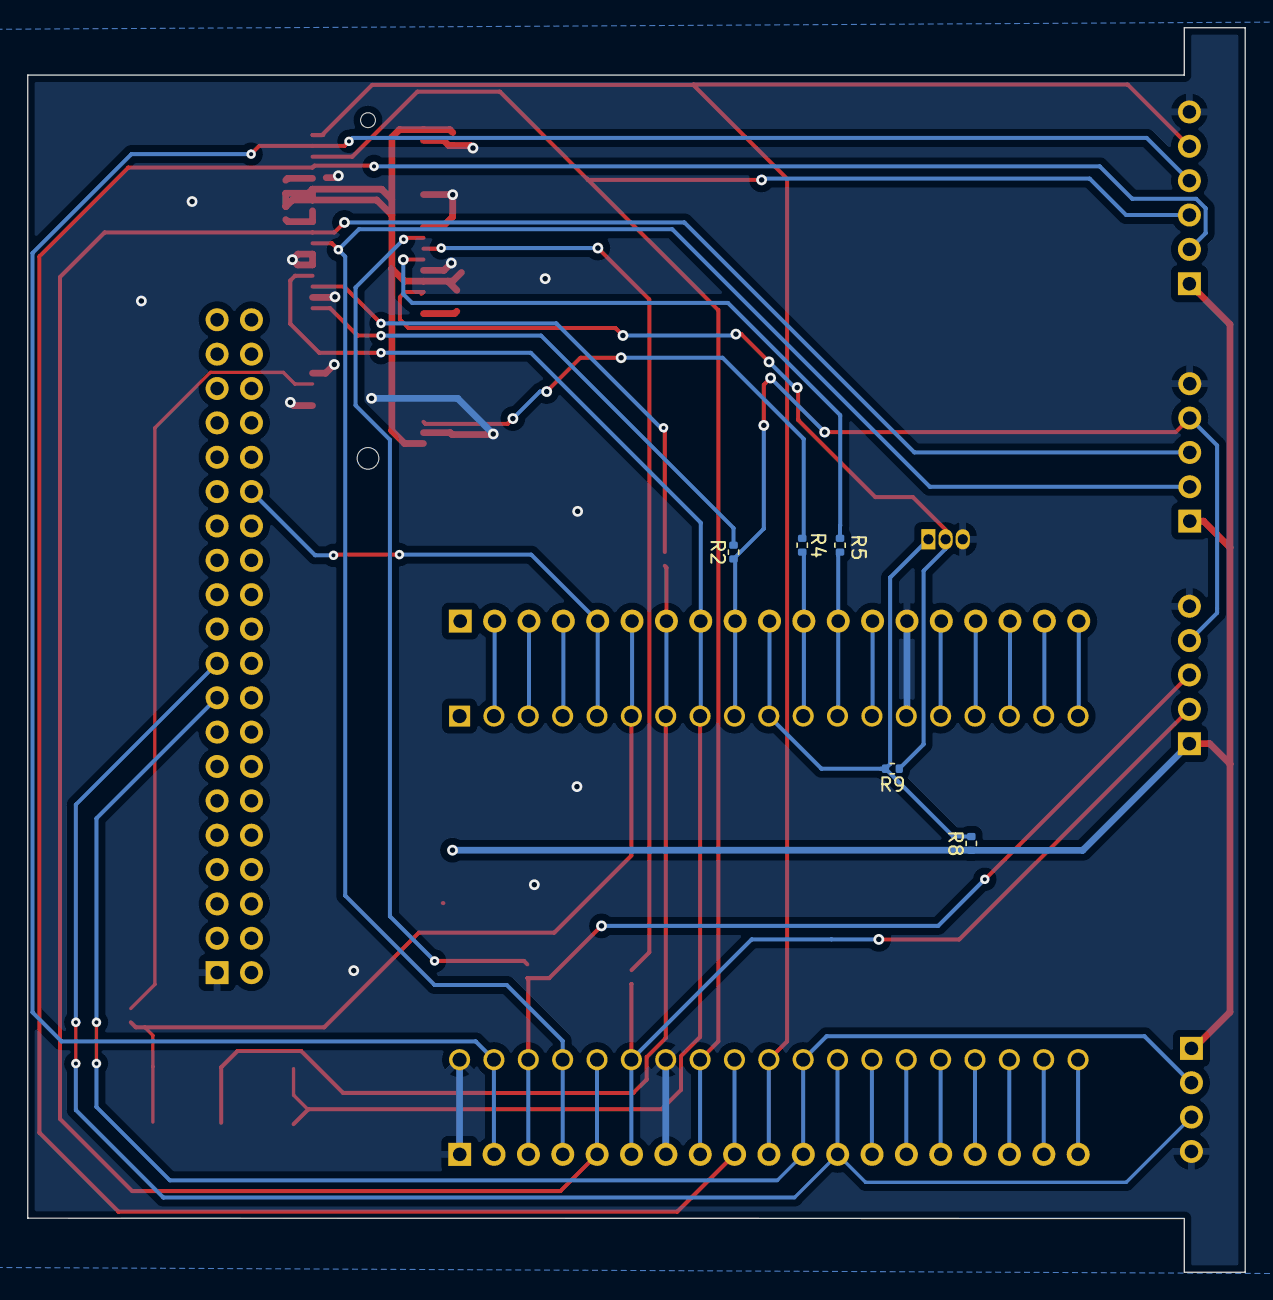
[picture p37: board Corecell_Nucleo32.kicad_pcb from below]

Board: 2 copper layers, 90.0 x 92.0 mm, 30 parts (5 on the bottom side), 44 nets.

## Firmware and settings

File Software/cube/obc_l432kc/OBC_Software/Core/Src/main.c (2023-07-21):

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
/* Includes ------------------------------------------------------------------*/
#include "main.h"

/* USER CODE BEGIN Includes */
#include <Port_Conf.h>
#include "stm32l4xx.h"
#include <stdio.h>

#include "main.h"

#include "I2C.h"
#include "Clocks.h"
#include "code_eleve.h"
#include "PWM.h"
#include "Timer.h"
#include "UART.h"
#include "MPL3115A2.h"
#include "bno055.h"
/* USER CODE END Includes */

LPTIM_HandleTypeDef hlptim1;

TIM_HandleTypeDef htim1;

UART_HandleTypeDef huart2;

void SystemClock_Config(void);
static void MX_GPIO_Init(void);
static void MX_USART2_UART_Init(void);
static void MX_LPTIM1_Init(void);
static void MX_TIM1_Init(void);
/* USER CODE BEGIN PFP */
void __io_putchar(uint8_t ch);

/* USER CODE END PFP */

/* USER CODE BEGIN 0 */

void BNO_write(uint8_t Address, uint8_t *Reg, uint8_t *Data, uint8_t size){
	I2C_Address(Address);
	I2C_Start();
	I2C_Write(Reg, 1);
	I2C_Write(Data, size);
	I2C_Stop();
}

void BNO_read(uint8_t Address, uint8_t *Reg, uint8_t *buffer, uint8_t size){
	I2C_Address(Address);
	I2C_Start();
	I2C_Write(Reg,1);
	I2C_Start(); //repeated start
	I2C_Read(Address, buffer, size);
}
/* USER CODE END 0 */

/**
  * @brief  The application entry point.
  * @retval int
  */
int main(void)
{
  /* USER CODE BEGIN 1 */
	uint8_t buffer[255]=0;
	uint8_t buf[2] = {0x55,0x55};

  /* USER CODE END 1 */

  /* MCU Configuration--------------------------------------------------------*/

  /* Reset of all peripherals, Initializes the Flash interface and the Systick. */
  HAL_Init();

  /* Configure the system clock */
  SystemClock_Config();

  /* USER CODE BEGIN SysInit */

    SetClocks();	//must do a function to set peripherals clocks
  //	InitTimer_1();			//init timer 1


  /* USER CODE END SysInit */

  /* Initialize all configured peripherals */
  MX_GPIO_Init();
  MX_USART2_UART_Init();
  MX_LPTIM1_Init();
  MX_TIM1_Init();
  /* USER CODE BEGIN 2 */

  InitPeripheral();		// Init peripheral I/O's
  I2C_Init();			//init I2C mode

  /* USER CODE END 2 */

  I2C_Write_Adress(MPL3115A2_ADDRESS, &debug, 1);

  /* Infinite loop */
  /* USER CODE BEGIN WHILE */
  while (1)
  {
//	  BNO_read(MPL3115A2_ADDRESS,(uint8_t *) MPL3115A2_WHOAMI , buffer, 1);
//
//	  printf("\n Valor whomai: %x \r\n", *buffer);

    /* USER CODE END WHILE */

    /* USER CODE BEGIN 3 */
  }
  /* USER CODE END 3 */
}

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


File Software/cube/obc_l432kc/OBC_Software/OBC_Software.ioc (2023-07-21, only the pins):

Mcu.UserName=STM32L432KCUx
PA1.Signal=USART2_DE
PA2.GPIO_Label=VCP_TX
PA2.Signal=USART2_TX

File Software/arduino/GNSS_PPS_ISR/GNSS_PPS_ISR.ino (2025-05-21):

/*
 * This example for Thingsat @ INISAT illustrates the PPS of a GNSS module
 */

#define PPS_PIN     A6
#define PPS_LED     13

void setup () {
  Serial.begin(115200);
  
  // Attach an interrupt to interrupt #1, calls program "pps_interrupt", happens on rising (low to high)
  pinMode(PPS_PIN, INPUT_PULLDOWN);
  digitalWrite(PPS_PIN, LOW);
  attachInterrupt(digitalPinToInterrupt(PPS_PIN), pps_interrupt, RISING);

#ifdef PPS_LED
  pinMode(PPS_LED, OUTPUT);
  // Check to make sure LED is working
  digitalWrite(PPS_LED, HIGH);
  delay(1000);
  digitalWrite(PPS_LED, LOW);
#endif

  Serial.print(__DATE__);
  Serial.print(" ");
  Serial.println(__TIME__);
  
}

void loop () {  
  delay(10000);
}

static int cpt = 0;

void pps_interrupt(){
  if(++cpt % 60 == 0) {
    Serial.println();
  }
  Serial.print((char)('0'+(cpt%10)));

#ifdef PPS_LED
  digitalWrite(PPS_LED, HIGH);
  delay(100);
  digitalWrite(PPS_LED, LOW);
#endif
}

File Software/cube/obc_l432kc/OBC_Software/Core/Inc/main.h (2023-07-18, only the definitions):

#define VCP_TX_Pin GPIO_PIN_2
#define VCP_TX_GPIO_Port GPIOA
#define VCP_RX_Pin GPIO_PIN_15
#define VCP_RX_GPIO_Port GPIOA
#define LD3_Pin GPIO_PIN_3
#define LD3_GPIO_Port GPIOB

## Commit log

2023-05-09 J'ajoute deux fichiers, un pour kicad et outre pour les codes. J'ajoute aussi le programme pour tester la carte du calculateur
2023-05-11 Adding the tinygs repo
    [Board_ESP_MikroBus_V1.kicad_pcb, Board_ESP_MikroBus_V1.sch, Board_Mikrobus_Lambda80C.kicad_pcb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]
2023-05-11 Here is a version with the ISA connector standard. The schematic is ready, but the layout needs to be fixed
    [Board_ESP_MikroBus_V1.kicad_pcb, Board_ESP_MikroBus_V1.kicad_sch]
2023-05-12 Uart groove repositioned
    [Board_ESP_MikroBus_V1.kicad_pcb]
2023-05-12 Nothing really changed, just a wire position fixed
2023-05-12 The TinyGS in cubesat standard with ISA communication is done, all the wires are branched. Verification needed to ensure it's functionality and noise/EM immunity
    [Board_ESP_MikroBus_V1.kicad_pcb, Board_ESP_MikroBus_V1.kicad_sch]
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2023-05-15 We need some changes in the PCIe connector
2023-05-15 Some path tables updated
    [Corecell_Nucleo32.kicad_pcb, Corecell_Nucleo32.kicad_sch]
2023-05-16 Some libs were made and added to schematic, the schematic is almost ready, fixing some warnings
    [Corecell_Nucleo32.kicad_sch]
2023-05-17 The base of schematic is completly connected, there is no error, no warning neither by ERC. After some debug connector will be added to give access to some critic connections points, like UART and ot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
    [Corecell_Nucleo32.kicad_sch]
2023-05-17 Communication debug grooves were added. Some reset jumpers also
    [Corecell_Nucleo32.kicad_sch]
2023-05-17 Footprint assignement is done
    [Corecell_Nucleo32.kicad_sch]
2023-05-17 Jumpers for esp32 were changed for splited 1x19.
    [Corecell_Nucleo32.kicad_sch]
2023-05-17 Components still in process of placement
    [Corecell_Nucleo32.kicad_pcb]
2023-05-19 Design changed
    [Corecell_Nucleo32.kicad_pcb]
2023-05-19 Some changes in footprint and capacitors value
    [Corecell_Nucleo32.kicad_pcb, Corecell_Nucleo32.kicad_sch]
2023-05-22 Model is ready. We must revise
    [Corecell_Nucleo32.kicad_pcb]
2023-05-26 Remove TinyGS directory
    [Board_ESP_MikroBus_V1.kicad_pcb, Board_ESP_MikroBus_V1.kicad_sch, Board_ESP_MikroBus_V1.sch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]
2023-05-26 Silk screen is up to date
    [Corecell_Nucleo32.kicad_pcb]
2023-05-30 mechanical dimension adjusted, routes retraced.
    [Corecell_Nucleo32.kicad_pcb]
2023-05-31 The reset jumpers were changed the footprint for a push button.
    [Corecell_Nucleo32.csv, Corecell_Nucleo32.kicad_pcb, Corecell_Nucleo32.kicad_sch]
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2023-06-02 This version of corecell and esp32 has somme errors, like power pins and we need to erase the BC543
    [Corecell_Nucleo32.csv, Corecell_Nucleo32.kicad_pcb, Corecell_Nucleo32.kicad_sch]
2023-06-02 Errors in power source and in BC542
    [Corecell_Nucleo32.csv, Corecell_Nucleo32.kicad_pcb, Corecell_Nucleo32.kicad_sch]
2023-06-02 First commit. The schematic must be revised
    [Com_Nucleo-L432kc.kicad_pcb, Com_Nucleo-L432kc.kicad_sch]
2023-06-05 New itens added to library, such as BUS from flatsat and the schematic of Nucleo.
    [Com_Nucleo-L432kc.kicad_pcb, Corecell_Nucleo32.kicad_sch]
2023-06-06 L9616 in the library. This version we still have the GPS signal. From now on I'll let the main withou the GPS signals, because the sensor cards have already one GPS.
    [Com_Nucleo-L432kc.kicad_sch]
2023-06-06 This version also has no GPS I2C labe, nor USB, that has no prevision for use in this version at least.
    [Com_Nucleo-L432kc.kicad_sch]
2023-06-06 Resistors number fixed. Schematic is ready to start routing. Some power routings are done.
    [Com_Nucleo-L432kc.kicad_pcb, Com_Nucleo-L432kc.kicad_sch]
2023-06-06 Firt commit
    [OBS_L476RG.kicad_pcb, OBS_L476RG.kicad_sch]
2023-06-09 The board is ready. Some verifications required
    [OBS_L476RG.kicad_pcb]
2023-06-12 Project name was wrong in in kicad files. Project renamed
    [Com_Nucleo-L432kc.kicad_sch, OBC_L476RG.kicad_pcb, OBC_L476RG.kicad_sch]
2023-06-12 Differential pair impedance balanced
    [OBC_L476RG.kicad_pcb]
2023-06-12 adding BOM
    [BOM_Carte Calculateur V1.1_2021-10-08.csv, BOM_Carte Calculateur V1.1_2021-10-08.ods]
2023-06-12 Removed ODS file
    [BOM_Carte Calculateur V1.1_2021-10-08.ods]
2023-06-12 BOM changed
    [BOM_Carte Calculateur V1.1_2021-10-08.csv, BOM_Carte Calculateur V1.1_2021-10-08.ods]
2023-06-12 position and gerber files
    [OBC_L476RG-B_Cu.gbr, OBC_L476RG-B_Mask.gbr, OBC_L476RG-B_Paste.gbr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]
2023-06-14 Some libraries were added for NAND gate. Also I2C in mikrobus changed. ROuting started respecting constraints.
    [Com_Nucleo-L432kc.kicad_pcb, Com_Nucleo-L432kc.kicad_sch, OBC_L476RG.kicad_pcb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]
2023-06-15 Traces almost ready, I'm avoiding through holes because it will be done in campus, not with specialized machines. Constraints: 125 um clearence and wire size. It will be not possible completly avoid 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
    [Com_Nucleo-L432kc.kicad_pcb, Com_Nucleo-L432kc.kicad_sch]
2023-06-20 New library joined, cause we changed for a 7404 logic gate. All the routes were re-made.
    [Com_Nucleo-L432kc.csv, Com_Nucleo-L432kc.kicad_pcb, Com_Nucleo-L432kc.kicad_sch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]
2023-06-21 The board is ready, need some revision
    [Com_Nucleo-L432kc.csv, Com_Nucleo-L432kc.kicad_pcb, Com_Nucleo-L432kc.kicad_sch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]
2023-06-27 First version for fabrication
    [Com_Nucleo-L432kc.csv, Com_Nucleo-L432kc.kicad_pcb, Com_Nucleo-L432kc.kicad_sch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]
2023-06-27 TinyGS in 2u format.
    [Board_ESP_MikroBus_V1.kicad_pcb, Board_ESP_MikroBus_V1.kicad_sch, Board_ESP_MikroBus_V1.sch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]
2023-06-30 Selection CAN juper added. Can buffer added
    [Board_ESP_MikroBus_V1.kicad_pcb, Board_ESP_MikroBus_V1.kicad_sch]
2023-07-07 Spreedshit of the I2C timing calculus and registers configuration
    [I2C_CLK.ods]
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2023-07-10 I2C firmware almost ready. Haven't tried to build this code yet. There maybe errors in this code
    [I2C_CLK.ods]
2023-07-18 Flatsat connector was in the wrong side. All the routes were remade.
    [Com_Nucleo-L432kc.kicad_pcb, Com_Nucleo-L432kc.kicad_sch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]
2023-07-18 Flatsat connector was in the wrong side. All routes were remade.
    [Board_ESP_MikroBus_V1.kicad_pcb]
2023-07-18 I2C library has some bugs, but the peripheral library is working fine with clearing masks added.
    [Clocks.c, I2C.c, Port_Conf.c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]
2023-07-21 Final changes and gerber added
    [Board_ESP_MikroBus_V1-B_Cu.gbr, Board_ESP_MikroBus_V1-B_Mask.gbr, Board_ESP_MikroBus_V1-B_Silkscreen.gbr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]
2023-07-21 I2C almost working. The address is working fine, must test the read.
    [I2C_CLK.ods]
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2024-06-24 push leo
    [Com_Nucleo-L432kc.kicad_pcb, Com_Nucleo-L432kc.kicad_sch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]
2024-07-11 correction carte Lucas
    [Com_Nucleo-L432kc.kicad_pcb, Com_Nucleo-L432kc.kicad_sch]
2024-08-01 reprise de la serigraphie
    [Com_Nucleo-L432kc.kicad_pcb]
2024-08-02 peaufinage serigraphie et tracage fichiers de fabrication pour commande JLCPCB
    [Com_Nucleo-L432kc-B_Cu.gbr, Com_Nucleo-L432kc-B_Mask.gbr, Com_Nucleo-L432kc-B_Silkscreen.gbr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]
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2024-10-04 remise au propre du projet avant redesign
    [Com_Nucleo-L432kc-B_Cu.gbr, Com_Nucleo-L432kc-B_Mask.gbr, Com_Nucleo-L432kc-B_Silkscreen.gbr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]
2024-10-04 début de la reprise de la carte
    [Com_Nucleo-L432kc.kicad_sch]
2024-10-07 schématique terminée
    [Com_Nucleo-L432kc.kicad_sch]
2024-10-07 routage terminé
    [Com_Nucleo-L432kc.kicad_pcb, Com_Nucleo-L432kc.kicad_sch]
2024-10-08 ajout documentation
    [Com_Nucleo-L432kc.kicad_pcb, Com_Nucleo-L432kc.kicad_sch, Grove_header_vertical_THT.stp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]
2024-10-08 ajout documentation bis
    [Com_Nucleo-L432kc.kicad_pcb, Com_Nucleo-L432kc.kicad_sch]
2024-10-10 ajout trous entretoise pour support mini PCI Express
    [Com_Nucleo-L432kc.kicad_pcb]
2024-10-14 fix mauvaise empreinte connecteur
    [Com_Nucleo-L432kc.kicad_pcb, Com_Nucleo-L432kc.kicad_sch]
2025-02-06 finalisation Thingsat Inisat v1.0
    [Com_Nucleo-L432kc.csv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]
2025-02-19 add missing files
    [thingsat_inisat-v1_0-06_02_2025.csv, thingsat_inisat-v1_0-06_02_2025.xlsx]
2025-02-20 fix ref to Thingsat @ INISAT 📡 🚀
2025-02-22 rename and move dir
    [Com_Nucleo-L432kc-B_Cu.gbr, Com_Nucleo-L432kc-B_Mask.gbr, Com_Nucleo-L432kc-B_Silkscreen.gbr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]
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

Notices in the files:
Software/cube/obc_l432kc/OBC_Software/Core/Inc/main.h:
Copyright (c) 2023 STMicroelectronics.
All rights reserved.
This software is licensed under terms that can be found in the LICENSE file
